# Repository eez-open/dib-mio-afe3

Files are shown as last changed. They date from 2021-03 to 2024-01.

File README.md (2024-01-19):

### Ownership and License
The contributors are listed in CONTRIB.TXT.

Licenses | OSHWA UID
--|--
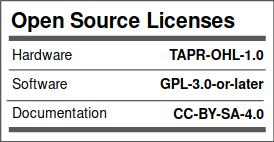
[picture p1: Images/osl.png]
osl
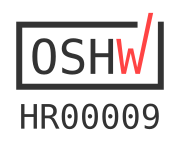
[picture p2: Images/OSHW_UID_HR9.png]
OSHW-HR000009 (https://certification.oshwa.org/hr000009.html)
 | 

### Overview

The [EEZ DIB](https://github.com/eez-open/modular-psu) 4-channel Hi-voltage/Hi-current AFE for [MIO168](https://github.com/eez-open/dib-mio168) module with two isolated inputs for voltage and current measurements.

### Feature list
* [ADS131E04](https://www.ti.com/product/ADS131E04) 24-bit 4-channel simultaneous sampling ADC with SPI
* AIN#1: Hi-voltage isolated (floated) input featuring 2 measurement ranges (±50 V, ±450 V)
* AIN#2: Hi-current isolated (floated) input featuring 2 measurement ranges (±1 A, ±10 A)
* AIN#3: Hi-voltage input featuring 3 measurement ranges (±2.4 V, ±48 V, ±240 V)
* AIN#4: Hi-current input featuring 3 measurement ranges (±24 mA, ±1.2 A, ±10 A), share common GND with AIN#3
* Latching relays for lower continuous power consumption
* Fused current inputs
* On-board ±2.5 V low noise LDOs
* Optional external voltage reference
* Dimensions: 132 x 68.5 mm, 4-layer PCB

### r1B4 prototype 3D model

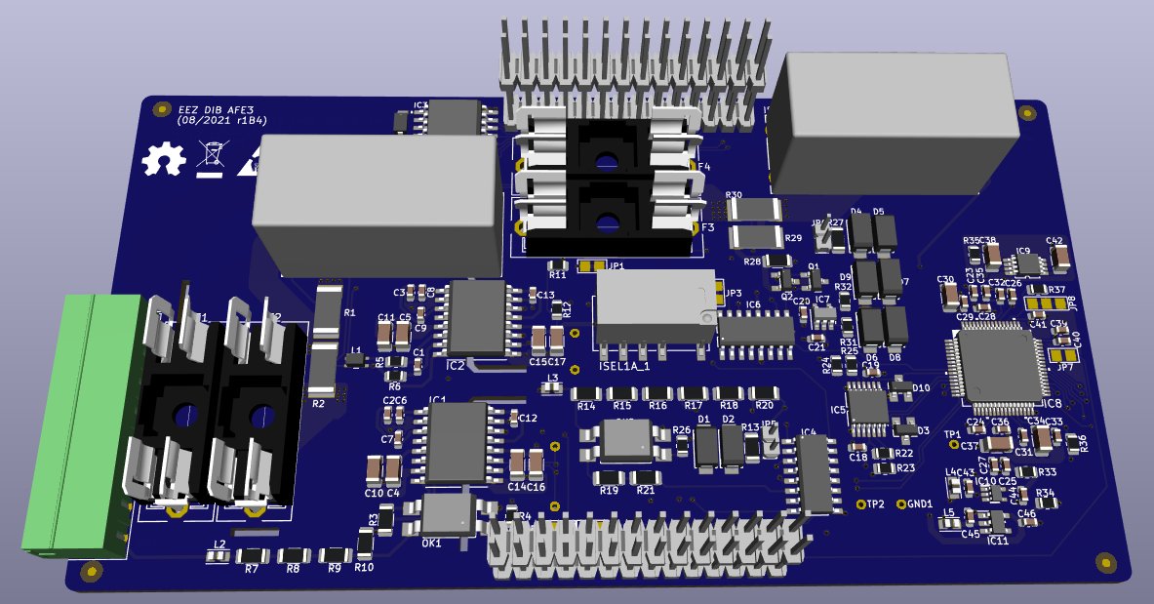
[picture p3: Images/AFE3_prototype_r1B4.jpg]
prototype


### KiCad project (v7 or newer)

* [AFE3 r1B4](https://github.com/eez-open/dib-mio-afe3/tree/master/EDA%20files/KiCad)

All symbols, footprints and 3D models used in the project can be found in the [EEZ-DIB Library](https://github.com/eez-open/eez-kicad-libraries) plugin for KiCad.

### Bill of materials

* [Download](https://github.com/eez-open/dib-mio-afe3/tree/master/EDA%20files/KiCad/bom/ibom.html) as raw file _Interactive BOM_ (ibom.html) and open it locally in your browser.

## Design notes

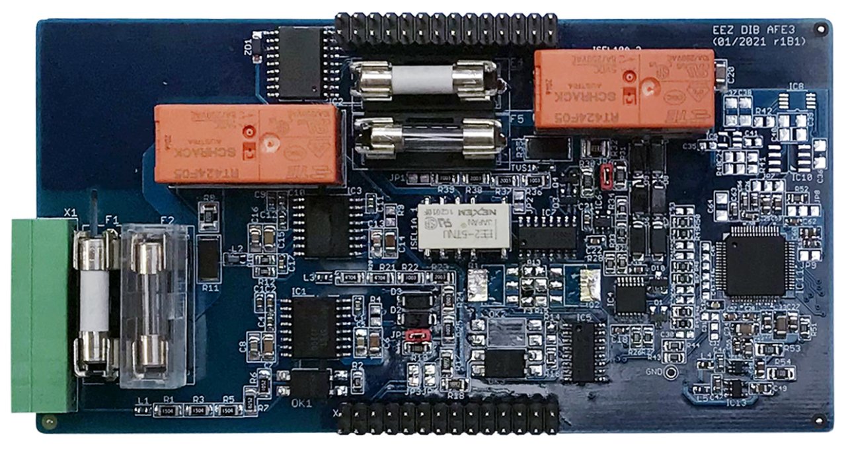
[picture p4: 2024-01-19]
Images/AFE3_prototype_r1B1.jpg

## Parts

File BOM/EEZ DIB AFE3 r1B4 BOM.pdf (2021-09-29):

EEZ DIB AFE3 BOM (r1B4, 2021-05-17)
Project source code at https://github.com/eez-open/modular-psu
Farnell / Element14 # Unit price Qty Part name Package Reference designator Code Part Number MOQ € | Digi-Key Unit price Part Number MOQ € | Mouser Unit price Part Number MOQ €
| | 80-C0603C105K4R
MC0603B822K500 CT | | 603-CC603KRX7R9B B822
| | 80-C0603C102J5RA C
CL21B106KOQNN NE | | 810-CGA4J1X7S1C1 06KA
| | 963-TMK212B7105K G-T
C3, C4, C11, C12, C18, C19, C0603C104K4RAC C21, C22, C26, C28, C46, 7081 C47, C55, C56, C57, C58, C61, C62, C63 | | 80-C0603C104M4R
| | 603-CC121KKX7R8B B226
C1206C102M5RA CTU | | 710-885012208075
| | CL31B105KBHN FNE
C1206C104K5RAC TU | 399-C1206C104K5R AC7800CT-ND | 80-C1206C104K5R ACLR
1 | 2 1u | 0603, 16V | C1, C9 | 3013421 | 0,026 10 | 1276-1019-1-ND | 0,039 | 10 | 0,036 10
2 | 1 8n2 | 0603 | C17 | 1759101 | 0,038 10 | 311-1811-1-ND | 0,060 | 10 | 0,032 10
3 | 2 1n | 0603 | C2, C10 | 2627426 | 0,009 10 | 1276-1018-1-ND | 0,026 | 10 | 0,021 10
4 | 3 10u | 1206 | C20, C34, C64 | 3013485 | 0,262 10 | 1276-2872-1-ND | 0,207 | 10 | 0,144 | 1
5 | 8 1u | 0805 | 2495193 | 885012207078 | 0,139 | 5 | 1276-1066-1-ND | 0,070 | 10 | 0,050 10
6 | 19 100n | 0603 | 2522597 | 0,073 10 | 490-4774-1-ND | 0,090 100 | 0,085 100
7 | 1 22u | 1206 | C33 | 2320935 | 1,490 | 1 | 1276-3373-1-ND | 0,369 | 10 | 0,777 10
8 | 4 1n | 1206, 50V | C5, C8, C13, C16 | 2773295 | 0,059 10 | 732-8115-1-ND | 0,071 | 10 | 0,073 10
9 | 2 1u | 1206, 50V | C6, C14 | 3013524 | 0,144 | 5 | 1276-3091-1-ND | 0,092 | 10 | 0,051 10
10 | 2 100n | 1206, 50V | C7, C15 | 1414715 | 0,053 10 | 0,066 | 10 | 0,045 10
11 | 2 BAV199,235 | D1, D10 | 2319137 | BAV199,215 | 0,185 | 5 | 1727-6382-1-ND | 0,145 | 10 | 771-BAV199235 | 0,146 10
12 | 8 SA2M-E3/61T | SMA | 2335163 | SA2M-E3/61T | 0,261 10 | 0,223 | 10 | 78-CSA2M-E3/H | 0,202 10
13 | 4 ZH32 | F1, F2, F4, F5 | - | - | -
14 | 1 SN005-60 | 1206 | F3 | 3103210 | 1206L005/60WR | 0,771 | 1 | F8129CT-ND | 0,460 | 1 | 0,440 | 1
15 | 1 AMC3330QDWERQ1 | | IC1 | - | | | | | 8,980 | 1 | 9,750 | 1
16 | 1 ADS131E04IPAGR | TQFP-64 | IC11 | 3123346 | ADS131E04IPAG | 13,450 | 1 | 296-34885-1-ND | 7,560 | 1 | 8,430 | 1
17 | 1 TPS71725DCKR | SC70-5 | IC12 | 2348004 | TPS71725DCKR . | 0,982 | 1 | 296-21525-1-ND | 0,890 | 1 | 0,889 | 1
18 | 1 TPS72325DBVR | SOT-23-5 | IC13 | 3007843 | TPS72325DBVR | 2,690 | 1 | 296-39479-1-ND | 2,300 | 1 | 2,310 | 1
19 | 1 ULN2803ADWR | SOIC-18 | IC2 | 3125103 | ULN2803ADWR | 1,120 | 5 | 296-15777-1-ND | 1,090 | 1 | 1,090 | 1
20 | 1 AMC3301DWER | SOIC-16 Wide | IC3 | - | | | | | 9,340 | 1 | 9,220 | 1

CL10B105MO8NN
WC

MC0603B102K250
CT

C23, C25, C27, C48, C49,
C54, C59, C60

MC1210X226K250
CT

CL31B105KBHNN
NE

D2, D3, D4, D5, D6, D7, D8, D9

CSA2M-E3/IGICT-ND
THT; 20x5mm fuse holder
| 576-1206L005/60WR
AMC3330DWER CT-ND | 595-AMC3330DWE
| 595-ADS131E04IPA GR
| 595-TPS71725DCKR
| 595-TPS72325DBVR
| 595-ULN2803ADWR
296-AMC3301QDWE RQ1CT-ND | 595-AMC3301DWER
SOIC-16 Wide | 296-

# Qty Part name | RS Components | TME | Price calculation for 1 set

Unit price Code Part Number MOQ € | Unit price Code / Part Number MOQ € | THT SMD | | Line Cost €

1 2 1u

2 1 8n2

3 2 1n

4 3 10u

5 8 1u

6 19 100n

7 1 22u

8 4 1n

9 2 1u

10 2 100n

11 2 BAV199,235
12 8 SA2M-E3/61T

13 4 ZH32
14 1 SN005-60

15 1 AMC3330QDWERQ1

16 1 ADS131E04IPAGR

17 1 TPS71725DCKR

18 1 TPS72325DBVR

19 1 ULN2803ADWR

20 1 AMC3301DWER

144-7375 | 0,029 100 | CL10B105KO8NNNC | 0,014 100 | 2 | TME | 0,014 € | 2 | 0,027
- | | C0603C822K5RACTU | 0,026 100 | 1 | TME | 0,026 € | 1 | 0,026
135-6565 | 0,014 100 | | 0,010 100 | 2 | Farnell | 0,009 € | 2 | 0,018
184-3969 | 0,233 50 | CL21A106KOQNNNG | 0,034 100 | 3 | TME | 0,034 € | 3 | 0,103
378-665 | 0,038 25 | | 0,014 100 | 8 | TME | 0,014 € | 8 | 0,116
264-4630 | 0,035 25 | CL10B104KA8NNNC | 0,098 100 | 19 | RS | 0,035 € 19 | 0,665
766-1182 | 0,343 10 | CL32A226KAJNNNE | 0,158 10 | 1 | TME | 0,158 € | 1 | 0,158
669-8420 | 0,102 25 | 0,027 100 | 4 | TME | 0,027 € | 4 | 0,110
766-1141 | 0,052 100 | CC1206KKX7R9105 | 0,047 100 | 2 | TME | 0,047 € | 2 | 0,095
391-214 | 0,082 50 | 1206B104K500CT | 0,019 100 | 2 | TME | 0,019 € | 2 | 0,038
751-3437 BAV199DW-7-F | 0,232 25 | BAV199.215 | 0,035 20 | 2 | TME | 0,035 € | 2 | 0,070
812-9275 SA2M-E3/5AT | 0,116 100 | SA2M-E3/61T | 0,050 50 | 8 | TME | 0,050 € | 8 | 0,397
- | ZH32 | 0,228 | 5 | 4 | TME | 0,228 € | 4 | 0,912
- | SN005-60 | 0,075 10 | 1 | TME | 0,075 € | 1 | 0,075
- | | | - | | | 1 | Digikey | 8,980 € | 1 | 8,980
817-5705 | 6,050 | 1 | - | | | 1 | RS | 6,050 € | 1 | 6,050
- | | | - | | | 1 | Mouser | 0,889 € | 1 | 0,889
- | | | - | | | 1 | Digikey | 2,300 € | 1 | 2,300
646-6311 ULN2803ADW | 1,336 | 1 | ULN2803ADWR | 0,866 | 1 | 1 | TME | 0,866 € | 1 | 0,866
- | | | - | | | 1 | Mouser | 9,220 € | 1 | 9,220

Best
Supplier

Lowest
unit price
€

Order
Qty

CGA3E1X7R1C
105M080AC

06031C102KAZ
2A

VJ0603Y102KXACW1 BC

| EMK212BB7106 MG-T
| | VJ0805Y105KXXTW1 BC
| C0603C104K4R ACTU

08052R104K8B
B

CL32A226KAJN
NNE

CC1206KRX7R9
BB102

CL31B102KBCNNNC

CL31B105KBHN
NNF
12065C104KAT
2A

ADS131E04IPA
G

# Qty Part name Package Reference designator Code Part Number MOQ € | Part Number Unit price MOQ € | Part Number Unit price MOQ Unit price €

| | 579-MCP6004T-I/ST
| DG212BDY-T1-E3CT-ND | 781-DG212BDY-T1-E3
| MCP6001RT-I/OTCT-ND | 579-MCP6001RT-I/OT

THT; DPDT Latching relay

21 | 1 MCP6004T-I/ST | TSSOP-14 | IC4 | - | | | | - | | | | 0,373 | 1
22 | 2 DG212BDY-T1-E3 | SOIC-16 | IC5, IC7 | 1469429 | DG212BDY-T1-E3 | 1,820 | 1 | | 1,550 | 1 | | 1,470 | 1
23 | 1 MCP6001RT-I/OT | SOT-23-5 | IC6 | 8540829 | MCP6001RT-I/OT | 0,219 | 1 | | 0,200 | 1 | | 0,203 | 1
24 | 2 RT424F05 | | ISEL10A_1, ISEL10A_2 | 3406968 | RT424F05 | 6,450 | 1 | PB2024-ND | 6,370 | 1 | 655-5-1393243-2 | 6,380 | 1
25 | 1 EE2-5TNU-L | | ISEL1A_1 | 2360813 | EE2-5TNU-L | 1,900 | 1 | 399-11021-1-ND | 2,110 | 1 | 80-EE2-5TNU-L | 2,120 | 1
26 | 2 MLZ1608N100LT000 | 0603 | L1, L3 | 2564062 | 0,167 10 | 445-6755-1-ND | 0,111 | 10 | 0,086 10
27 | 1 DLW21SN371SQ2L | 0805 | L2 | - | 490-5141-1-ND | 0,410 | 10 | 0,484 10
28 | 2 BLM18AG102SH1D | 0603 | L1, L2 | 3471092 | 0,032 10 | 490-7809-1-ND | 0,070 | 10 | 0,051 10
29 | 3 VOR1142B4 | SMD DIP-4 | OK1, OK2, OK3 | 2889672 | VOR1142B4 | 1,660 | 1 | VOR1142B4-ND | 1,420 | 1 | 78-VOR1142B4 | 1,420 | 1
30 | 2 CPC3902ZTR | SOT-223 | Q1, Q2 | - | | | | CLA4156-1-ND | 0,570 | 1 | | 0,576 | 1
31 | 2 BSS214NH6327XTSA1 SOT-23 | Q3, Q4 | 2480650 | 0,408 | 5 | 0,255 | 10 | 0,224 10
32 | 3 1M5 0.1% | 1206 R1, R3, R5 | - | 0,351 | 10 | 0,263 10
33 | 5 10R | 0805 | R10, R12, R13, R53, R54 | 2447556 | 0,009 10 | 0,029 | 10 | 0,012 10
34 | 2 GMR100HTBFA10L0 | | R11, R35 | 2808330 | | 1,130 | 5 | 511-1686-1-ND | 1,350 | 1 | | 1,080 | 1
35 | 1 20R | R15 | - | 311-2930-1-ND | 0,202 | 10 | 0,257 10
36 | 2 49K9 | 1206 | R17, R18 | 2908458 | 0,040 10 | 0,068 | 10 | 0,013 10
37 | 3 100K | 1206 | R19, R31, R36 | 2447551 | 0,010 10 | 0,024 | 10 | 0,040 10
38 | 3 470R | 0805 | R2, R14, R16 | 1099798 | WCR0805-470RFI | 0,019 10 | 0,039 | 10 | 0,041 10
39 | 2 4M7 0.1% | 1206 | R20, R21 | - | 408-2037-1-ND | 0,413 | 10 | 0,356 10
40 | 3 100K 0.1% | 1206 | R22, R25, R39 | 1717738 | ERA8AEB101V | 0,482 10 | 0,346 | 10 | 0,226 10
41 | 4 200K 0.1% | 1206 | R23, R24, R37, R38 | 1841801 | ERA8AEB204V | 0,468 10 | 0,355 | 10 | 0,226 10

DPDT Latching relay, Gull
Wing Lead
MLZ1608N100LT0 00 | 810-MLZ1608N100LT 000
| 81-DLW21SN371SQ 2L
BLM18AG102SH1 D | 81-BLM18AG102SH 1D
| | 849-CPC3902ZTR
| BSS214NH6327 XTSA1CT-ND | 726-BSS214NH6327
| RG3216P-1504-B-T1 | 754-RG3216P-1504B-T1
| 2019-RK73H2ATTD10 R0FCT-ND | 652-CR0805FX-10R0ELF
2512, low TCR (max. GMR100HTBFA10 ±25ppm/°C) L0 | | 755-GMR100HTBFA1 0L0
| | 652-CRT1206BY20R 0ELF
CR1206-FX-4992ELF | RNCP1206FTD4 9K9CT-ND | 791-MR12X4992FTL
| RMCF0805FT10 0KCT-ND | 71-CRCW0805100K FKEAC
| 311-470CRCT-ND | 71-CRCW0805470R FKEB
| | 754-RG3216P-4704B-T1
| RG32P100KBCT -ND | 754-RG3216P-1003-BT5

BSS214NH6327XT
SA1

MCWR08X10R0FT
L

1206, low TCR (max.
±25ppm/°C)

MCWR08X1003FT
L

RG32P200KBCT
-ND

754-RG3216P-2003-BT5

# Qty Part name

21 1 MCP6004T-I/ST

22 2 DG212BDY-T1-E3

23 1 MCP6001RT-I/OT

24 2 RT424F05
25 1 EE2-5TNU-L

26 2 MLZ1608N100LT000

27 1 DLW21SN371SQ2L

28 2 BLM18AG102SH1D

29 3 VOR1142B4
30 2 CPC3902ZTR

31 2 BSS214NH6327XTSA1

32 3 1M5 0.1%

33 5 10R

34 2 GMR100HTBFA10L0

35 1 20R

36 2 49K9

37 3 100K

38 3 470R

39 2 4M7 0.1%

40 3 100K 0.1%

41 4 200K 0.1%

Code Part Number MOQ € | Code / Part Number Unit price MOQ € | THT SMD | Line Cost € Unit price

Best
Supplier

Lowest
unit price
€

Order
Qty
- | - | 1 | Mouser | 0,373 € | 1 | 0,373
710-4780 | 1,630 | 5 | - | 2 | Mouser | 1,470 € | 2 | 2,940
667-4335 | 0,203 20 | MCP6001RT-I/OT | 0,172 10 | 1 | TME | 0,172 € | 1 | 0,172
164-7553 RT424F05 | 6,485 | 1 | 5-1393243-2 | 2,500 | 2 | 2 | TME | 2,500 € | 2 | 5,000
870-5517 EE2-5TNU-L | 1,987 | 1 | - | 1 | Farnell | 1,900 € | 1 | 1,900
- | - | 2 | Mouser | 0,086 € | 2 | 0,172
724-1674 | 0,490 10 | DLW21SN371SQ2L | 0,234 10 | 1 | TME | 0,234 € | 1 | 0,234
839-0803 | 0,025 100 | BLM18AG102SH1D | 0,016 50 | 2 | TME | 0,016 € | 2 | 0,031
180-7266 VOR1142B4 | 1,416 | 5 | - | 3 | RS | 1,416 € | 3 | 4,248
- | CPC3902ZTR | 0,310 | 5 | 2 | TME | 0,310 € | 2 | 0,620
827-0058 | 0,107 100 | 0,070 10 | 2 | TME | 0,070 € | 2 | 0,140
- | - | 3 | Mouser | 0,263 € | 3 | 0,789
740-8987 | 0,065 50 | 0805S8J0111T5E | 0,013 100 | 5 | Farnell | 0,009 € | 5 | 0,043
- | - | 2 | Mouser | 1,080 € | 2 | 2,160
- | - | 1 | Digikey | 0,202 € | 1 | 0,202
679-2174 | 0,039 50 | RC1206FR-0749K9 | 0,029 100 | 2 | Mouser | 0,013 € | 2 | 0,026
223-0691 CRG0805F100K | 0,028 50 | 0805S8F1003T5E | 0,015 100 | 3 | Farnell | 0,010 € | 3 | 0,029
223-0376 CRG0805F470R | 0,021 50 | RC0805FR-07470R | 0,022 100 | 3 | Farnell | 0,019 € | 3 | 0,057
- | - | 2 | Mouser | 0,356 € | 2 | 0,712
669-6626 ERA8AEB104V | 0,608 | 5 | AR06BTCV1003 | 0,127 10 | 3 | TME | 0,127 € | 3 | 0,380
828-0715 ERA8AEB204V | 0,608 | 5 | AR06BTCV2003 | 0,127 10 | 4 | TME | 0,127 € | 4 | 0,506

DG212BDY-T1-
E3
MCP6001RT-I/OT

DLW21SN371S
Q2L

BLM18AG102S
H1D

BSS214NH6327
XTSA1

BSS214NH6327XTSA
1

CR0805-FX-10R0ELF

CRCW120649K
9FKEA

# Qty Part name Package Reference designator Code Part Number MOQ € | Part Number Unit price MOQ € | Part Number Unit price MOQ Unit price €

MCWR08X3300FT L | | 279-CRGCQ0805F33 0R
| 311-10.0KCRCT-ND | 603-RC0805FR-0710KL
1206, low TCR (max. ±25ppm/°C) | 13-RT1206BRD073 3RLCT-ND | 603-RT1206BRD073 3RL
| RC0805FR-071KL | 603-RC0805FR-071KL
MCWF12R1052BT L | | 754-RG3216P-1052-BT5
| RQ73C2B82K5B TD | 754-RG3216P-8252-BT5
2512, low TCR (max. ±25ppm/°C) | | 755-GMR100HTBFIR 022
| | 771-PESD12VL1BA-T/R
THT, 8-pin 3.81mm terminal block header, male pins | | 710-691322310008
42 | 2 330R | 0805 | R26, R29 | 2447638 | 0,007 10 | A106061CT-ND | 0,038 | 10 | 0,036 10
43 | 5 10K | 0805 | R27, R28, R33, R51, R52 | 9237755 | 0,022 10 | 0,039 | 10 | 0,014 10
44 | 1 33R | | R30 | - | | | | 0,393 | 10 | 0,266 10
45 | 1 1K | R34 | 1099800 | WCR0805-1K0FI | 0,019 10 | 0,039 | 10 | 0,015 10
46 | 1 10K5 0.1% | 1206 | R6 | 2338266 | 0,249 10 | A140954CT-ND | 0,621 | 10 | 0,226 10
47 | 1 82K5 0.1% | 1206 | R7 | 2338651 | 0,249 10 | 0,621 | 10 | 0,226 10
48 | 2 GMR100HTBFIR022 | R8, R32 | - | 511-1688-1-ND | 1,090 | 10 | 1,250 | 1
49 | 1 PESD12VL1BA,115 | SOD-323 | TVS1 | 8737363 | 0,365 | 5 | 1727-3808-1-ND | 0,320 | 10 | 0,296 10
50 | 1 691322310008 | X1 | - | 732-2093-ND | 1,390 | 1 | 1,400 | 1
51 | 2 P125-2214A0BS230A1 | X2, X3 | - | - | -
52 | 1 MMSZ5230BT1G | SOD-123 | ZD1 | 1431272 | MMSZ5230BT1G | 0,177 10 | 0,148 | 10 | 0,170 10

Not installed
2 N.C. | 1206 | C24, C35
1 N.C. | IC8
1 N.C. | SOT-23-5 | IC9
5 N.C. | R-EU_R0805 | R4, R9, R40, R41, R42

Related parts and accessories
2 ZKSS-10A
2 ZKSS-1.25A
2 DS1025-01-1*2P8BV1-B THT; | JP5, JP6 | - | - | -
2 JUMPER-2.0/R | JP5, JP6 | - | - | -
1 691304100008 | - | 277-12329-ND | 7,410 | 1 | 651-1748037 | 7,440 | 1

Custom made components
1 | JLCPCB.com | -

RC0805FR-0710KL

MCWF12R8252BT
L

PESD12VL1BA,11
5

THT; 28-pin 0.1” board-toboard (Producer: DONG
GUAN YLIES PRECISE
CONNECTOR CO.,LTD)
MMSZ5230BT1G
OSCT-ND

863-
MMSZ5230BT1G

8-pin 3.81mm push-in
connector

PCB 4-layer 141.5 x 68.5
mm

# Qty Part name

42 2 330R

43 5 10K

44 1 33R

45 1 1K

46 1 10K5 0.1%

47 1 82K5 0.1%

48 2 GMR100HTBFIR022

49 1 PESD12VL1BA,115

50 1 691322310008

51 2 P125-2214A0BS230A1

52 1 MMSZ5230BT1G

Not installed
2 N.C.
1 N.C.
1 N.C.
5 N.C.

Related parts and accessories 2 ZKSS-10A
2 ZKSS-1.25A
2 DS1025-01-1*2P8BV1-B
2 JUMPER-2.0/R
1 691304100008

Custom made components
1 PCB 4-layer 141.5 x 68.5 mm
Code Part Number MOQ € | Code / Part Number Unit price MOQ € | THT SMD | Line Cost € Unit price

Best
Supplier

Lowest
unit price
€

Order
Qty
223-0354 CRG0805F330R | 0,040 50 | 0805S8F3300T5E | 0,014 100 | 2 | Farnell | 0,007 € | 2 | 0,014
125-1189 CRG0805F10K | 0,002 100 | RC0805FR-0710K | 0,022 100 | 5 | RS | 0,002 € | 5 | 0,010
- | AR06BTCV0330 | 0,132 10 | 1 | TME | 0,132 € | 1 | 0,132
223-0427 CRG0805F1K0 | 0,017 50 | RC0805FR-071K | 0,022 100 | 1 | Mouser | 0,015 € | 1 | 0,015
- | - | 1 | Mouser | 0,226 € | 1 | 0,226
- | - | 1 | Mouser | 0,226 € | 1 | 0,226
- | - | 2 | Digikey | 1,090 € | 2 | 2,180
508-024 | 0,294 20 | PESD12VL1BA.115 | 0,126 | 5 | 1 | TME | 0,126 € | 1 | 0,126
824-6661 691322310008 | 1,470 | 1 | 15EDGRC3.81-08P | 0,662 | 1 | 1 | TME | 0,662 € | 1 | 0,662
- | - | 2 | -
545-3033 | 0,173 20 | MMSZ5230BT1G | 0,033 25 | 1 | TME | 0,033 € | 1 | 0,033
9 | 77 | 55,47 €
| ZKSS-10A | 0,459 10 | | TME | 0,459 € | 2 | 0,918
| ZKSS-1.25A | 0,312 10 | | TME | 0,312 € | 2 | 0,624
- | ZL303-02P | 0,013 50 | 2 | TME | 0,013 € | 2 | 0,025
- | JUMPER-2.0/R | 0,044 20 | | TME | 0,044 € | 2 | 0,087
185-4361 691304100008 | 8,900 | 1 | Digikey | 7,410 € | 1 | 7,410
| | | | | | | 9,06 €
JLCPCB | 8,796 € | 1 | 8,796
| | | 8,80 €

PESD12VL1BA,
115

MMSZ5230BT1
G

Qty | Part name | Package | Reference designator | Code | Part Number | MOQ | Part Number | MOQ | Part Number | MOQ Unit price
€

Unit price
€

Unit price
€

All prices are net prices (without VAT)

All resistors are 1% 0805 and all capacitors are X7R 0805 if not otherwise specified.
For small quantities, consider ordering specialized chips at store.ti.com for better prices and availability.

Please note that BOM does not contain ordering number for parts on reels or that which includes re-reeling fee. Take also into account that total cost is higher because min. quantity (MOQ) for many parts is larger then what is needed for single unit.

# Qty Part name

Code Part Number MOQ € | Code / Part Number Unit price MOQ € | THT SMD | Line Cost € Unit price

Best
Supplier

Lowest
unit price
€

Order
Qty

Total 73,33 €

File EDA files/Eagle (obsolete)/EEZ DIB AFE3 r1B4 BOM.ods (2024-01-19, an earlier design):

 |  |  |  |  | Farnell / Element14 |  |  |  | Digi-Key |  |  | Mouser |  |  | RS Components |  |  |  | TME |  |  |  |  | Price calculation for 1 set
# | Qty | Part name | Package | Reference designator | Code | Part Number | Unit price € | MOQ | Part Number | Unit price € | MOQ | Part Number | Unit price € | MOQ | Code | Part Number | Unit price € | MOQ | Code / Part Number | Unit price € | MOQ | THT | SMD | Best Supplier | Lowest unit price € | Order Qty | Line Cost €
1 | 2 | 1u | 0603, 16V | C1, C9 | 3013421 | CL10B105MO8NNWC | 0,026 | 10 | 1276-1019-1-ND | 0,039 | 10 | 80-C0603C105K4R | 0,036 | 10 | 144-7375 | CGA3E1X7R1C105M080AC | 0,029 | 100 | CL10B105KO8NNNC | 0,014 | 100 |  | 2 | TME | 0,014 € | 2 | 0,027
2 | 1 | 8n2 | 0603 | C17 | 1759101 | MC0603B822K500CT | 0,038 | 10 | 311-1811-1-ND | 0,060 | 10 | 603-CC603KRX7R9BB822 | 0,032 | 10 | - |  |  |  | C0603C822K5RACTU | 0,026 | 100 |  | 1 | TME | 0,026 € | 1 | 0,026
3 | 2 | 1n | 0603 | C2, C10 | 2627426 | MC0603B102K250CT | 0,009 | 10 | 1276-1018-1-ND | 0,026 | 10 | 80-C0603C102J5RAC | 0,021 | 10 | 135-6565 | 06031C102KAZ2A | 0,014 | 100 | VJ0603Y102KXACW1BC | 0,010 | 100 |  | 2 | Farnell | 0,009 € | 2 | 0,018
4 | 3 | 10u | 1206 | C20, C34, C64 | 3013485 | CL21B106KOQNNNE | 0,262 | 10 | 1276-2872-1-ND | 0,207 | 10 | 810-CGA4J1X7S1C106KA | 0,144 | 1 | 184-3969 | EMK212BB7106MG-T | 0,233 | 50 | CL21A106KOQNNNG | 0,034 | 100 |  | 3 | TME | 0,034 € | 3 | 0,103
5 | 8 | 1u | 0805 | C23, C25, C27, C48, C49, C54, C59, C60 | 2495193 | 885012207078 | 0,139 | 5 | 1276-1066-1-ND | 0,070 | 10 | 963-TMK212B7105KG-T | 0,050 | 10 | 378-665 | 08052R104K8BB | 0,038 | 25 | VJ0805Y105KXXTW1BC | 0,014 | 100 |  | 8 | TME | 0,014 € | 8 | 0,116
6 | 19 | 100n | 0603 | C3, C4, C11, C12, C18, C19, C21, C22, C26, C28, C46, C47, C55, C56, C57, C58, C61, C62, C63 | 2522597 | C0603C104K4RAC7081 | 0,073 | 10 | 490-4774-1-ND | 0,090 | 100 | 80-C0603C104M4R | 0,085 | 100 | 264-4630 | C0603C104K4RACTU | 0,035 | 25 | CL10B104KA8NNNC | 0,098 | 100 |  | 19 | RS | 0,035 € | 19 | 0,665
7 | 1 | 22u | 1206 | C33 | 2320935 | MC1210X226K250CT | 1,490 | 1 | 1276-3373-1-ND | 0,369 | 10 | 603-CC121KKX7R8BB226 | 0,777 | 10 | 766-1182 | CL32A226KAJNNNE | 0,343 | 10 | CL32A226KAJNNNE | 0,158 | 10 |  | 1 | TME | 0,158 € | 1 | 0,158
8 | 4 | 1n | 1206, 50V | C5, C8, C13, C16 | 2773295 | C1206C102M5RACTU | 0,059 | 10 | 732-8115-1-ND | 0,071 | 10 | 710-885012208075 | 0,073 | 10 | 669-8420 | CC1206KRX7R9BB102 | 0,102 | 25 | CL31B102KBCNNNC | 0,027 | 100 |  | 4 | TME | 0,027 € | 4 | 0,110
9 | 2 | 1u | 1206, 50V | C6, C14 | 3013524 | CL31B105KBHNNNE | 0,144 | 5 | 1276-3091-1-ND | 0,092 | 10 | CL31B105KBHNFNE | 0,051 | 10 | 766-1141 | CL31B105KBHNNNF | 0,052 | 100 | CC1206KKX7R9105 | 0,047 | 100 |  | 2 | TME | 0,047 € | 2 | 0,095
10 | 2 | 100n | 1206, 50V | C7, C15 | 1414715 | C1206C104K5RACTU | 0,053 | 10 | 399-C1206C104K5RAC7800CT-ND | 0,066 | 10 | 80-C1206C104K5RACLR | 0,045 | 10 | 391-214 | 12065C104KAT2A | 0,082 | 50 | 1206B104K500CT | 0,019 | 100 |  | 2 | TME | 0,019 € | 2 | 0,038
11 | 2 | BAV199,235 |  | D1, D10 | 2319137 | BAV199,215 | 0,185 | 5 | 1727-6382-1-ND | 0,145 | 10 | 771-BAV199235 | 0,146 | 10 | 751-3437 | BAV199DW-7-F | 0,232 | 25 | BAV199.215 | 0,035 | 20 |  | 2 | TME | 0,035 € | 2 | 0,070
12 | 8 | SA2M-E3/61T | SMA | D2, D3, D4, D5, D6, D7, D8, D9 | 2335163 | SA2M-E3/61T | 0,261 | 10 | CSA2M-E3/IGICT-ND | 0,223 | 10 | 78-CSA2M-E3/H | 0,202 | 10 | 812-9275 | SA2M-E3/5AT | 0,116 | 100 | SA2M-E3/61T | 0,050 | 50 |  | 8 | TME | 0,050 € | 8 | 0,397
13 | 4 | ZH32 | THT; 20x5mm fuse holder | F1, F2, F4, F5 | - |  |  |  | - |  |  | - |  |  | - |  |  |  | ZH32 | 0,228 | 5 | 4 |  | TME | 0,228 € | 4 | 0,912
14 | 1 | SN005-60 | 1206 | F3 | 3103210 | 1206L005/60WR | 0,771 | 1 | F8129CT-ND | 0,460 | 1 | 576-1206L005/60WR | 0,440 | 1 | - |  |  |  | SN005-60 | 0,075 | 10 |  | 1 | TME | 0,075 € | 1 | 0,075
15 | 1 | AMC3330QDWERQ1 | SOIC-16 Wide | IC1 | - |  |  |  | 296-AMC3330DWERCT-ND | 8,980 | 1 | 595-AMC3330DWE | 9,750 | 1 | - |  |  |  | - |  |  |  | 1 | Digikey | 8,980 € | 1 | 8,980
16 | 1 | ADS131E04IPAGR | TQFP-64 | IC11 | 3123346 | ADS131E04IPAG | 13,450 | 1 | 296-34885-1-ND | 7,560 | 1 | 595-ADS131E04IPAGR | 8,430 | 1 | 817-5705 | ADS131E04IPAG | 6,050 | 1 | - |  |  |  | 1 | RS | 6,050 € | 1 | 6,050
17 | 1 | TPS71725DCKR | SC70-5 | IC12 | 2348004 | TPS71725DCKR . | 0,982 | 1 | 296-21525-1-ND | 0,890 | 1 | 595-TPS71725DCKR | 0,889 | 1 | - |  |  |  | - |  |  |  | 1 | Mouser | 0,889 € | 1 | 0,889
18 | 1 | TPS72325DBVR | SOT-23-5 | IC13 | 3007843 | TPS72325DBVR | 2,690 | 1 | 296-39479-1-ND | 2,300 | 1 | 595-TPS72325DBVR | 2,310 | 1 | - |  |  |  | - |  |  |  | 1 | Digikey | 2,300 € | 1 | 2,300
19 | 1 | ULN2803ADWR | SOIC-18 | IC2 | 3125103 | ULN2803ADWR | 1,120 | 5 | 296-15777-1-ND | 1,090 | 1 | 595-ULN2803ADWR | 1,090 | 1 | 646-6311 | ULN2803ADW | 1,336 | 1 | ULN2803ADWR | 0,866 | 1 |  | 1 | TME | 0,866 € | 1 | 0,866
20 | 1 | AMC3301DWER | SOIC-16 Wide | IC3 | - |  |  |  | 296-AMC3301QDWERQ1CT-ND | 9,340 | 1 | 595-AMC3301DWER | 9,220 | 1 | - |  |  |  | - |  |  |  | 1 | Mouser | 9,220 € | 1 | 9,220
21 | 1 | MCP6004T-I/ST | TSSOP-14 | IC4 | - |  |  |  | MCP6004T-I/STTR-ND |  |  | 579-MCP6004T-I/ST | 0,373 | 1 | - |  |  |  | MCP6004-I/ST |  |  |  | 1 | Mouser | 0,373 € | 1 | 0,373
22 | 2 | DG212BDY-T1-E3 | SOIC-16 | IC5, IC7 | 1469429 | DG212BDY-T1-E3 | 1,820 | 1 | DG212BDY-T1-E3CT-ND | 1,550 | 1 | 781-DG212BDY-T1-E3 | 1,470 | 1 | 710-4780 | DG212BDY-T1-E3 | 1,630 | 5 | - |  |  |  | 2 | Mouser | 1,470 € | 2 | 2,940
23 | 1 | MCP6001RT-I/OT | SOT-23-5 | IC6 | 8540829 | MCP6001RT-I/OT | 0,219 | 1 | MCP6001RT-I/OTCT-ND | 0,200 | 1 | 579-MCP6001RT-I/OT | 0,203 | 1 | 667-4335 | MCP6001RT-I/OT | 0,203 | 20 | MCP6001RT-I/OT | 0,172 | 10 |  | 1 | TME | 0,172 € | 1 | 0,172
24 | 2 | RT424F05 | THT; DPDT Latching relay | ISEL10A_1, ISEL10A_2 | 3406968 | RT424F05 | 6,450 | 1 | PB2024-ND | 6,370 | 1 | 655-5-1393243-2 | 6,380 | 1 | 164-7553 | RT424F05 | 6,485 | 1 | 5-1393243-2 | 2,500 | 2 | 2 |  | TME | 2,500 € | 2 | 5,000
25 | 1 | EE2-5TNU-L | DPDT Latching relay, Gull Wing Lead | ISEL1A_1 | 2360813 | EE2-5TNU-L | 1,900 | 1 | 399-11021-1-ND | 2,110 | 1 | 80-EE2-5TNU-L | 2,120 | 1 | 870-5517 | EE2-5TNU-L | 1,987 | 1 | - |  |  |  | 1 | Farnell | 1,900 € | 1 | 1,900
26 | 2 | MLZ1608N100LT000 | 0603 | L1, L3 | 2564062 | MLZ1608N100LT000 | 0,167 | 10 | 445-6755-1-ND | 0,111 | 10 | 810-MLZ1608N100LT000 | 0,086 | 10 | - |  |  |  | - |  |  |  | 2 | Mouser | 0,086 € | 2 | 0,172
27 | 1 | DLW21SN371SQ2L | 0805 | L2 | - |  |  |  | 490-5141-1-ND | 0,410 | 10 | 81-DLW21SN371SQ2L | 0,484 | 10 | 724-1674 | DLW21SN371SQ2L | 0,490 | 10 | DLW21SN371SQ2L | 0,234 | 10 |  | 1 | TME | 0,234 € | 1 | 0,234
28 | 2 | BLM18AG102SH1D | 0603 | L1, L2 | 3471092 | BLM18AG102SH1D | 0,032 | 10 | 490-7809-1-ND | 0,070 | 10 | 81-BLM18AG102SH1D | 0,051 | 10 | 839-0803 | BLM18AG102SH1D | 0,025 | 100 | BLM18AG102SH1D | 0,016 | 50 |  | 2 | TME | 0,016 € | 2 | 0,031
29 | 3 | VOR1142B4 | SMD DIP-4 | OK1, OK2, OK3 | 2889672 | VOR1142B4 | 1,660 | 1 | VOR1142B4-ND | 1,420 | 1 | 78-VOR1142B4 | 1,420 | 1 | 180-7266 | VOR1142B4 | 1,416 | 5 | - |  |  |  | 3 | RS | 1,416 € | 3 | 4,248
30 | 2 | CPC3902ZTR | SOT-223 | Q1, Q2 | - |  |  |  | CLA4156-1-ND | 0,570 | 1 | 849-CPC3902ZTR | 0,576 | 1 | - |  |  |  | CPC3902ZTR | 0,310 | 5 |  | 2 | TME | 0,310 € | 2 | 0,620
31 | 2 | BSS214NH6327XTSA1 | SOT-23 | Q3, Q4 | 2480650 | BSS214NH6327XTSA1 | 0,408 | 5 | BSS214NH6327XTSA1CT-ND | 0,255 | 10 | 726-BSS214NH6327 | 0,224 | 10 | 827-0058 | BSS214NH6327XTSA1 | 0,107 | 100 | BSS214NH6327XTSA1 | 0,070 | 10 |  | 2 | TME | 0,070 € | 2 | 0,140
32 | 3 | 1M5 0.1% | 1206 | R1, R3, R5 | - |  |  |  | RG3216P-1504-B-T1 | 0,351 | 10 | 754-RG3216P-1504B-T1 | 0,263 | 10 | - |  |  |  | - |  |  |  | 3 | Mouser | 0,263 € | 3 | 0,789
33 | 5 | 10R | 0805 | R10, R12, R13, R53, R54 | 2447556 | MCWR08X10R0FTL | 0,009 | 10 | 2019-RK73H2ATTD10R0FCT-ND | 0,029 | 10 | 652-CR0805FX-10R0ELF | 0,012 | 10 | 740-8987 | CR0805-FX-10R0ELF | 0,065 | 50 | 0805S8J0111T5E | 0,013 | 100 |  | 5 | Farnell | 0,009 € | 5 | 0,043
34 | 2 | GMR100HTBFA10L0 | 2512, low TCR (max. ±25ppm/°C) | R11, R35 | 2808330 | GMR100HTBFA10L0 | 1,130 | 5 | 511-1686-1-ND | 1,350 | 1 | 755-GMR100HTBFA10L0 | 1,080 | 1 | - |  |  |  | - |  |  |  | 2 | Mouser | 1,080 € | 2 | 2,160
35 | 1 | 20R | 1206, low TCR (max. ±25ppm/°C) | R15 | - |  |  |  | 311-2930-1-ND | 0,202 | 10 | 652-CRT1206BY20R0ELF | 0,257 | 10 | - |  |  |  | - |  |  |  | 1 | Digikey | 0,202 € | 1 | 0,202
36 | 2 | 49K9 | 1206 | R17, R18 | 2908458 | CR1206-FX-4992ELF | 0,040 | 10 | RNCP1206FTD49K9CT-ND | 0,068 | 10 | 791-MR12X4992FTL | 0,013 | 10 | 679-2174 | CRCW120649K9FKEA | 0,039 | 50 | RC1206FR-0749K9 | 0,029 | 100 |  | 2 | Mouser | 0,013 € | 2 | 0,026
37 | 3 | 100K | 1206 | R19, R31, R36 | 2447551 | MCWR08X1003FTL | 0,010 | 10 | RMCF0805FT100KCT-ND | 0,024 | 10 | 71-CRCW0805100KFKEAC | 0,040 | 10 | 223-0691 | CRG0805F100K | 0,028 | 50 | 0805S8F1003T5E | 0,015 | 100 |  | 3 | Farnell | 0,010 € | 3 | 0,029
38 | 3 | 470R | 0805 | R2, R14, R16 | 1099798 | WCR0805-470RFI | 0,019 | 10 | 311-470CRCT-ND | 0,039 | 10 | 71-CRCW0805470RFKEB | 0,041 | 10 | 223-0376 | CRG0805F470R | 0,021 | 50 | RC0805FR-07470R | 0,022 | 100 |  | 3 | Farnell | 0,019 € | 3 | 0,057
39 | 2 | 4M7 0.1% | 1206 | R20, R21 | - |  |  |  | 408-2037-1-ND | 0,413 | 10 | 754-RG3216P-4704B-T1 | 0,356 | 10 | - |  |  |  | - |  |  |  | 2 | Mouser | 0,356 € | 2 | 0,712
40 | 3 | 100K 0.1% | 1206 | R22, R25, R39 | 1717738 | ERA8AEB101V | 0,482 | 10 | RG32P100KBCT-ND | 0,346 | 10 | 754-RG3216P-1003-BT5 | 0,226 | 10 | 669-6626 | ERA8AEB104V | 0,608 | 5 | AR06BTCV1003 | 0,127 | 10 |  | 3 | TME | 0,127 € | 3 | 0,380
41 | 4 | 200K 0.1% | 1206 | R23, R24, R37, R38 | 1841801 | ERA8AEB204V | 0,468 | 10 | RG32P200KBCT-ND | 0,355 | 10 | 754-RG3216P-2003-BT5 | 0,226 | 10 | 828-0715 | ERA8AEB204V | 0,608 | 5 | AR06BTCV2003 | 0,127 | 10 |  | 4 | TME | 0,127 € | 4 | 0,506
42 | 2 | 330R | 0805 | R26, R29 | 2447638 | MCWR08X3300FTL | 0,007 | 10 | A106061CT-ND | 0,038 | 10 | 279-CRGCQ0805F330R | 0,036 | 10 | 223-0354 | CRG0805F330R | 0,040 | 50 | 0805S8F3300T5E | 0,014 | 100 |  | 2 | Farnell | 0,007 € | 2 | 0,014
43 | 5 | 10K | 0805 | R27, R28, R33, R51, R52 | 9237755 | RC0805FR-0710KL | 0,022 | 10 | 311-10.0KCRCT-ND | 0,039 | 10 | 603-RC0805FR-0710KL | 0,014 | 10 | 125-1189 | CRG0805F10K | 0,002 | 100 | RC0805FR-0710K | 0,022 | 100 |  | 5 | RS | 0,002 € | 5 | 0,010
44 | 1 | 33R | 1206, low TCR (max. ±25ppm/°C) | R30 | - |  |  |  | 13-RT1206BRD0733RLCT-ND | 0,393 | 10 | 603-RT1206BRD0733RL | 0,266 | 10 | - |  |  |  | AR06BTCV0330 | 0,132 | 10 |  | 1 | TME | 0,132 € | 1 | 0,132
45 | 1 | 1K |  | R34 | 1099800 | WCR0805-1K0FI | 0,019 | 10 | RC0805FR-071KL | 0,039 | 10 | 603-RC0805FR-071KL | 0,015 | 10 | 223-0427 | CRG0805F1K0 | 0,017 | 50 | RC0805FR-071K | 0,022 | 100 |  | 1 | Mouser | 0,015 € | 1 | 0,015
46 | 1 | 10K5 0.1% | 1206 | R6 | 2338266 | MCWF12R1052BTL | 0,249 | 10 | A140954CT-ND | 0,621 | 10 | 754-RG3216P-1052-BT5 | 0,226 | 10 | - |  |  |  | - |  |  |  | 1 | Mouser | 0,226 € | 1 | 0,226
47 | 1 | 82K5 0.1% | 1206 | R7 | 2338651 | MCWF12R8252BTL | 0,249 | 10 | RQ73C2B82K5BTD | 0,621 | 10 | 754-RG3216P-8252-BT5 | 0,226 | 10 | - |  |  |  | - |  |  |  | 1 | Mouser | 0,226 € | 1 | 0,226
48 | 2 | GMR100HTBFIR022 | 2512, low TCR (max. ±25ppm/°C) | R8, R32 | - |  |  |  | 511-1688-1-ND | 1,090 | 10 | 755-GMR100HTBFIR022 | 1,250 | 1 | - |  |  |  | - |  |  |  | 2 | Digikey | 1,090 € | 2 | 2,180
49 | 1 | PESD12VL1BA,115 | SOD-323 | TVS1 | 8737363 | PESD12VL1BA,115 | 0,365 | 5 | 1727-3808-1-ND | 0,320 | 10 | 771-PESD12VL1BA-T/R | 0,296 | 10 | 508-024 | PESD12VL1BA,115 | 0,294 | 20 | PESD12VL1BA.115 | 0,126 | 5 |  | 1 | TME | 0,126 € | 1 | 0,126
50 | 1 | 691322310008 | THT, 8-pin 3.81mm terminal block header, male pins | X1 | - |  |  |  | 732-2093-ND | 1,390 | 1 | 710-691322310008 | 1,400 | 1 | 824-6661 | 691322310008 | 1,470 | 1 | 15EDGRC3.81-08P | 0,662 | 1 | 1 |  | TME | 0,662 € | 1 | 0,662
51 | 2 | P125-2214A0BS230A1 | THT; 28-pin 0.1” board-to-board (Producer: DONG GUAN YLIES PRECISE CONNECTOR CO.,LTD) | X2, X3 | - |  |  |  | - |  |  | - |  |  | - |  |  |  | - |  |  | 2 |  |  |  |  | -
52 | 1 | MMSZ5230BT1G | SOD-123 | ZD1 | 1431272 | MMSZ5230BT1G | 0,177 | 10 | MMSZ5230BT1GOSCT-ND | 0,148 | 10 | 863-MMSZ5230BT1G | 0,170 | 10 | 545-3033 | MMSZ5230BT1G | 0,173 | 20 | MMSZ5230BT1G | 0,033 | 25 |  | 1 | TME | 0,033 € | 1 | 0,033
 |  |  |  |  |  |  |  |  |  |  |  |  |  |  |  |  |  |  |  |  |  | 9 | 77 |  |  |  | 55,47 €
 |  | Not installed
 | 2 | N.C. | 1206 | C24, C35
 | 1 | N.C. |  | IC8
 | 1 | N.C. | SOT-23-5 | IC9
 | 5 | N.C. | R-EU_R0805 | R4, R9, R40, R41, R42
 |  | Related parts and accessories
 | 2 | ZKSS-10A |  |  |  |  |  |  |  |  |  |  |  |  |  |  |  |  | ZKSS-10A | 0,459 | 10 |  |  | TME | 0,459 € | 2 | 0,918
 | 2 | ZKSS-1.25A |  |  |  |  |  |  |  |  |  |  |  |  |  |  |  |  | ZKSS-1.25A | 0,312 | 10 |  |  | TME | 0,312 € | 2 | 0,624
 | 2 | DS1025-01-1*2P8BV1-B | THT; | JP5, JP6 | - |  |  |  | - |  |  | - |  |  | - |  |  |  | ZL303-02P | 0,013 | 50 | 2 |  | TME | 0,013 € | 2 | 0,025
 | 2 | JUMPER-2.0/R |  | JP5, JP6 | - |  |  |  | - |  |  | - |  |  | - |  |  |  | JUMPER-2.0/R | 0,044 | 20 |  |  | TME | 0,044 € | 2 | 0,087
 | 1 | 691304100008 | 8-pin 3.81mm push-in connector |  | - |  |  |  | 277-12329-ND | 7,410 | 1 | 651-1748037 | 7,440 | 1 | 185-4361 | 691304100008 | 8,900 | 1 |  |  |  |  |  | Digikey | 7,410 € | 1 | 7,410
 |  |  |  |  |  |  |  |  |  |  |  |  |  |  |  |  |  |  |  |  |  |  |  |  |  |  | 9,06 €
 |  | Custom made components
 | 1 | PCB 4-layer 141.5 x 68.5 mm | JLCPCB.com | - |  |  |  |  |  |  |  |  |  |  |  |  |  |  |  |  |  |  |  | JLCPCB | 8,796 € | 1 | 8,796
 |  |  |  |  |  |  |  |  |  |  |  |  |  |  |  |  |  |  |  |  |  |  |  |  |  |  | 8,80 €
 |  |  | All prices are net prices (without VAT)
 |  |  |  |  |  |  |  |  |  |  |  |  |  |  |  |  |  |  |  |  |  |  |  |  |  | Total | 73,33 €
 |  |  | Please note that BOM does not contain ordering number for parts on reels or that which includes re-reeling fee. Take also into account that total cost is higher because min. quantity (MOQ) for many parts is larger then what is needed for single unit.
 |  |  | All resistors are 1% 0805 and all capacitors are X7R 0805 if not otherwise specified.
 |  |  | For small quantities, consider ordering specialized chips at store.ti.com for better prices and availability.

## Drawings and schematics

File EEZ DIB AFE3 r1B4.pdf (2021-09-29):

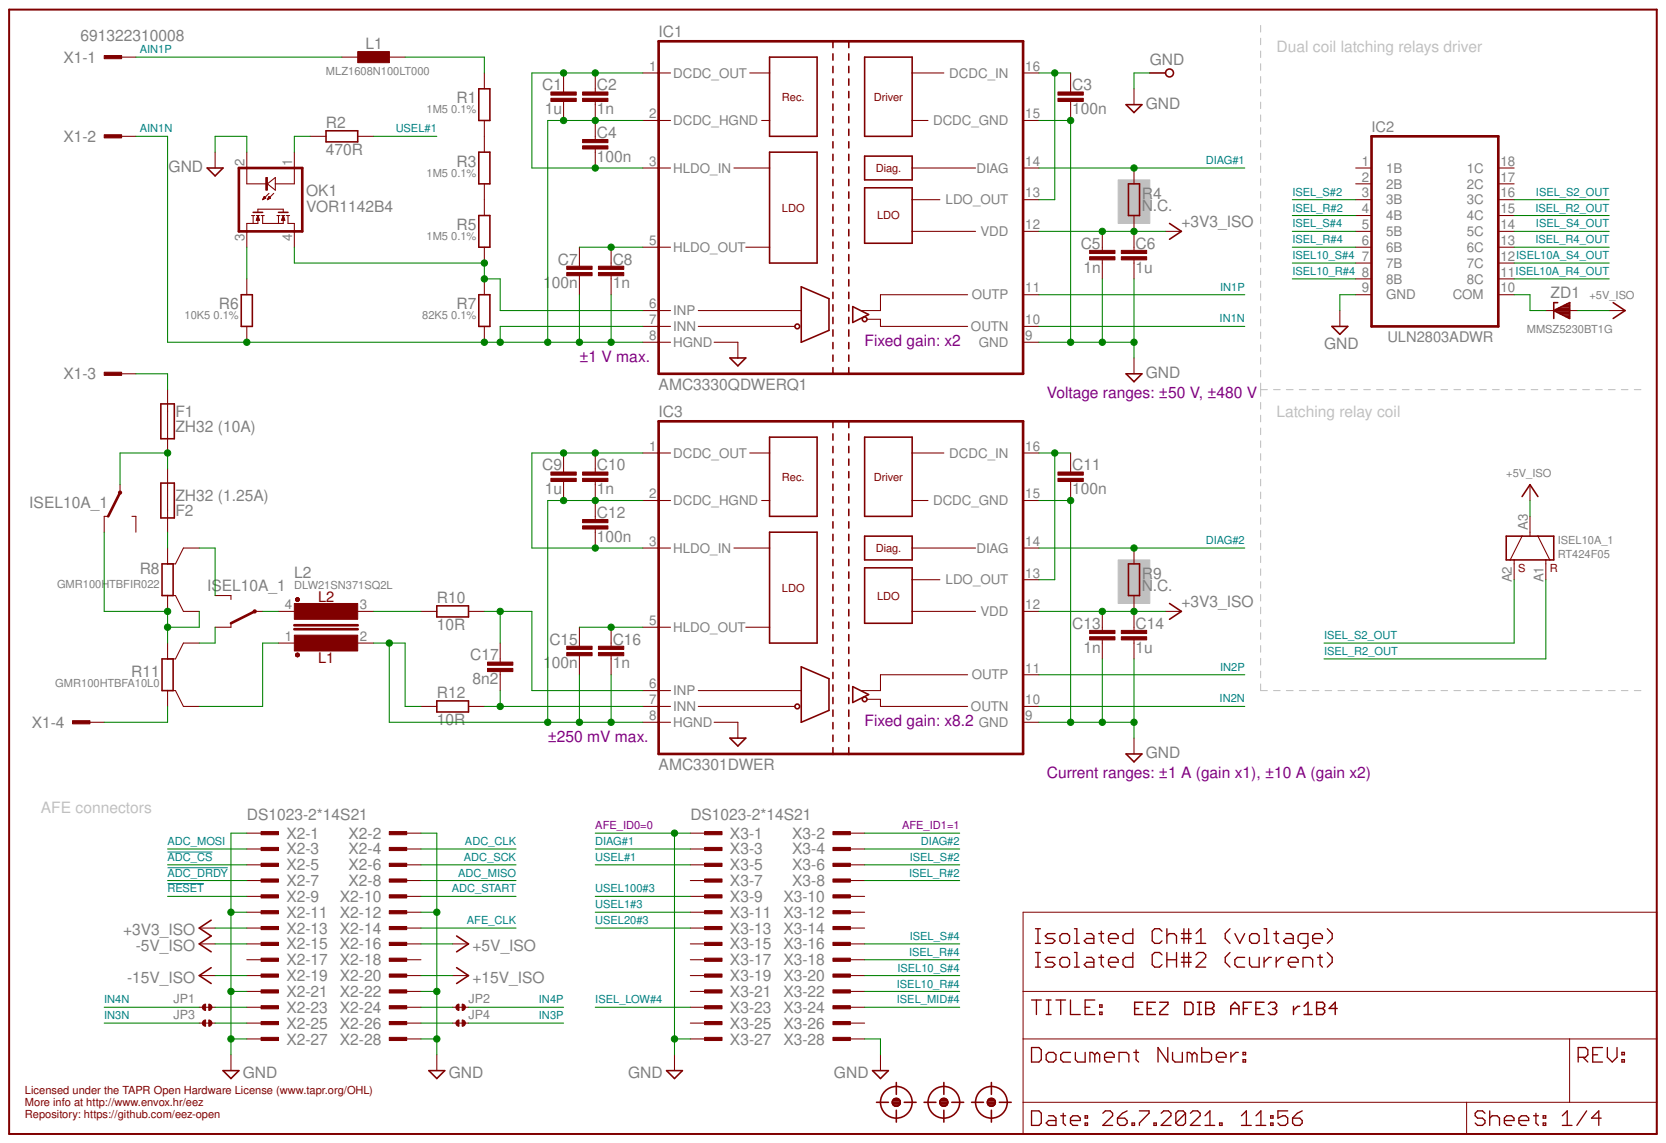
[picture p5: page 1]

Dual coil latching relays driver

10 | IN1N

10 | IN2N
9 Current ranges: ±1 A (gain x1), ±10 A (gain x2)

Licensed under the TAPR Open Hardware License (www.tapr.org/OHL) Repository: https://github.com/eez-open More info at http://www.envox.hr/eez

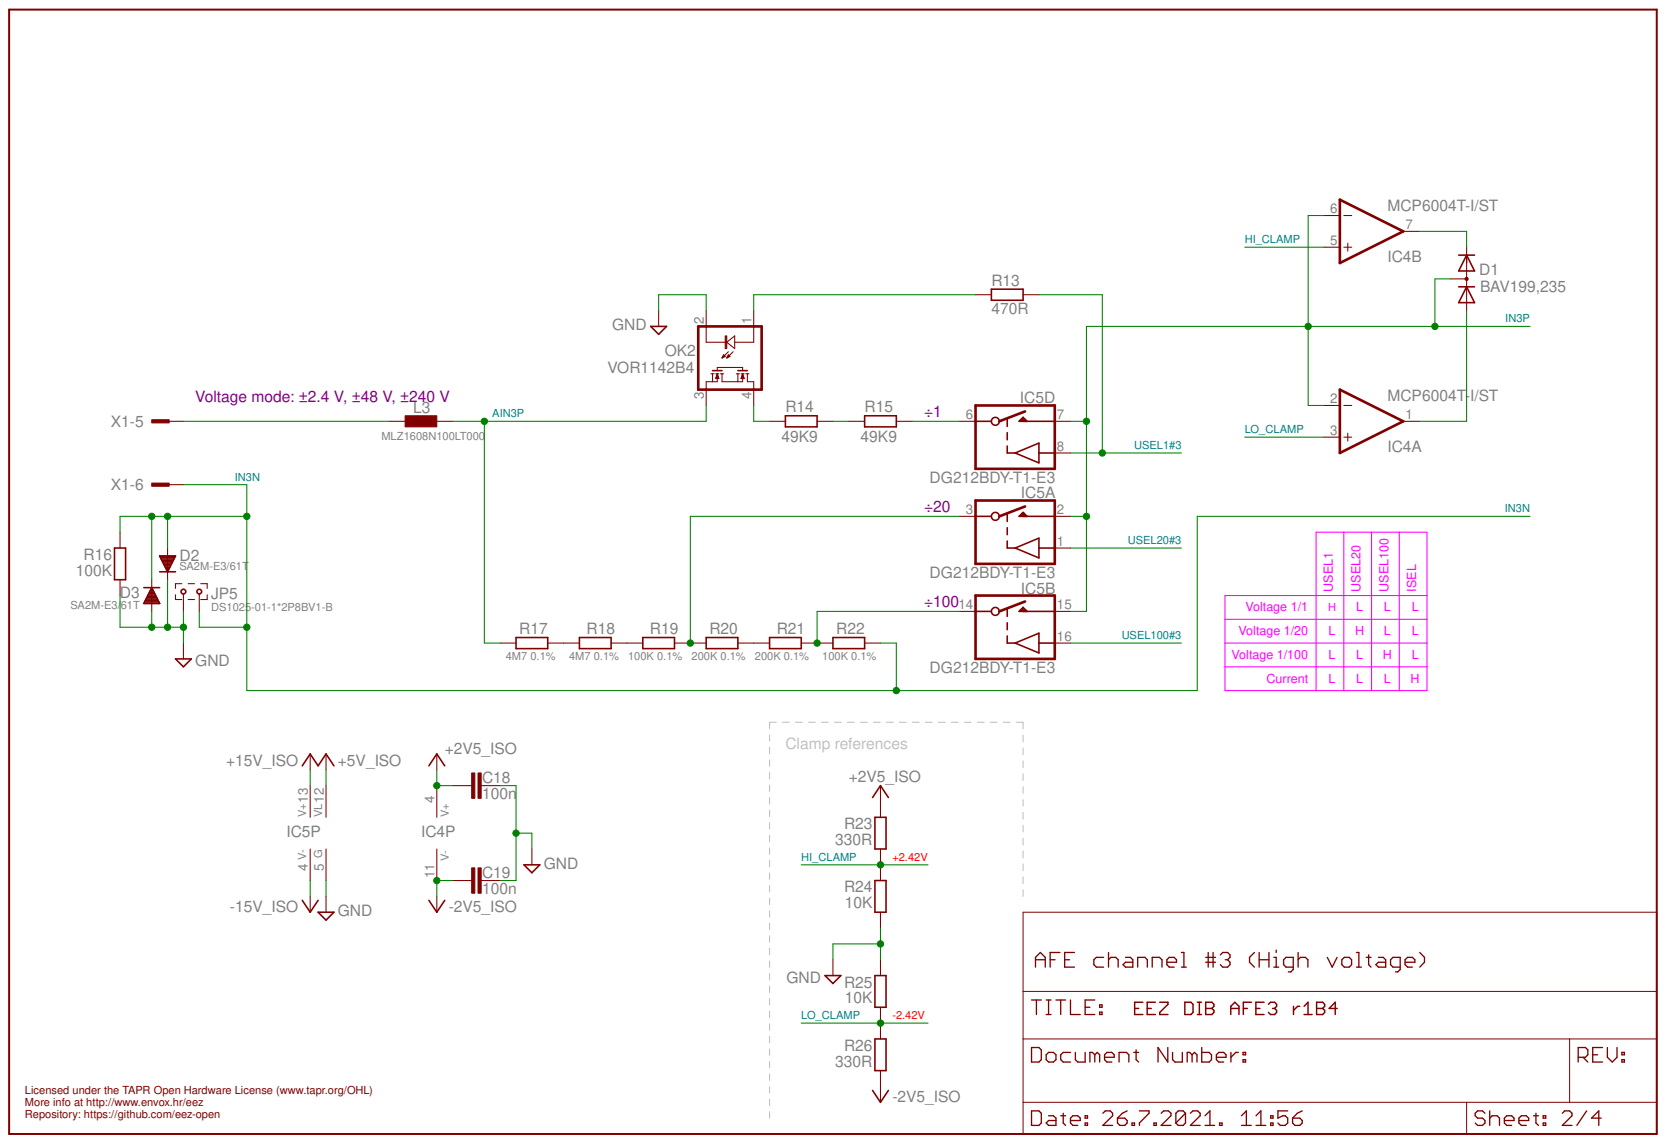
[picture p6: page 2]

L | L | L L H

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

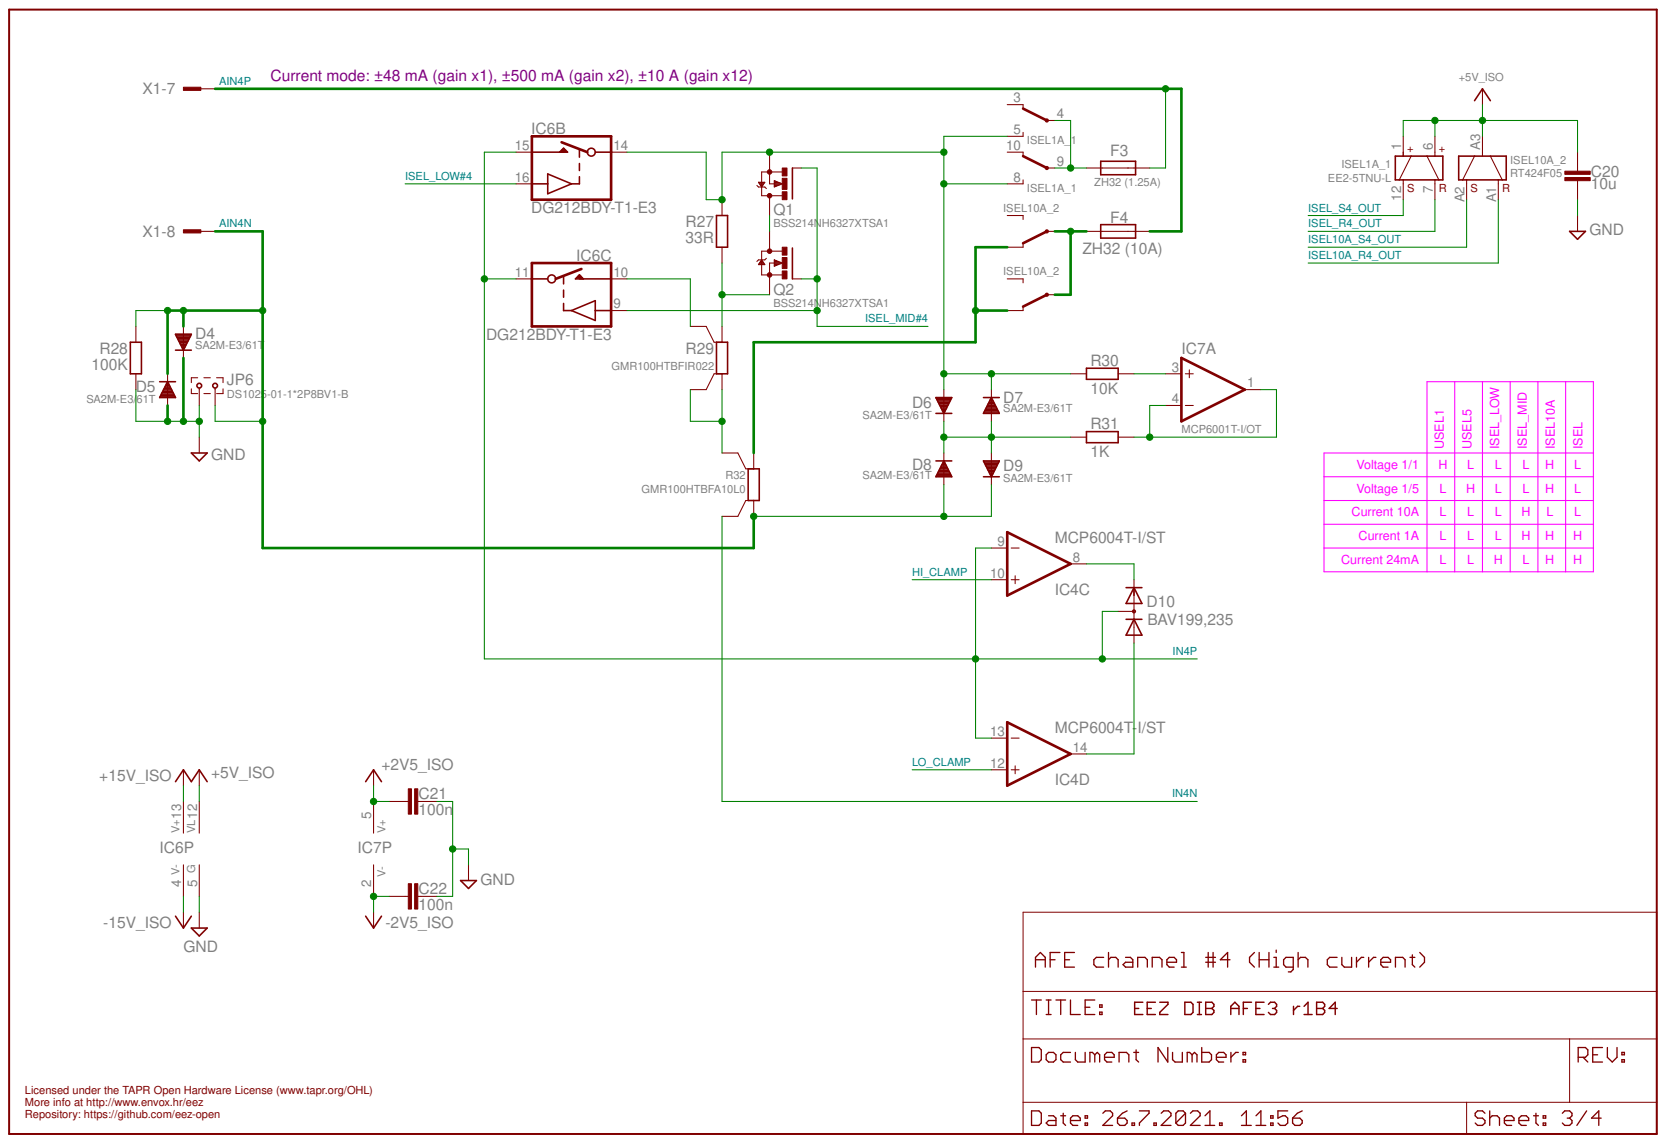
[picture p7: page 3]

Current mode: ±48 mA (gain x1), ±500 mA (gain x2), ±10 A (gain x12)

Voltage 1/5 Voltage 1/1 Current 10A Current 24mA Current 1A | L | H | L | | LH | L

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

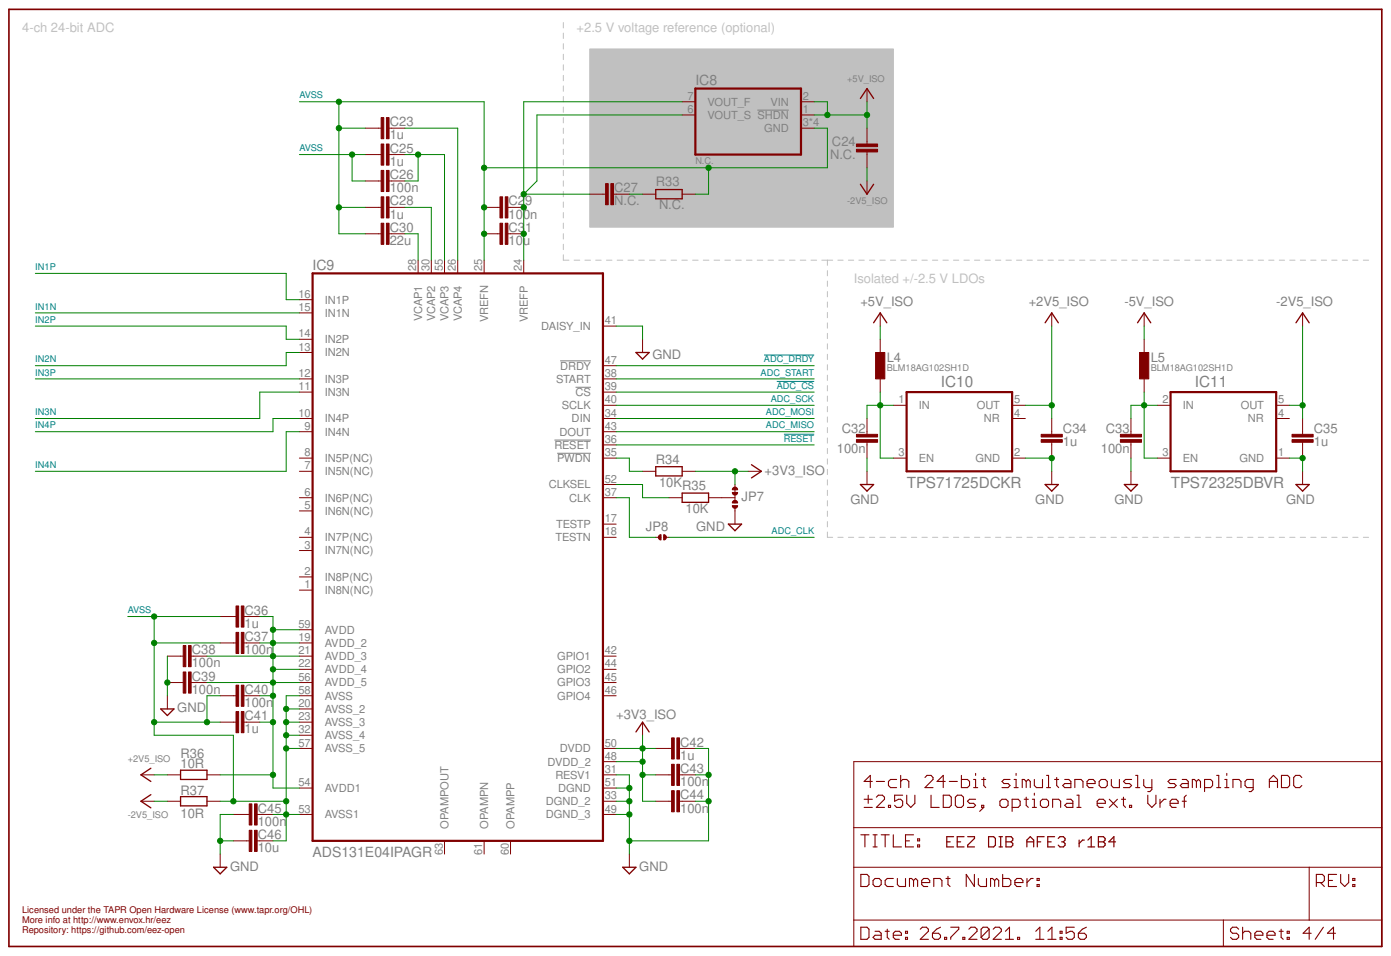
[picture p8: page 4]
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

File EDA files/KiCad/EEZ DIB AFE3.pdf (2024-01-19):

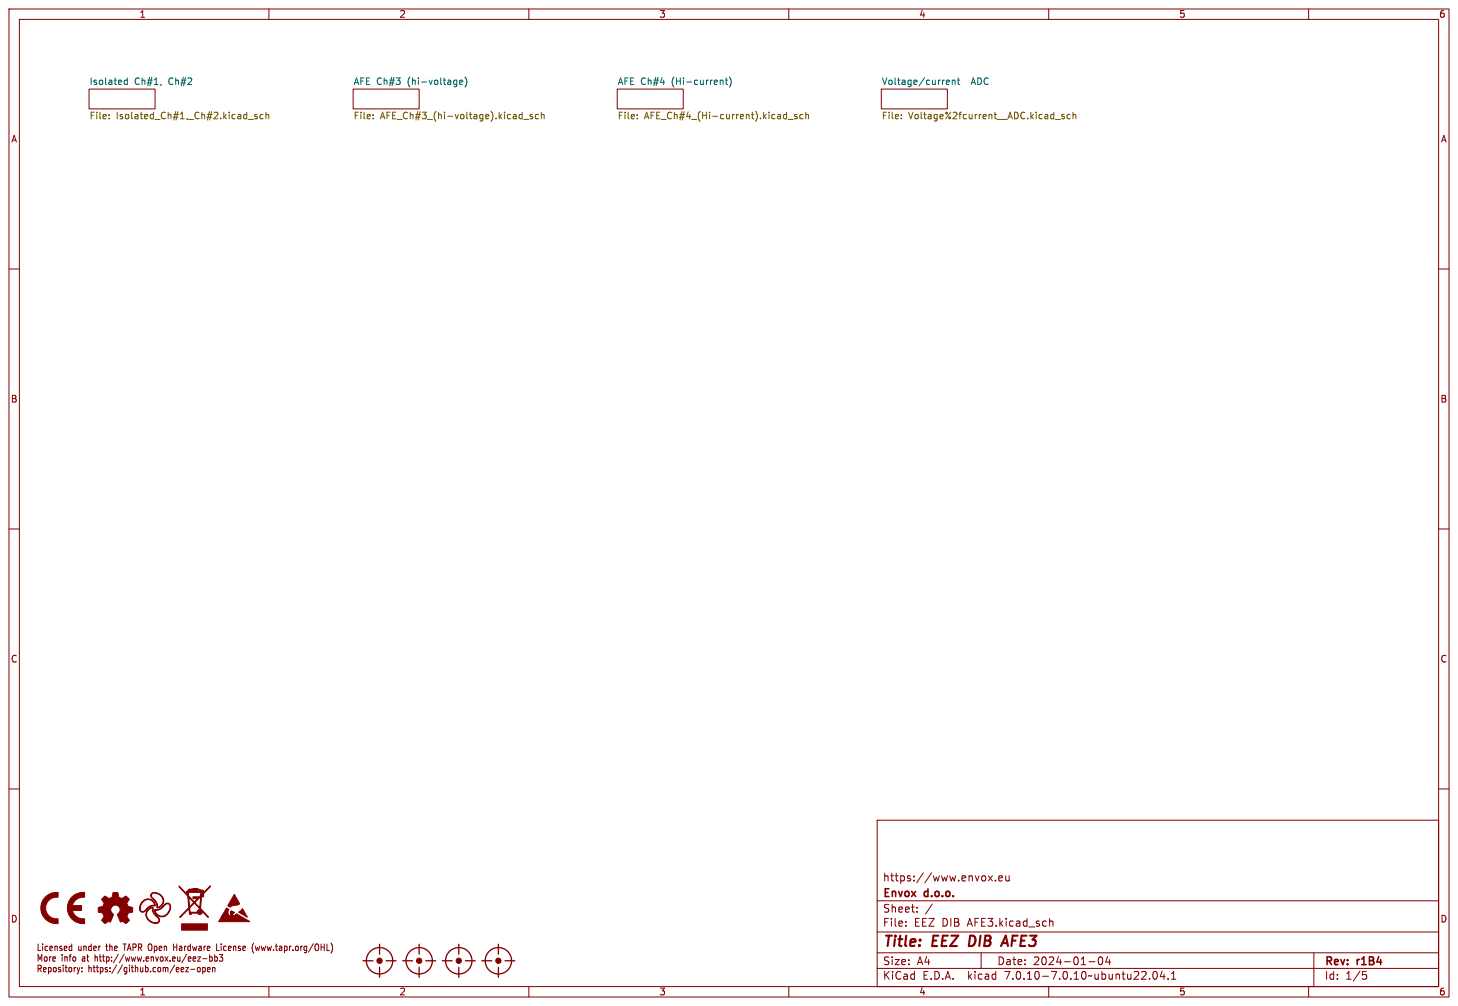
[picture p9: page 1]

File: Voltage%2fcurrent__ADC.kicad_sch AFE Ch#4 (Hi-current) File: AFE_Ch#4_(Hi-current).kicad_sch AFE Ch#3 (hi-voltage) File: AFE_Ch#3_(hi-voltage).kicad_sch

Id: 1/5 Title: EEZ DIB AFE3

Licensed under the TAPR Open Hardware License (www.tapr.org/OHL) More info at http://www.envox.eu/eez-bb3

Repository: https://github.com/eez-open

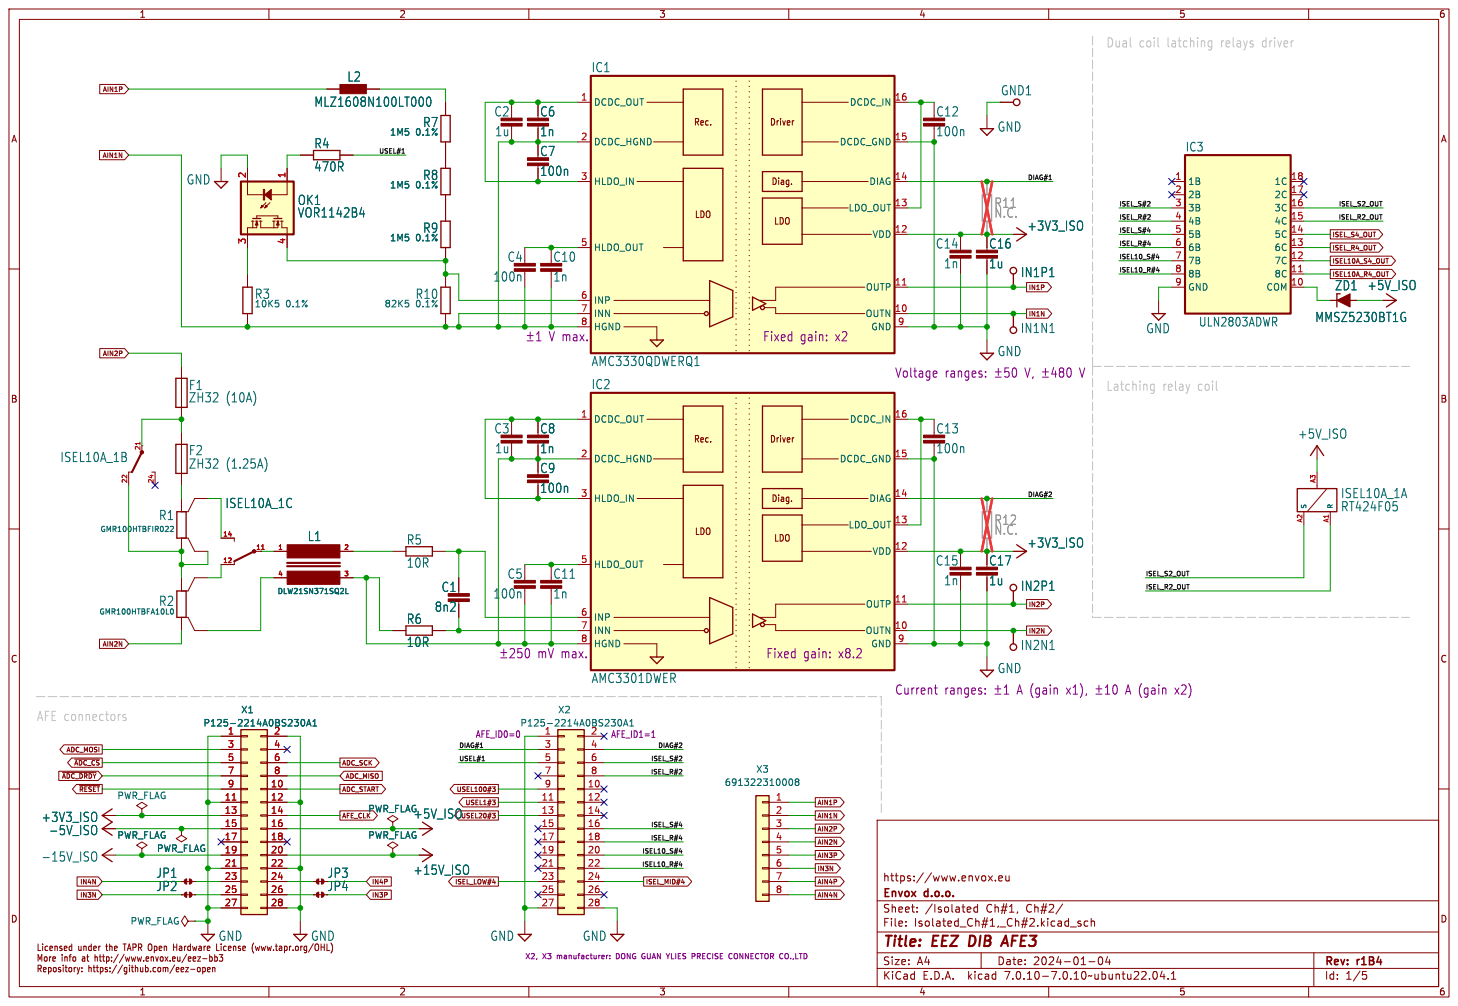
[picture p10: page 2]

Dual coil latching relays driver

DIAG#1 DIAG#2 Voltage ranges: þÿ±50V, þÿ±480V

Id: 1/5 Title: EEZ DIB AFE3

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

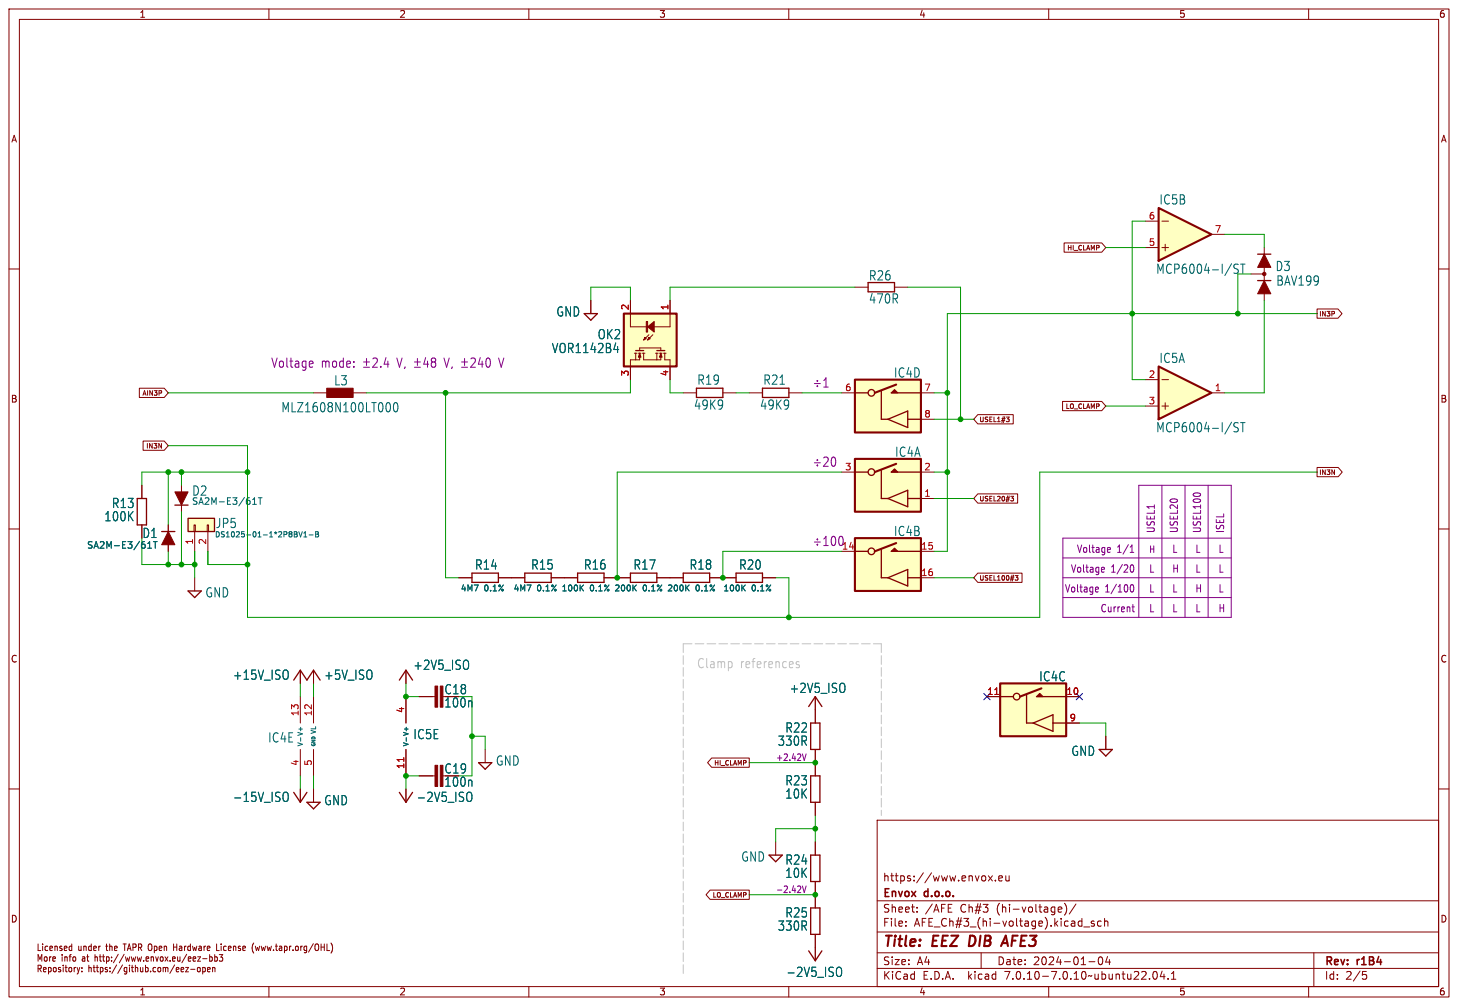
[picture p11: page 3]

Voltage mode: þÿ±2.4V, þÿ±48V, þÿ±240V

File: AFE_Ch#3_(hi-voltage).kicad_sch Sheet: /AFE Ch#3 (hi-voltage)/ Envox d.o.o. https://www.envox.eu

Id: 2/5 Title: EEZ DIB AFE3

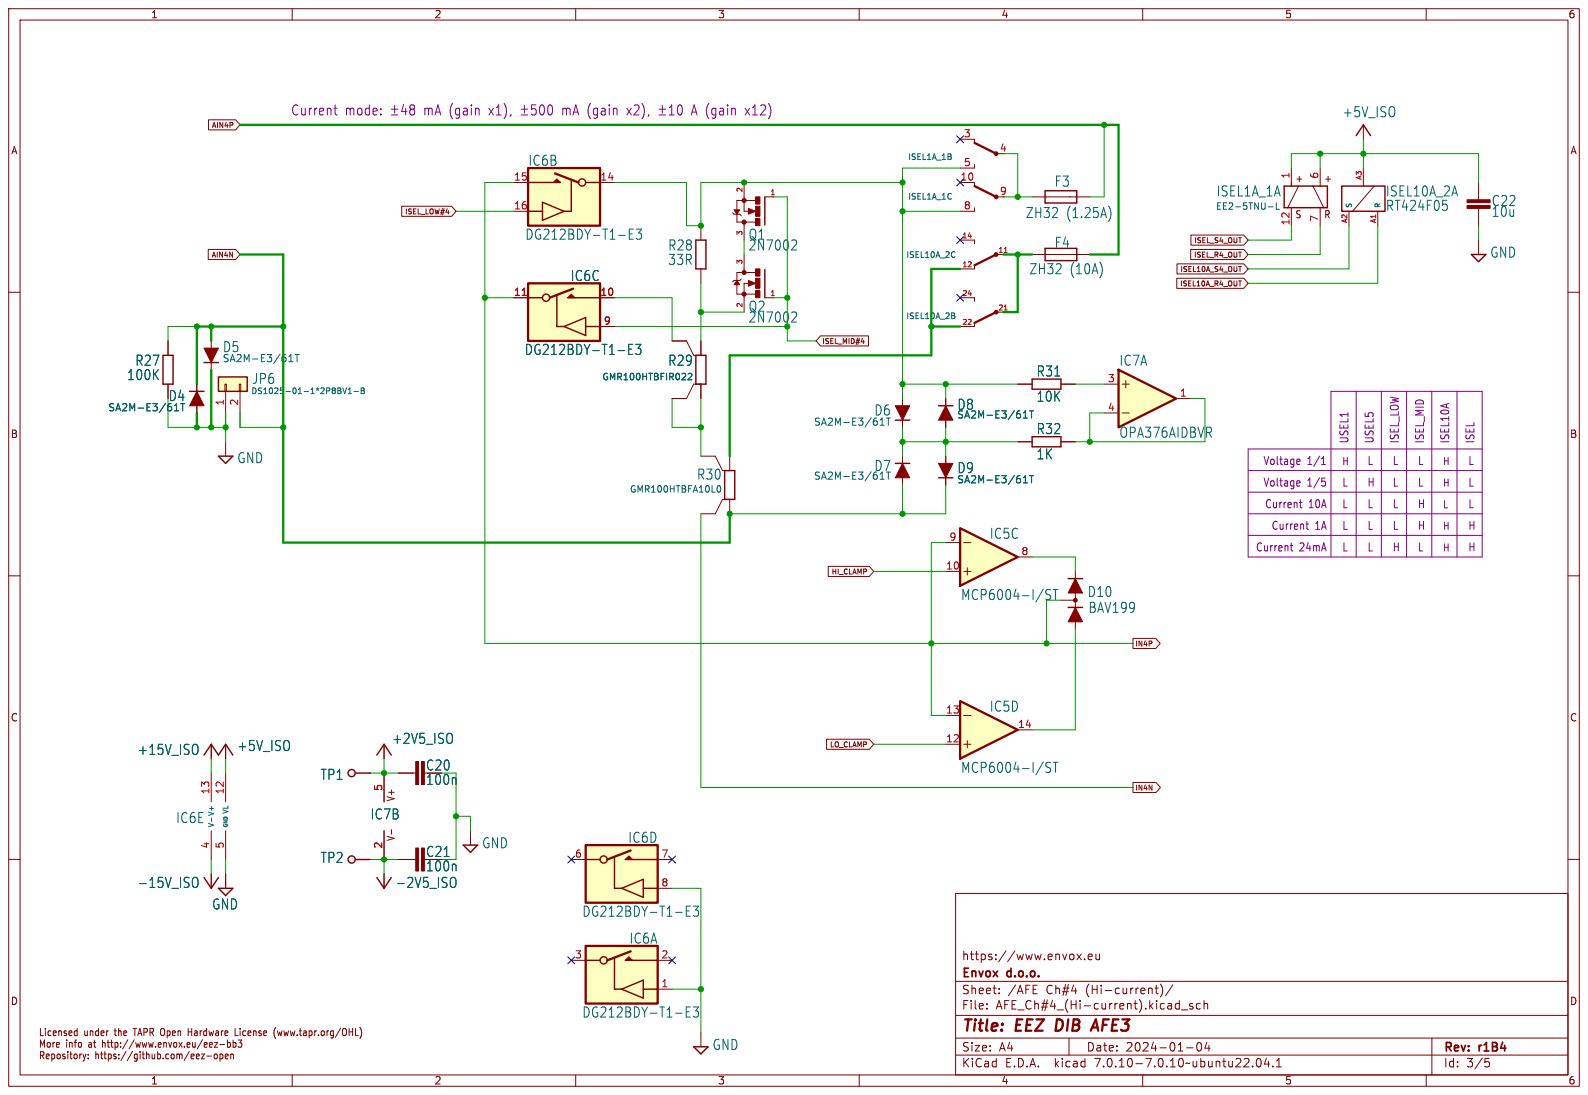
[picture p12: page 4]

Current mode: þÿ±48mA (gain x1), þÿ±500mA (gain x2), þÿ±10A (gain x12)

File: AFE_Ch#4_(Hi-current).kicad_sch Sheet: /AFE Ch#4 (Hi-current)/ Envox d.o.o. https://www.envox.eu

Id: 3/5 Title: EEZ DIB AFE3

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

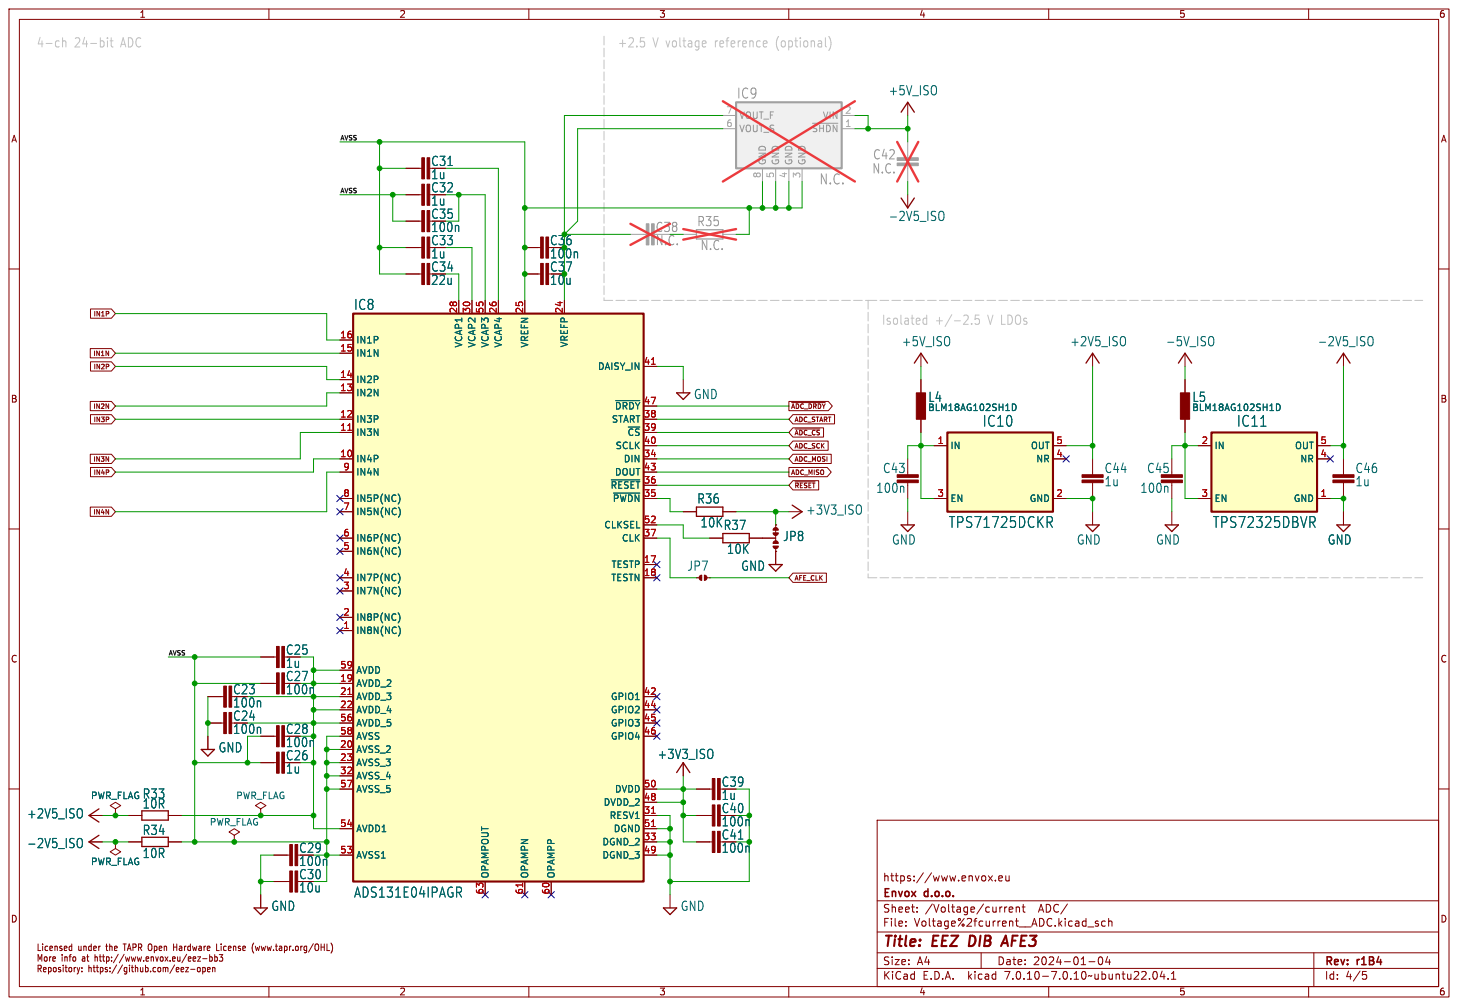
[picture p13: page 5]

Id: 4/5 Title: EEZ DIB AFE3

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

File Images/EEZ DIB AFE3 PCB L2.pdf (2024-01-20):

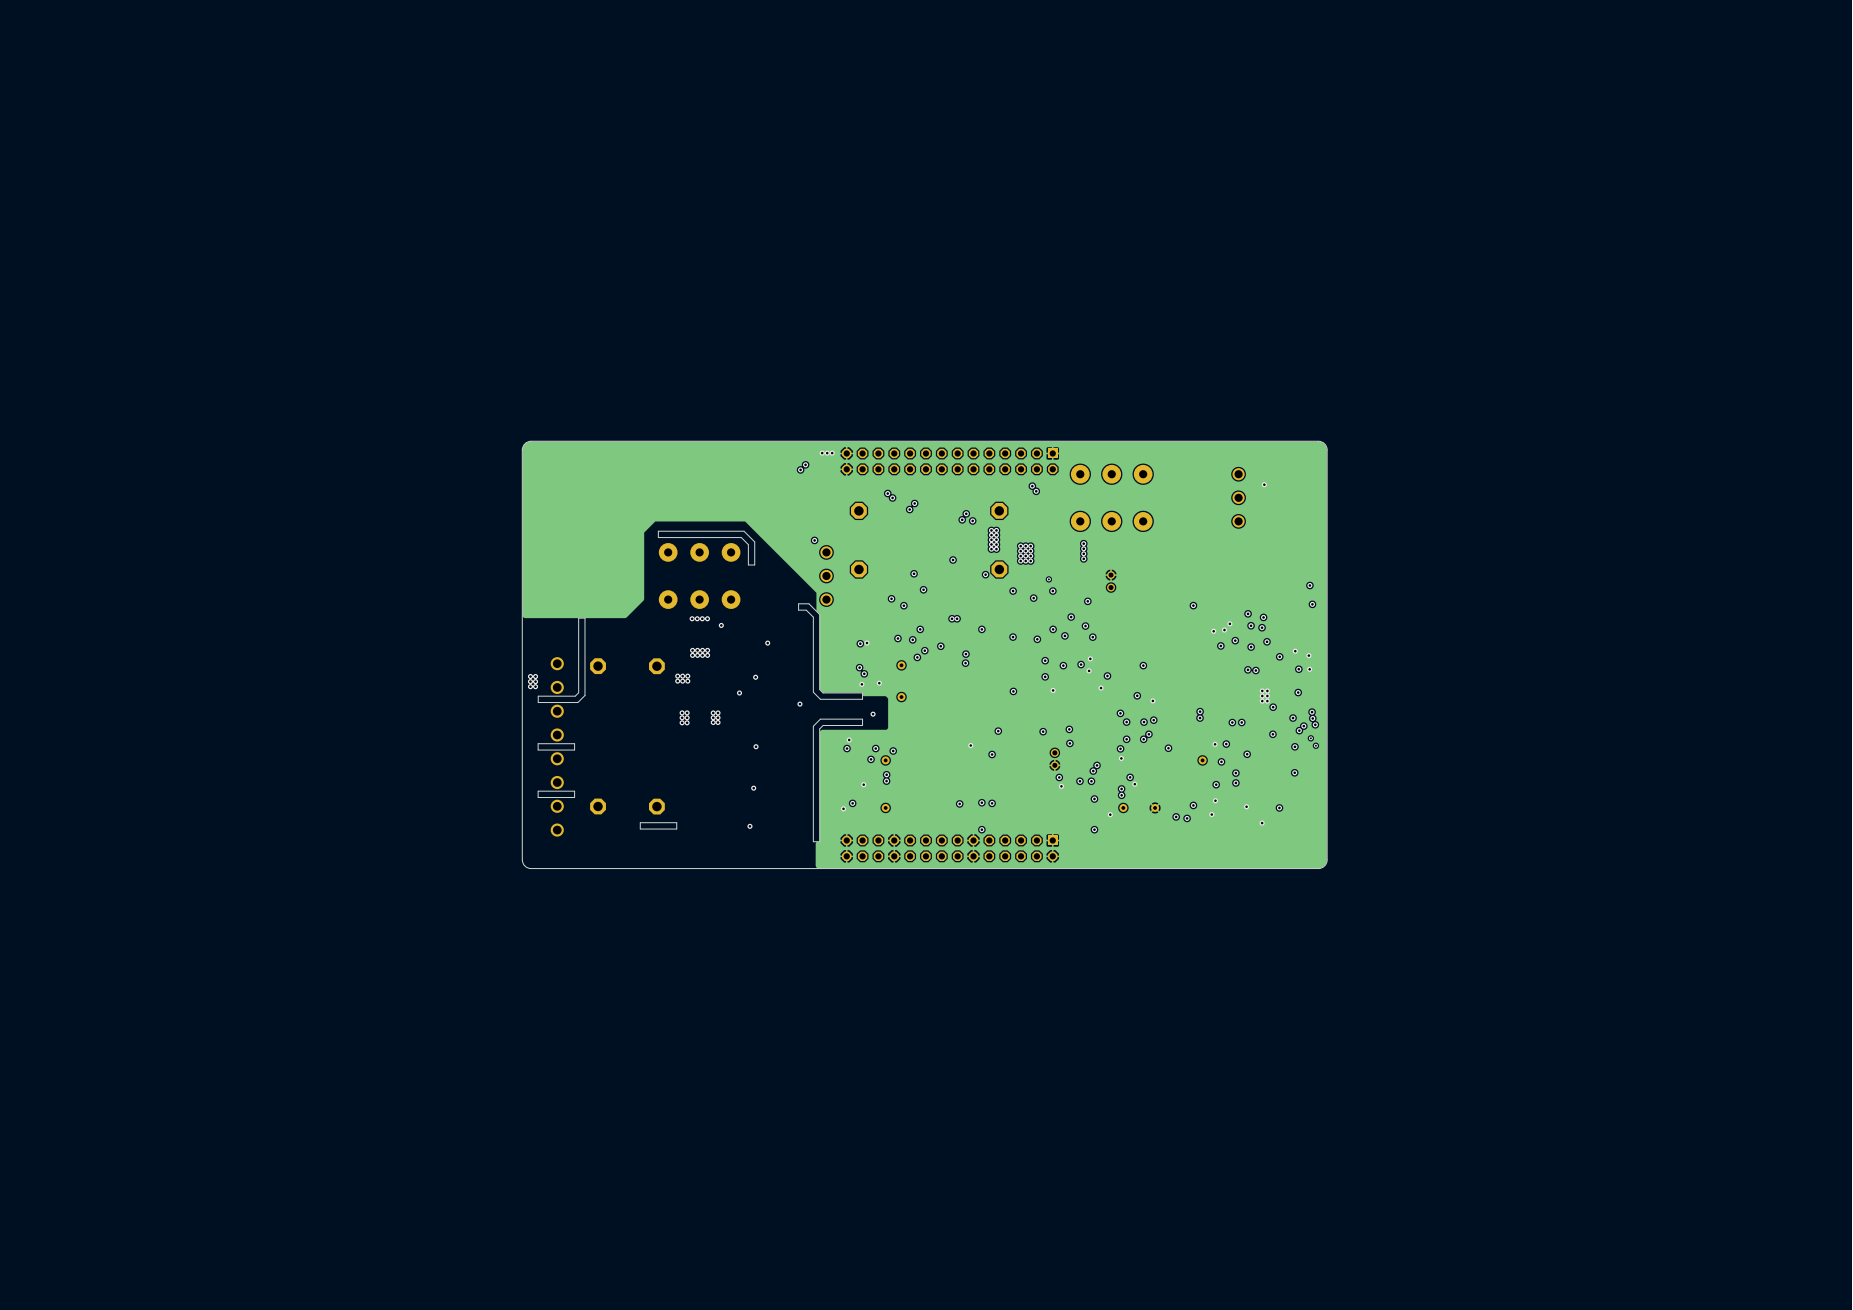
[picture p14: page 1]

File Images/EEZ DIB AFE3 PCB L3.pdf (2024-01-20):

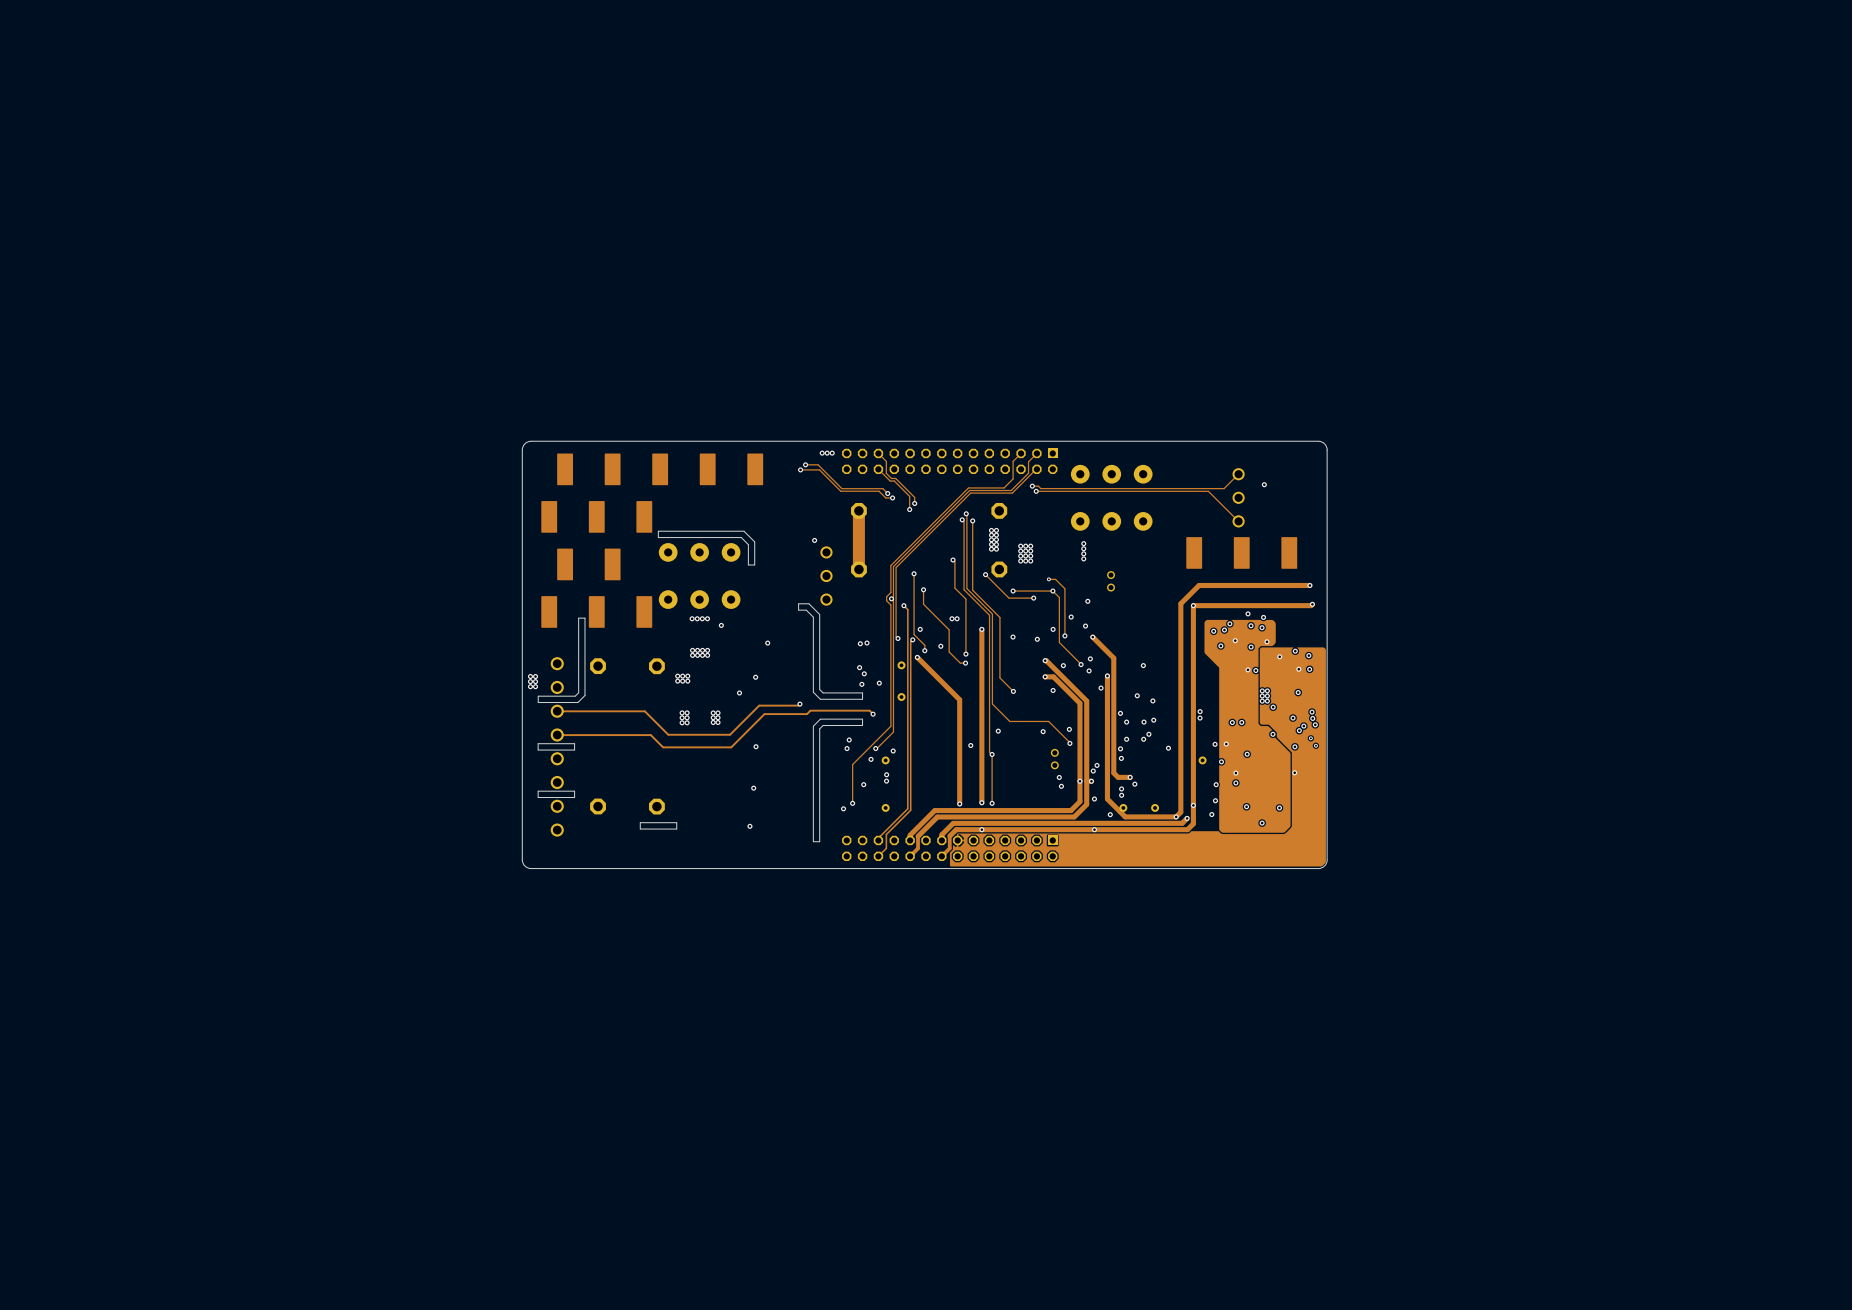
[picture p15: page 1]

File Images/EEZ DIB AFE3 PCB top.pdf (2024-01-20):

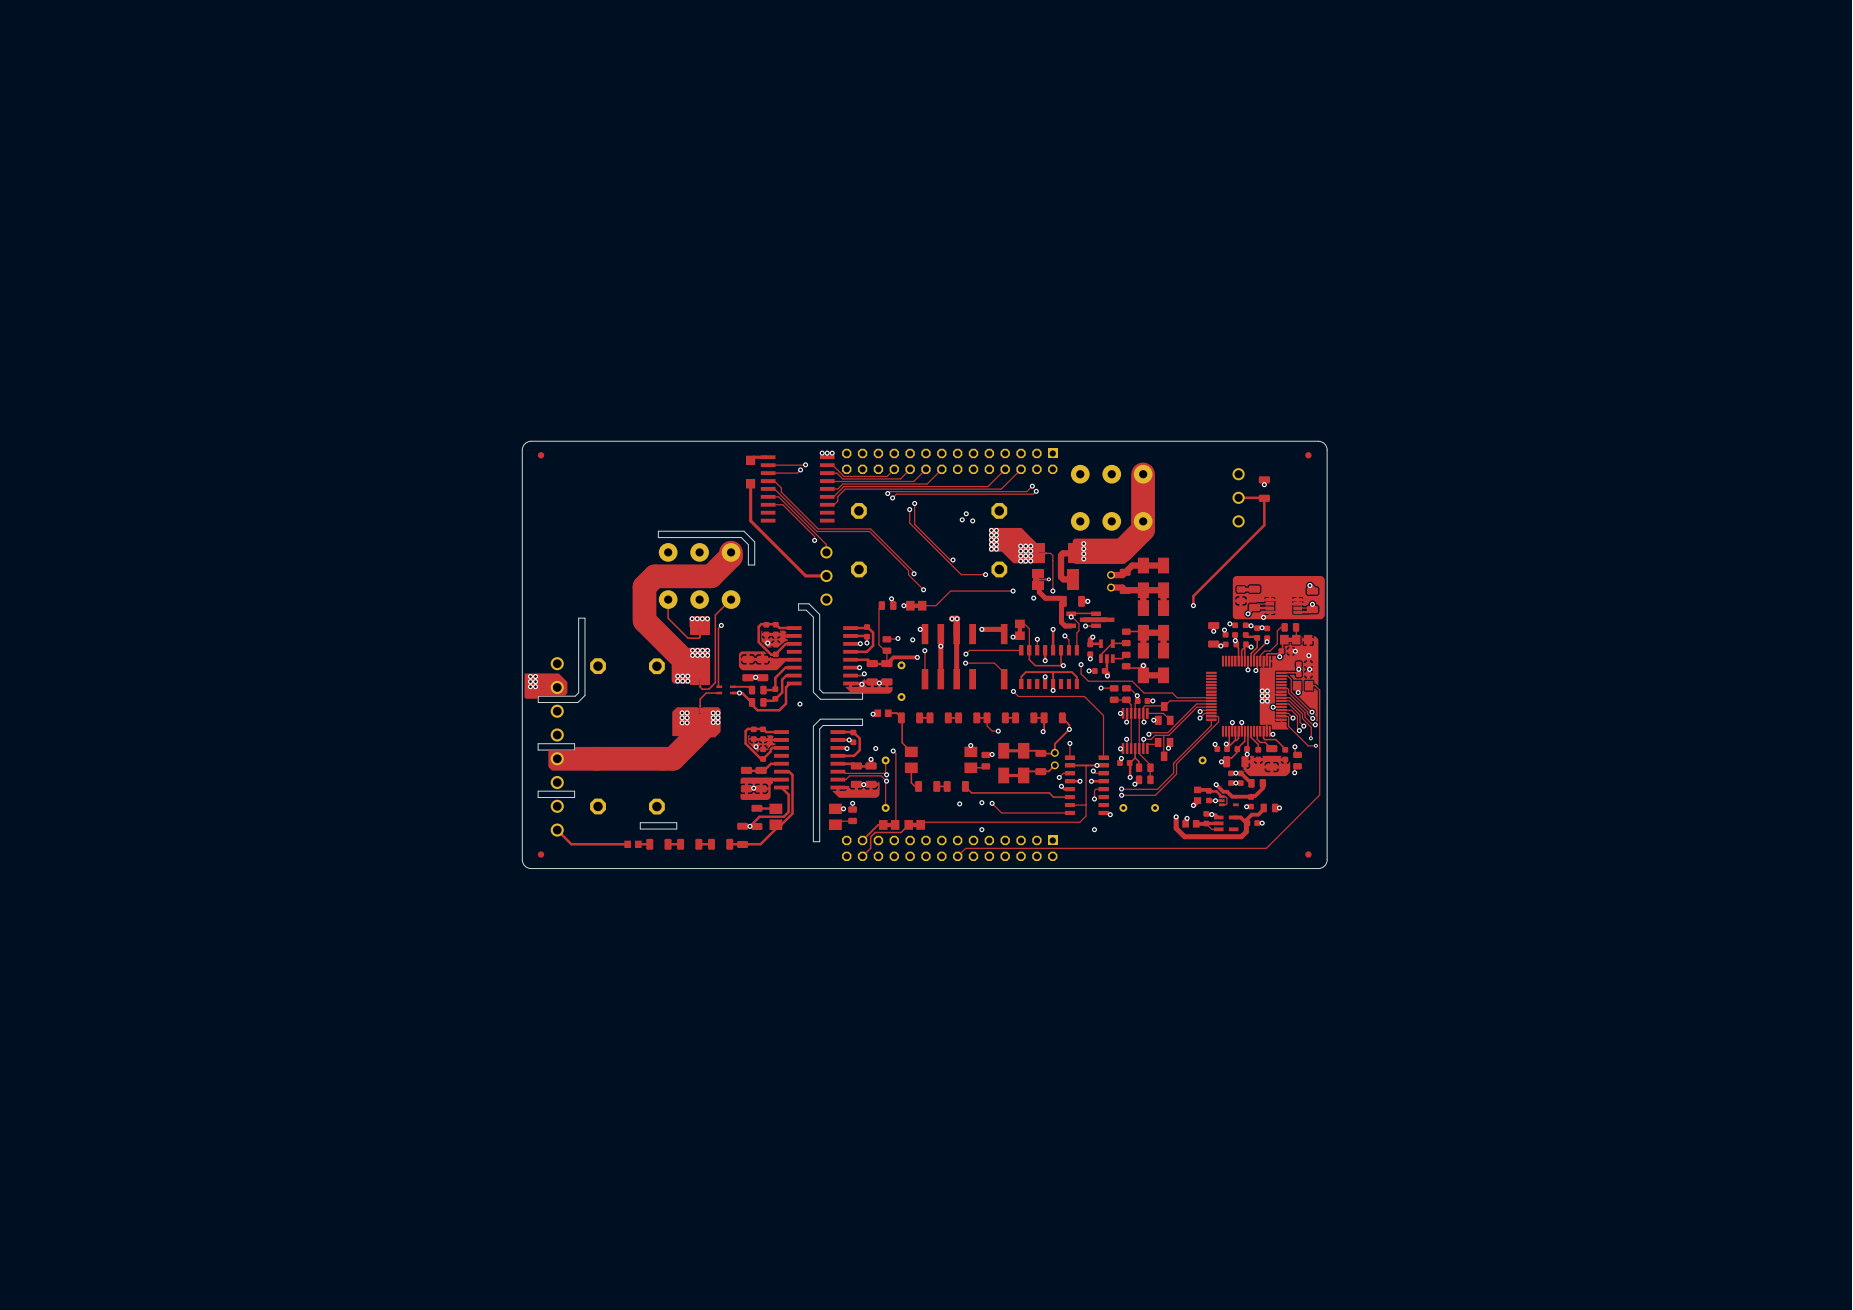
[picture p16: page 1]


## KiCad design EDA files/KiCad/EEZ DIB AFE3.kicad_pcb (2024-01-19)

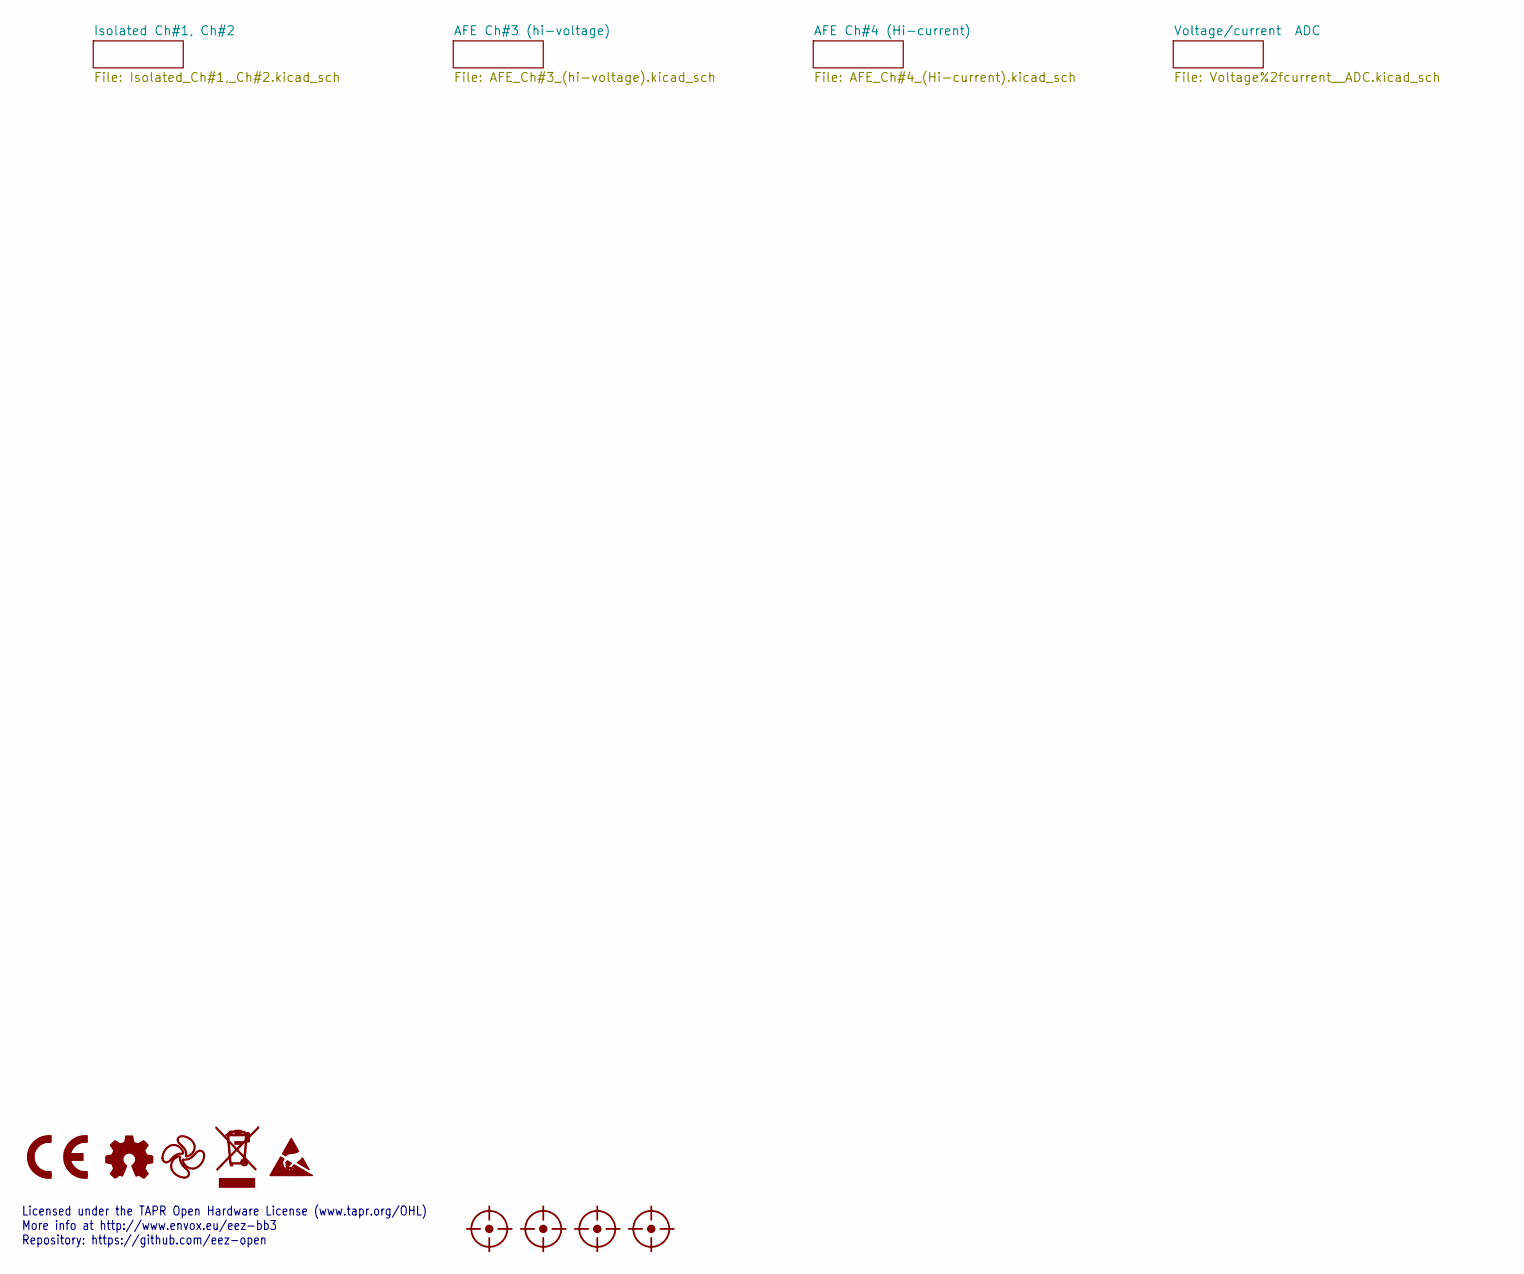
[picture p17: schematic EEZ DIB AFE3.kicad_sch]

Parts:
FM1, FM2, FM3, FM4: FIDUCIAL_2; Fiducial
LOGO1: CR logo; CE logo
LOGO2: Open HW logo
LOGO3: EEZ logo; EEZ logo (outline 6mm)
LOGO4: WEEE logo
LOGO5: ESD logo

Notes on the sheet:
Licensed under the TAPR Open Hardware License (www.tapr.org/OHL) More info at http://www.envox.eu/eez-bb3 Repository: https://github.com/eez-open

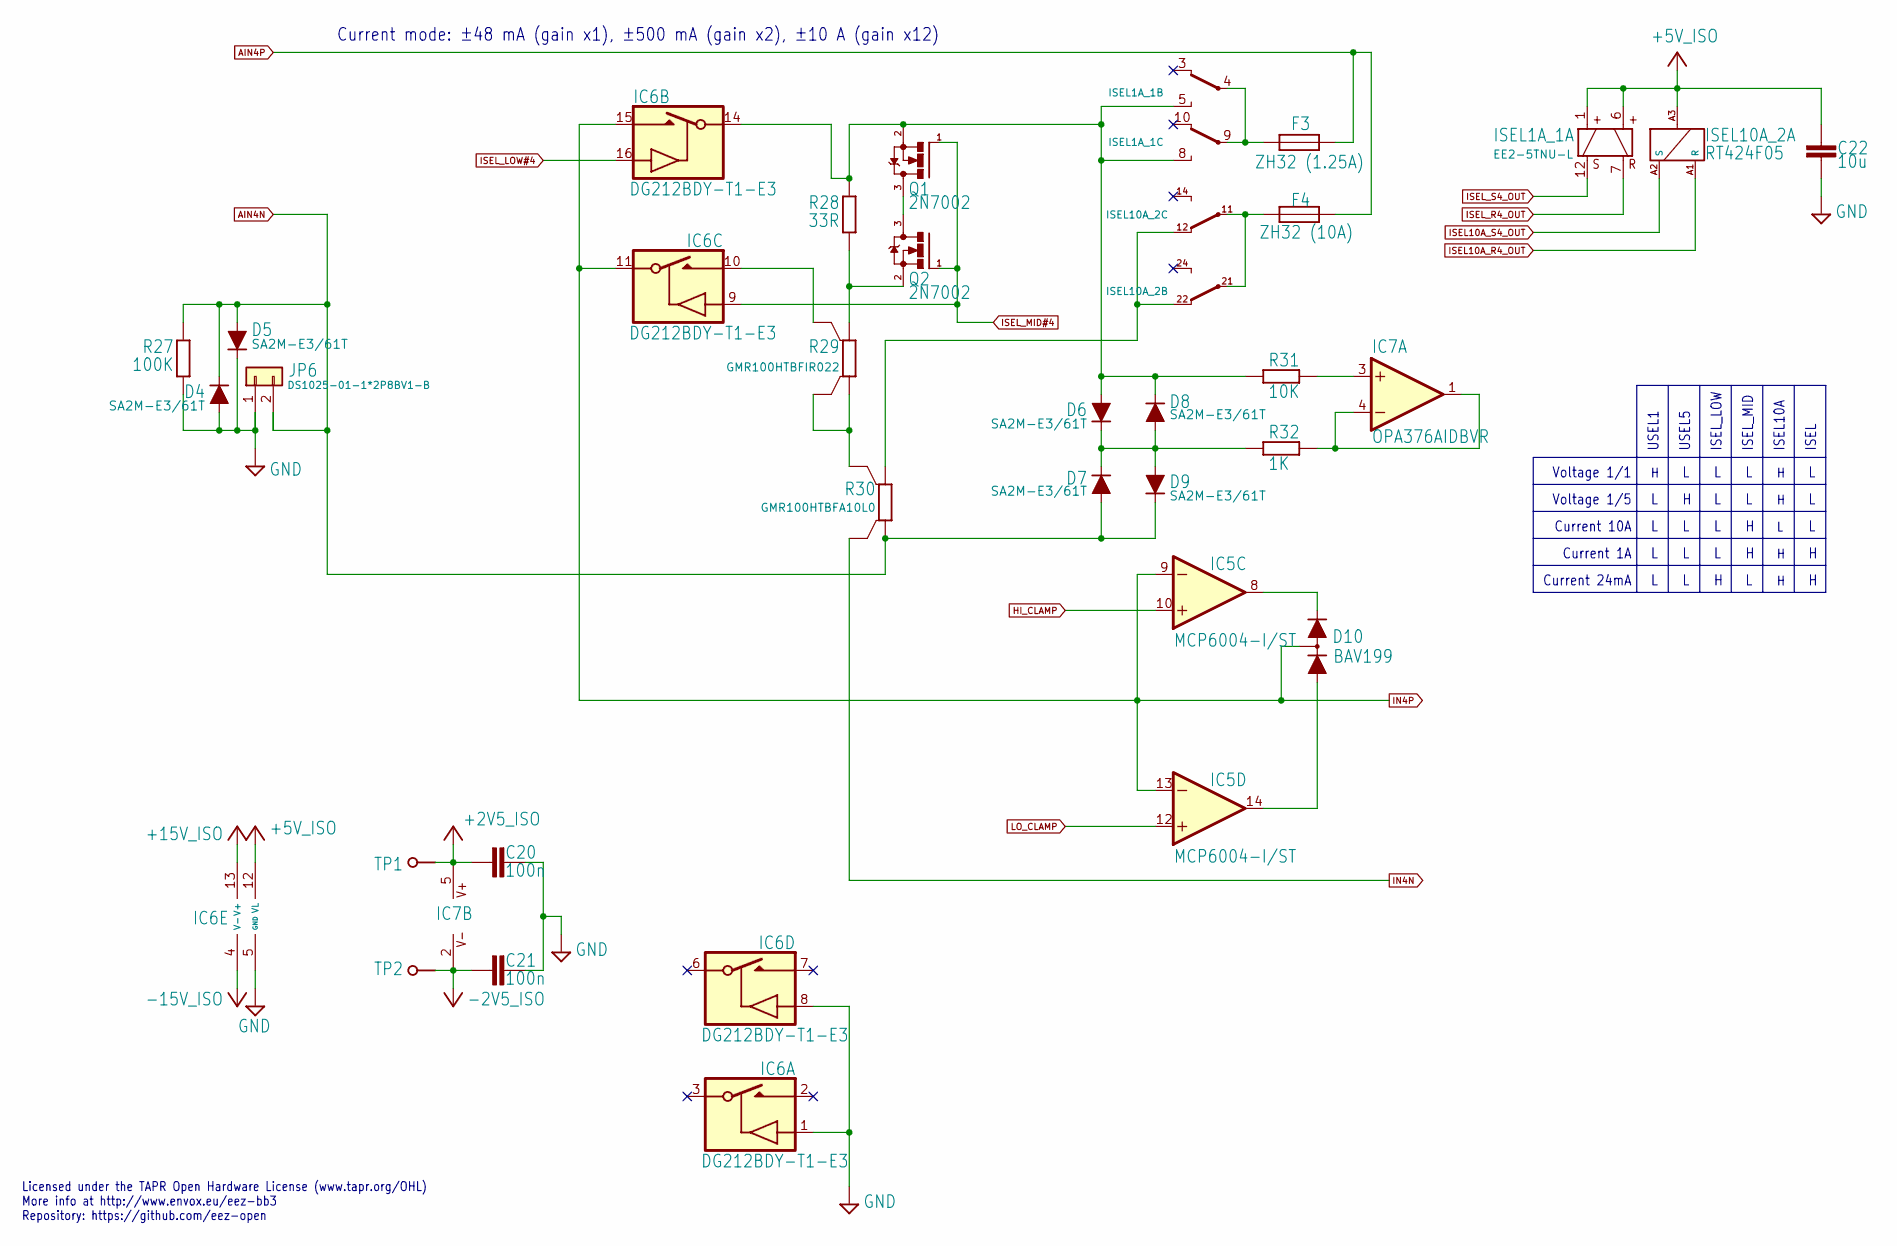
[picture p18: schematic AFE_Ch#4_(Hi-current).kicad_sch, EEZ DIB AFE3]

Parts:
C20, C21: 100n; C_0603_1608Metric; DigiKey 490-4774-1-ND
C22: 10u; C_1206_3216Metric; DigiKey 1276-2872-1-ND
D4, D5, D6, D7, D8, D9: SA2M-E3/61T; DO214AC-2; DigiKey CSA2M-E3/IGICT-ND
D10: BAV199; SOT23-3; DigiKey 1727-6382-1-ND
F3: ZH32 (1.25A); ZH32; DigiKey 732-11370-ND
F4: ZH32 (10A); ZH32; DigiKey 732-11370-ND
IC5: MCP6004-I/ST; PW(R-PDSO-G14); DigiKey MCP6004T-I/STTR-ND
IC6: DG212BDY-T1-E3; SO16; DigiKey DG212BDY-T1-E3CT-ND
IC7: OPA376AIDBVR; SOT23-5L_STM; DigiKey 296-39130-2-ND
ISEL1A_1: EE2-5TNU-L; DigiKey 399-11021-1-ND
ISEL10A_2: RT424F05; DigiKey PB2024-ND
JP6: DS1025-01-1*2P8BV1-B; 2MM-2; DigiKey 2057-2PH1-02-UA-ND
Q1, Q2: 2N7002; SOT103P240X110-3N; DigiKey 2N7002LT1GOSCT-ND
R27: 100K; R_1206_3216Metric; DigiKey RMCF0805FT100KCT-ND
R28: 33R; R_1206_3216Metric; DigiKey 13-RT1206BRD0733RLCT-ND
R29: GMR100HTBFIR022; R_2512-4WIRE; DigiKey 511-1688-1-ND
R30: GMR100HTBFA10L0; R_2512-4WIRE; DigiKey 511-1686-1-ND
R31: 10K; R_0805_2012Metric; DigiKey 311-10.0KCRCT-ND
R32: 1K; R_0805_2012Metric; DigiKey RC0805FR-071KL
TP1, TP2: PCB_TEST_TABSHIELD; Testhole 24_50mils

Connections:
+2V5_ISO: C20.2, IC7.5 (V+), TP1.1; also elsewhere on the board
+5V_ISO: C22.1, IC6.12 (VL), ISEL1A_1.1 (S+), ISEL1A_1.6 (R+), ISEL10A_2.A3; also elsewhere on the board
+15V_ISO: IC6.13 (V+); also elsewhere on the board
-2V5_ISO: C21.2, IC7.2 (V-), TP2.1; also elsewhere on the board
-15V_ISO: IC6.4 (V-); also elsewhere on the board
AIN4N: D4.C, D5.A, D7.A, D9.C, JP6.2, R27.2, R30.1; also elsewhere on the board
AIN4P: F3.2, F4.2; also elsewhere on the board
GND: C20.1, C21.1, C22.2, D4.A, D5.C, IC6.1 (IN), IC6.5 (GND), IC6.8 (IN), JP6.1, R27.1; also elsewhere on the board
HI_CLAMP: IC5.10 (+IN); also elsewhere on the board
IN4N: R30.1S; also elsewhere on the board
IN4P: D10.3 (AC), IC5.9 (-IN), IC5.13 (-IN), IC6.11 (S), IC6.15 (D); also elsewhere on the board
ISEL10A_R4_OUT: ISEL10A_2.A1 (R); also elsewhere on the board
ISEL10A_S4_OUT: ISEL10A_2.A2 (S); also elsewhere on the board
ISEL_LOW#4: IC6.16 (IN); also elsewhere on the board
ISEL_MID#4: IC6.9 (IN), Q1.1 (G), Q2.1 (G); also elsewhere on the board
ISEL_R4_OUT: ISEL1A_1.7 (R-); also elsewhere on the board
ISEL_S4_OUT: ISEL1A_1.12 (S-); also elsewhere on the board
LO_CLAMP: IC5.12 (+IN); also elsewhere on the board
unnamed: D6.C, D7.C, D8.A, D9.A, R32.2
unnamed: D10.1 (A), IC5.14 (OUT)
unnamed: D10.2 (C), IC5.8 (OUT)
unnamed: F4.1, ISEL10A_2.11, ISEL10A_2.21
unnamed: D6.A, D8.C, IC6.14 (S), ISEL1A_1.5 (NO), ISEL1A_1.8 (NO), Q1.2 (S), R28.2, R31.2
unnamed: IC6.10 (D), R29.2S
unnamed: IC7.3 (+IN), R31.1
unnamed: IC7.1 (OUT), IC7.4 (-IN), R32.1
unnamed: F3.1, ISEL1A_1.4 (COM), ISEL1A_1.9 (COM)
unnamed: ISEL10A_2.12, ISEL10A_2.22, R30.2
unnamed: Q1.3 (D), Q2.3 (D)
unnamed: Q2.2 (S), R28.1, R29.2
unnamed: R29.1, R29.1S, R30.2S

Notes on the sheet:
Current 24mA
Voltage 1/1
USEL5
Current 10A
Current mode: ±48 mA (gain x1), ±500 mA (gain x2), ±10 A (gain x12)
ISEL_LOW
ISEL
USEL1
ISEL_MID
Current 1A
Voltage 1/5
Licensed under the TAPR Open Hardware License (www.tapr.org/OHL) More info at http://www.envox.eu/eez-bb3 Repository: https://github.com/eez-open
ISEL10A

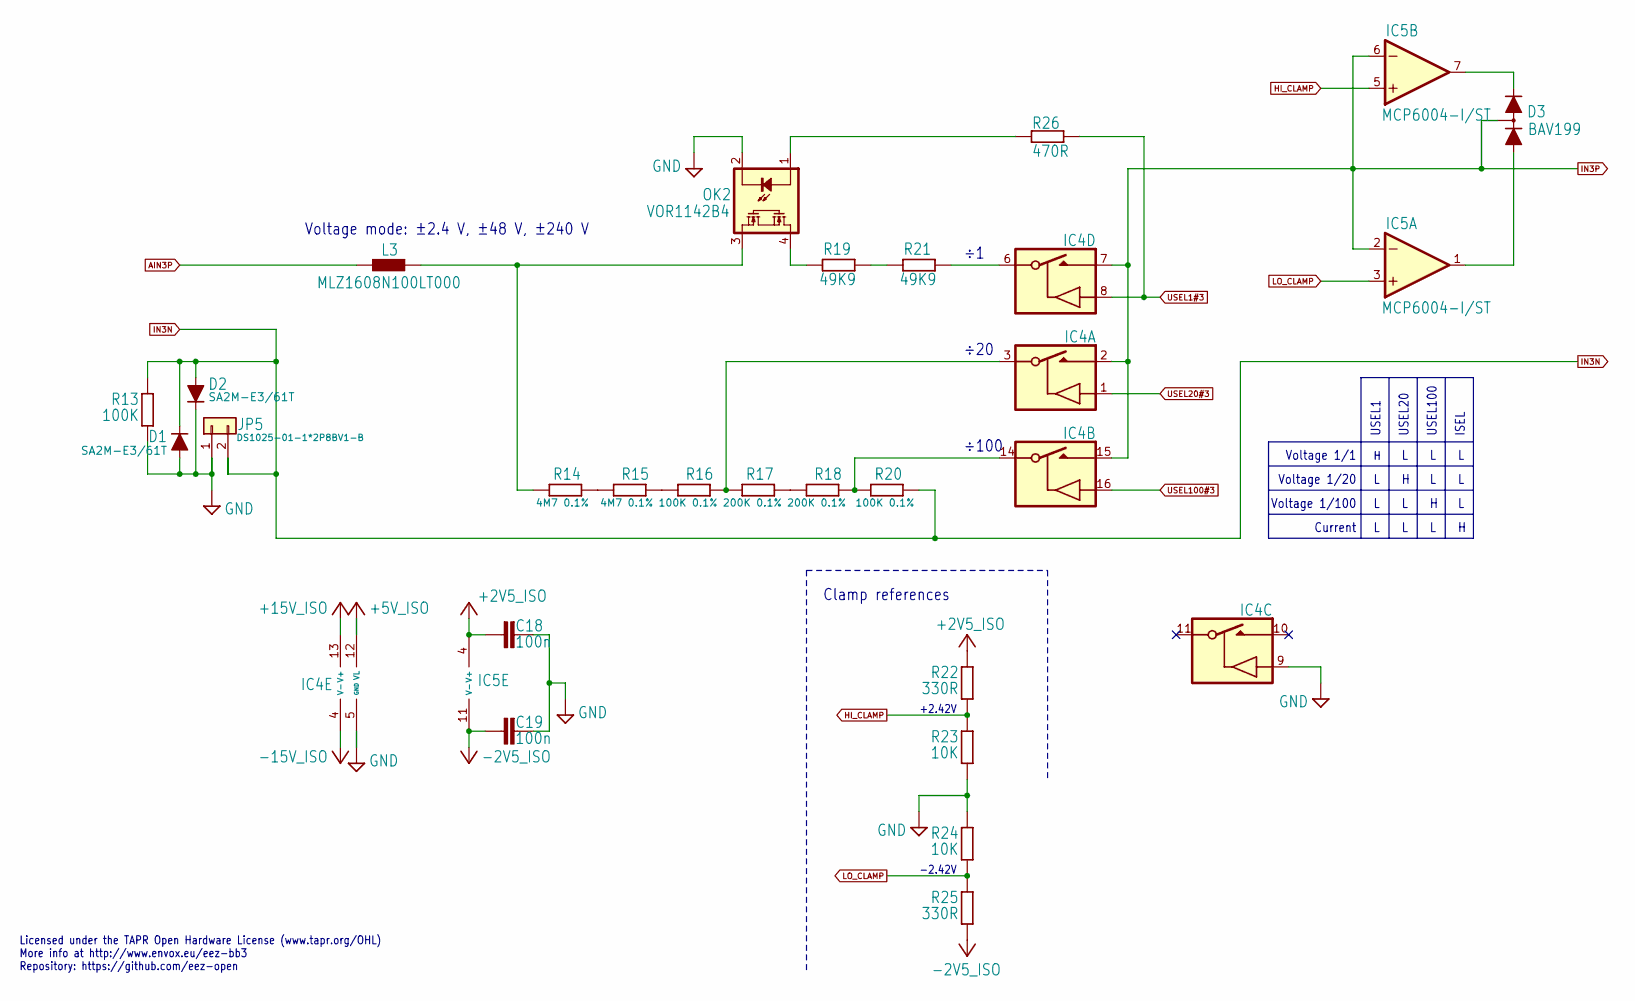
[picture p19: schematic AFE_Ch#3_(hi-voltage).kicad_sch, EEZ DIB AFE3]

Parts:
C18, C19: 100n; C_0603_1608Metric; DigiKey 490-4774-1-ND
D1, D2: SA2M-E3/61T; DO214AC-2; DigiKey CSA2M-E3/IGICT-ND
D3: BAV199; SOT23-3; DigiKey 1727-6382-1-ND
IC4: DG212BDY-T1-E3; SO16; DigiKey DG212BDY-T1-E3CT-ND
IC5: MCP6004-I/ST; PW(R-PDSO-G14); DigiKey MCP6004T-I/STTR-ND
JP5: DS1025-01-1*2P8BV1-B; 2MM-2; DigiKey 2057-2PH1-02-UA-ND
L3: MLZ1608N100LT000; BEAD0603; DigiKey 445-6755-1-ND
OK2: VOR1142B4; DIL4-SMD; DigiKey VOR1142B4-ND
R13: 100K; R_1206_3216Metric; DigiKey RMCF0805FT100KCT-ND
R14, R15: 4M7 0.1%; R_1206_3216Metric; DigiKey 408-2037-1-ND
R16, R20: 100K 0.1%; R_1206_3216Metric; DigiKey RG32P100KBCT-ND
R17, R18: 200K 0.1%; R_1206_3216Metric; DigiKey RG32P200KBCT-ND
R19, R21: 49K9; R_1206_3216Metric; DigiKey RNCP1206FTD49K9CT-ND
R22, R25: 330R; R_0805_2012Metric; DigiKey A106061CT-ND
R23, R24: 10K; R_0805_2012Metric; DigiKey 311-10.0KCRCT-ND
R26: 470R; R_0805_2012Metric; DigiKey 311-470CRCT-ND

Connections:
+2V5_ISO: C18.2, IC5.4 (V+), R22.1; also elsewhere on the board
+5V_ISO: IC4.12 (VL); also elsewhere on the board
+15V_ISO: IC4.13 (V+); also elsewhere on the board
-2V5_ISO: C19.2, IC5.11 (V-), R25.2; also elsewhere on the board
-15V_ISO: IC4.4 (V-); also elsewhere on the board
AIN3P: L3.2; also elsewhere on the board
GND: C18.1, C19.1, D1.A, D2.C, IC4.5 (GND), IC4.9 (IN), JP5.1, OK2.2 (C), R13.1, R23.2, R24.1; also elsewhere on the board
HI_CLAMP: IC5.5 (+IN), R22.2, R23.1; also elsewhere on the board
IN3N: D1.C, D2.A, JP5.2, R13.2, R20.1; also elsewhere on the board
IN3P: D3.3 (AC), IC4.2 (D), IC4.7 (D), IC4.15 (D), IC5.2 (-IN), IC5.6 (-IN); also elsewhere on the board
LO_CLAMP: IC5.3 (+IN), R24.2, R25.1; also elsewhere on the board
unnamed: D3.1 (A), IC5.1 (OUT)
unnamed: D3.2 (C), IC5.7 (OUT)
unnamed: IC4.3 (S), R16.1, R17.2
unnamed: IC4.14 (S), R18.1, R20.2
unnamed: IC4.6 (S), R21.1
unnamed: OK2.1 (A), R26.2
unnamed: OK2.4 (S1), R19.2
unnamed: L3.1, OK2.3 (S2), R14.2
unnamed: R14.1, R15.2
unnamed: R15.1, R16.2
unnamed: R17.1, R18.2
unnamed: R19.1, R21.2
USEL1#3: IC4.8 (IN), R26.1; also elsewhere on the board
USEL20#3: IC4.1 (IN); also elsewhere on the board
USEL100#3: IC4.16 (IN); also elsewhere on the board

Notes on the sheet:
-2.42V
Current
USEL100
ISEL
Licensed under the TAPR Open Hardware License (www.tapr.org/OHL) More info at http://www.envox.eu/eez-bb3 Repository: https://github.com/eez-open
÷100
USEL20
+2.42V
Voltage 1/1
Voltage mode: ±2.4 V, ±48 V, ±240 V
Voltage 1/100
Clamp references
Voltage 1/20
USEL1
÷20

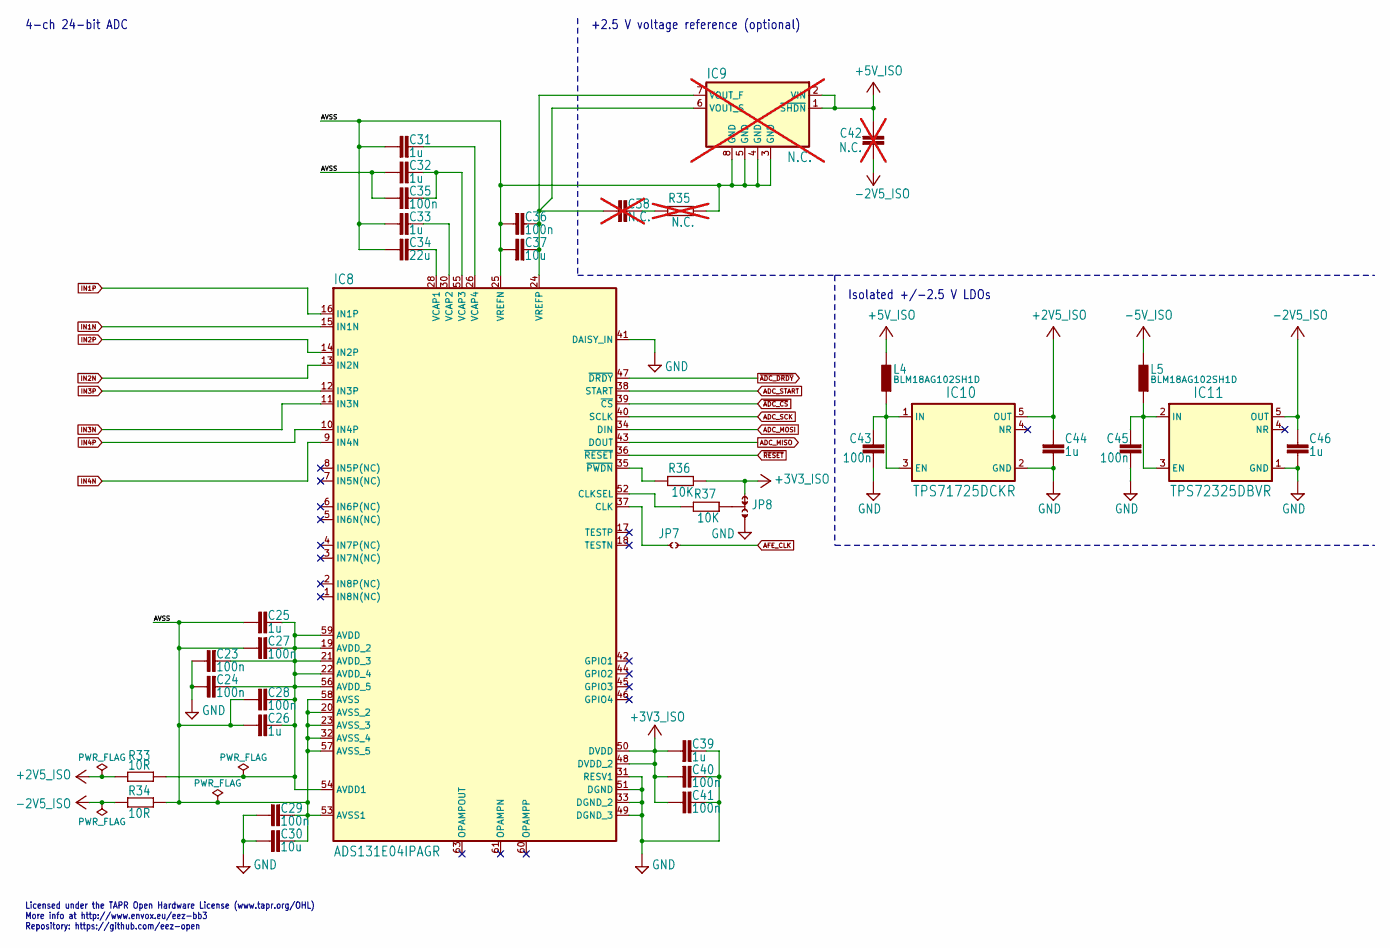
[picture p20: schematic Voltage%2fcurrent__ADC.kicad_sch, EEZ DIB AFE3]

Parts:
C23, C24, C27, C28, C29, C35, C36, C40, C41, C43, C45: 100n; C_0603_1608Metric; DigiKey 490-4774-1-ND
C25, C26, C31, C32, C33, C39, C44, C46: 1u; C_0603_1608Metric; DigiKey 1276-1019-1-ND
C30, C37: 10u; C_1206_3216Metric; DigiKey 1276-2872-1-ND
C34: 22u; C_1206_3216Metric; DigiKey 1276-3373-1-ND
C38, C42: N.C.; C_1206_3216Metric; not fitted
IC8: ADS131E04IPAGR; PAG64; DigiKey 296-34885-1-ND
IC9: N.C.; MSOP-8_MS_LIT; DigiKey 505-LTC6655BHMS8-2.5#TRPBFTR-ND; not fitted
IC10: TPS71725DCKR; DCK5; DigiKey 296-21525-1-ND
IC11: TPS72325DBVR; DBV5; DigiKey 296-39479-1-ND
JP7: JP2-CUT-0805; JP2 open
JP8: JP3-CUT-0805-ROTATED; JP3 shorted
L4, L5: BLM18AG102SH1D; BEAD0603; DigiKey 490-7809-1-ND
R33, R34: 10R; R_0805_2012Metric; DigiKey 2019-RK73H2ATTD10R0FCT-ND
R35: N.C.; R_0805_2012Metric; not fitted
R36, R37: 10K; R_0805_2012Metric; DigiKey 311-10.0KCRCT-ND

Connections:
+2V5_ISO: C44.2, IC10.5 (OUT), R33.1; also elsewhere on the board
+3V3_ISO: C39.1, C40.2, C41.2, IC8.48 (DVDD_2), IC8.50 (DVDD), JP8.NC, R36.2; also elsewhere on the board
+5V_ISO: C42.1, IC9.1 (~SHDN), IC9.2 (VIN), L4.2; also elsewhere on the board
-2V5_ISO: C42.2, C46.2, IC11.5 (OUT), R34.2; also elsewhere on the board
-5V_ISO: L5.2; also elsewhere on the board
/Voltage/current ADC/AVSS: C25.1, C26.1, C27.2, C28.2, C29.1, C30.1, C31.1, C32.1, C33.1, C34.1, C35.2, C36.2, C37.2, IC8.20 (AVSS_2), IC8.23 (AVSS_3), IC8.25 (VREFN), IC8.32 (AVSS_4), IC8.53 (AVSS1), IC8.57 (AVSS_5), IC8.58 (AVSS), IC9.3 (GND), IC9.4 (GND), IC9.5 (GND), IC9.8 (GND), R34.1, R35.2
ADC_MISO: IC8.43 (DOUT); also elsewhere on the board
ADC_MOSI: IC8.34 (DIN); also elsewhere on the board
ADC_SCK: IC8.40 (SCLK); also elsewhere on the board
ADC_START: IC8.38 (START); also elsewhere on the board
AFE_CLK: JP7.1; also elsewhere on the board
GND: C23.2, C24.2, C29.2, C30.2, C39.2, C40.1, C41.1, C43.2, C44.1, C45.2, C46.1, IC8.31 (RESV1), IC8.33 (DGND_2), IC8.41 (DAISY_IN), IC8.49 (DGND_3), IC8.51 (DGND), IC10.2 (GND), IC11.1 (GND), JP8.NO; also elsewhere on the board
IN1N: IC8.15 (IN1N); also elsewhere on the board
IN1P: IC8.16 (IN1P); also elsewhere on the board
IN2N: IC8.13 (IN2N); also elsewhere on the board
IN2P: IC8.14 (IN2P); also elsewhere on the board
IN3N: IC8.11 (IN3N); also elsewhere on the board
IN3P: IC8.12 (IN3P); also elsewhere on the board
IN4N: IC8.9 (IN4N); also elsewhere on the board
IN4P: IC8.10 (IN4P); also elsewhere on the board
unnamed: C38.2, R35.1
unnamed: C23.1, C24.1, C25.2, C26.2, C27.1, C28.1, IC8.19 (AVDD_2), IC8.21 (AVDD_3), IC8.22 (AVDD_4), IC8.54 (AVDD1), IC8.56 (AVDD_5), IC8.59 (AVDD), R33.2
unnamed: IC8.37 (CLK), JP7.2
unnamed: IC8.52 (CLKSEL), R37.1
unnamed: C34.2, IC8.28 (VCAP1)
unnamed: C33.2, IC8.30 (VCAP2)
unnamed: C32.2, C35.1, IC8.55 (VCAP3)
unnamed: C31.2, IC8.26 (VCAP4)
unnamed: C36.1, C37.1, C38.1, IC8.24 (VREFP), IC9.6 (VOUT_S), IC9.7 (VOUT_F)
unnamed: IC8.35 (~PWDN), R36.1
unnamed: C43.1, IC10.1 (IN), IC10.3 (EN), L4.1
unnamed: C45.1, IC11.2 (IN), IC11.3 (EN), L5.1
unnamed: JP8.COM, R37.2
~ADC_CS: IC8.39 (~CS); also elsewhere on the board
~ADC_DRDY: IC8.47 (~DRDY); also elsewhere on the board
~RESET: IC8.36 (~RESET); also elsewhere on the board

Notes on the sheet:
4-ch 24-bit ADC
Isolated +/-2.5 V LDOs
+2.5 V voltage reference (optional)
Licensed under the TAPR Open Hardware License (www.tapr.org/OHL) More info at http://www.envox.eu/eez-bb3 Repository: https://github.com/eez-open

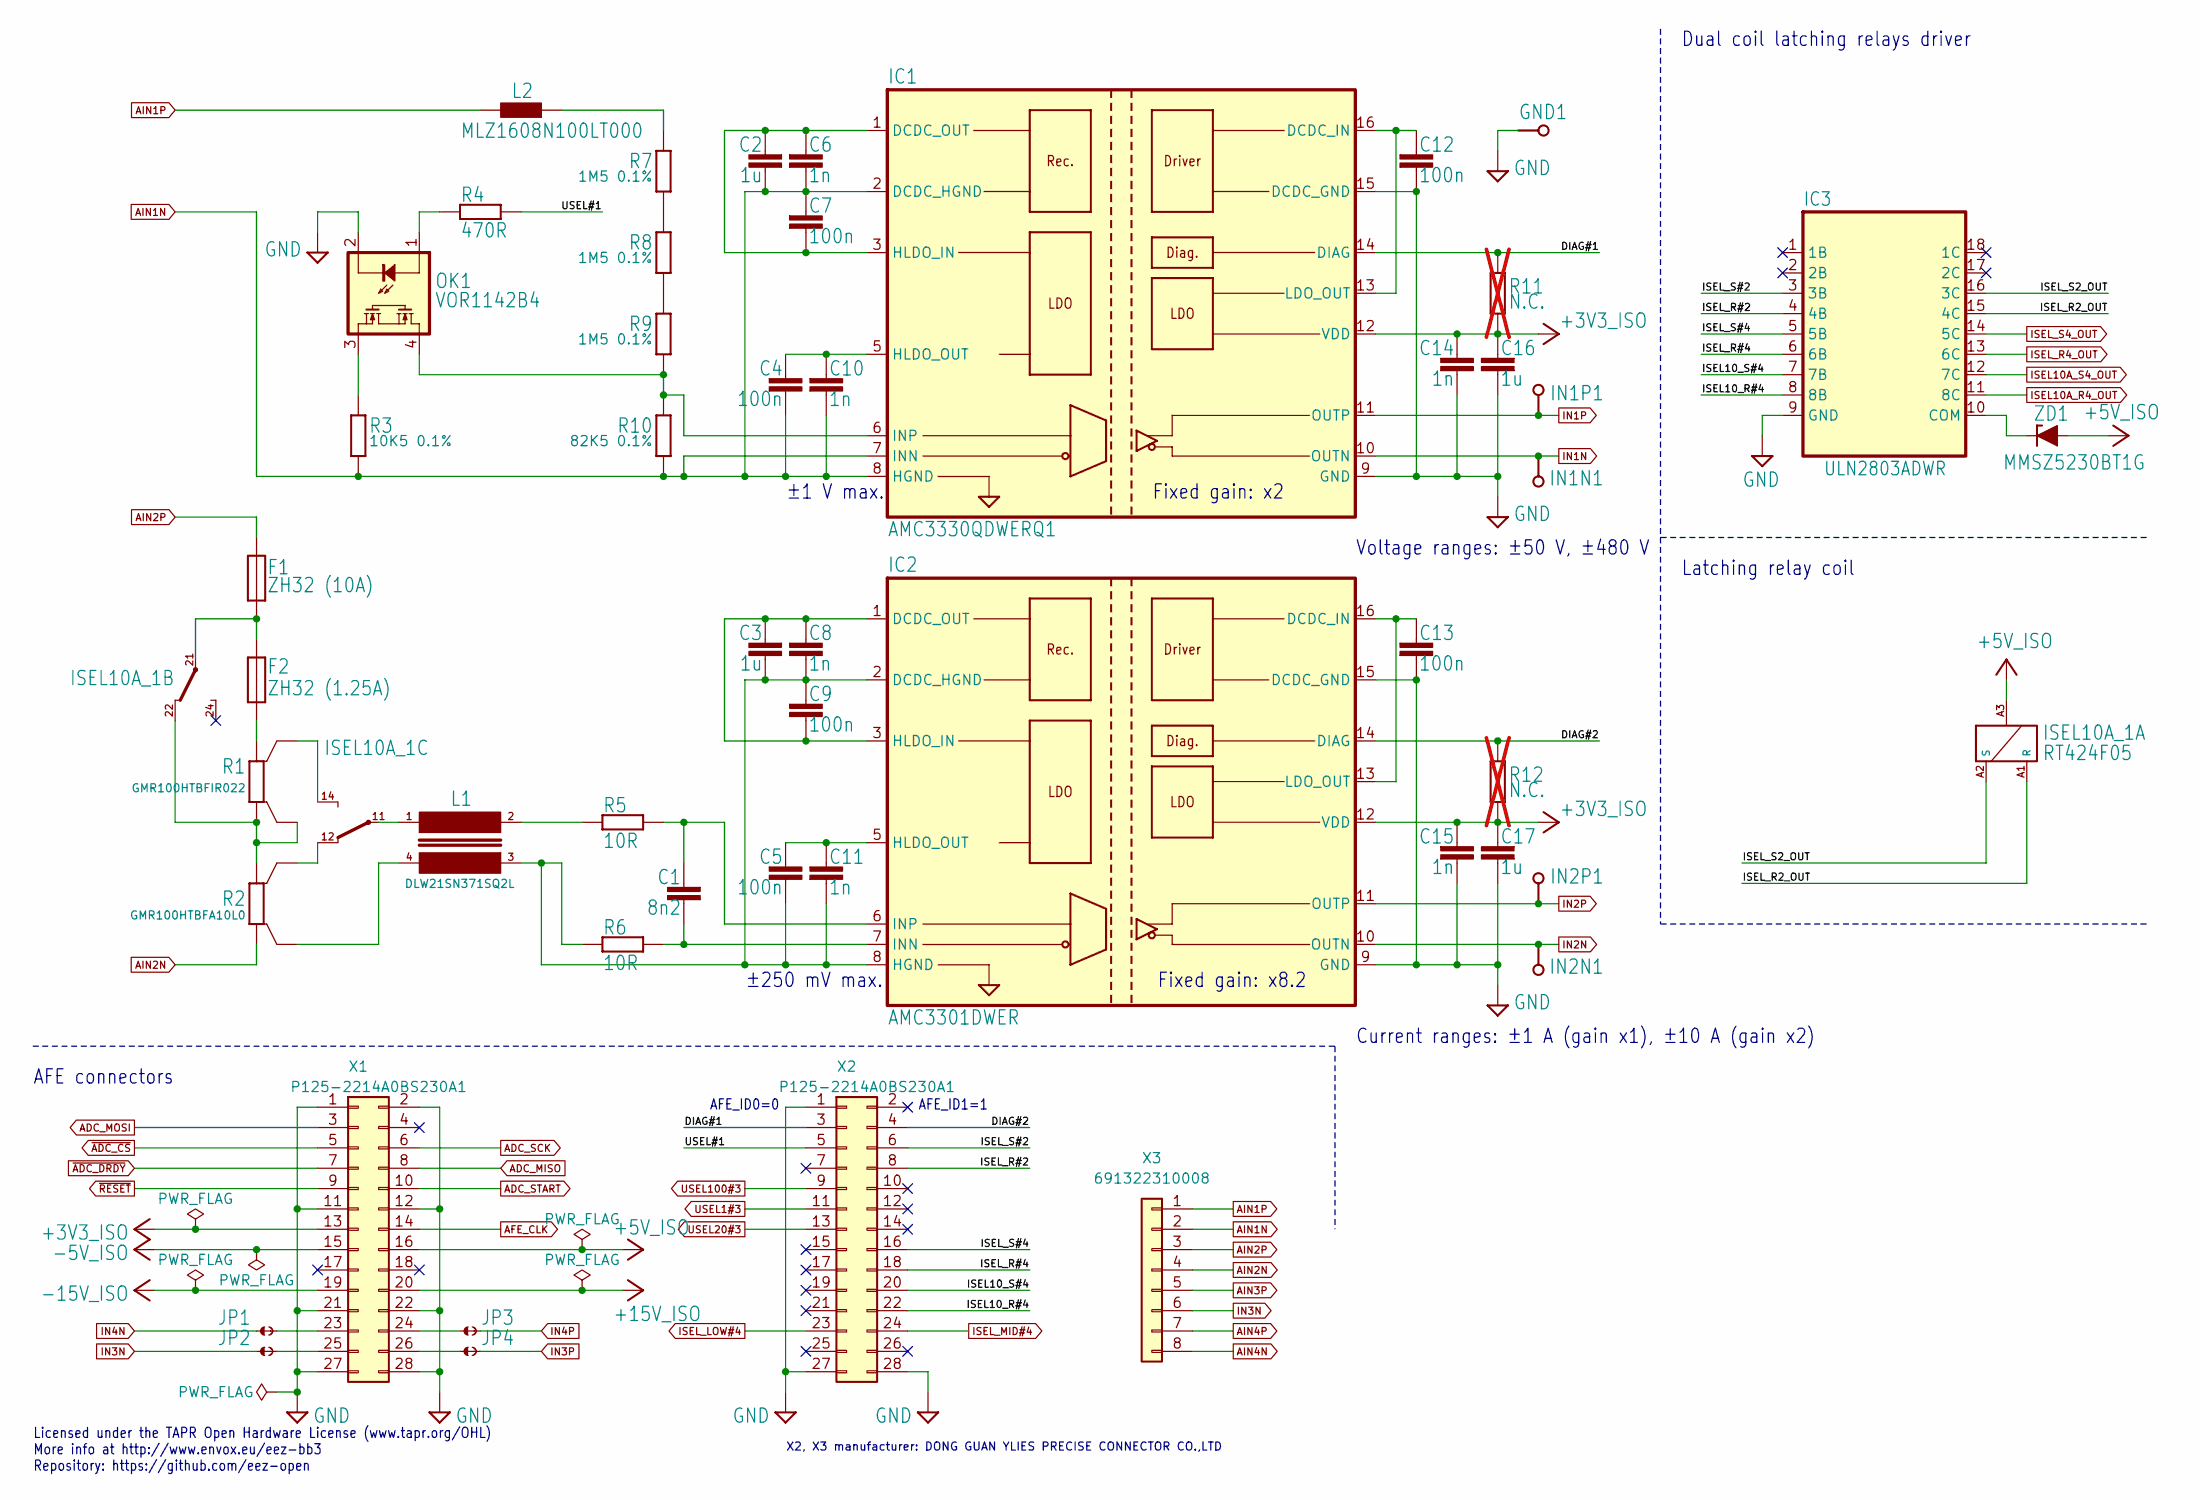
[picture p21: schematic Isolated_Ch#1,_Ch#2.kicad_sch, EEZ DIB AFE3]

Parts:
C1: 8n2; C_0603_1608Metric; DigiKey 311-1811-1-ND
C2, C3: 1u; C_0603_1608Metric; DigiKey 1276-1019-1-ND
C4, C5: 100n; C_1206_3216Metric; DigiKey 399-C1206C104K5RAC7800CT-ND
C6, C8: 1n; C_0603_1608Metric; DigiKey 1276-1018-1-ND
C7, C9, C12, C13: 100n; C_0603_1608Metric; DigiKey 490-4774-1-ND
C10, C11, C14, C15: 1n; C_1206_3216Metric; DigiKey 732-8115-1-ND
C16, C17: 1u; C_1206_3216Metric; DigiKey 1276-3091-1-ND
F1: ZH32 (10A); ZH32; DigiKey 732-11370-ND
F2: ZH32 (1.25A); ZH32; DigiKey 732-11370-ND
GND1: PCB_TEST_TABSHIELD; Testhole 24_50mils
IC1: AMC3330QDWERQ1; DW16; DigiKey 296-AMC3330DWERCT-ND
IC2: AMC3301DWER; DW16; DigiKey 296-AMC3301QDWERQ1CT-ND
IC3: ULN2803ADWR; DW18_TEX-M; DigiKey 296-15777-1-ND
IN1N1, IN1P1, IN2N1, IN2P1: PCB_TEST_TABSHIELD; Testhole 24_50mils
ISEL10A_1: RT424F05; DigiKey PB2024-ND
JP1, JP2, JP3, JP4: JP2-NOCUT-0805; JP2 shorted
L1: DLW21SN371SQ2L; IND_DLW21S_0805_MUR-M; DigiKey 490-5141-1-ND
L2: MLZ1608N100LT000; BEAD0603; DigiKey 445-6755-1-ND
OK1: VOR1142B4; DIL4-SMD; DigiKey VOR1142B4-ND
R1: GMR100HTBFIR022; R_2512-4WIRE; DigiKey 511-1688-1-ND
R2: GMR100HTBFA10L0; R_2512-4WIRE; DigiKey 511-1686-1-ND
R3: 10K5 0.1%; R_1206_3216Metric; DigiKey A140954CT-ND
R4: 470R; R_0805_2012Metric; DigiKey 311-470CRCT-ND
R5, R6: 10R; R_0805_2012Metric; DigiKey 2019-RK73H2ATTD10R0FCT-ND
R7, R8, R9: 1M5 0.1%; R_1206_3216Metric; DigiKey RG3216P-1504-B-T1
R10: 82K5 0.1%; R_1206_3216Metric; DigiKey RQ73C2B82K5BTD
R11, R12: N.C.; R_0805_2012Metric; not fitted
X1, X2: P125-2214A0BS230A1
X3: 691322310008; DigiKey 732-2093-ND
ZD1: MMSZ5230BT1G; SOD123; DigiKey MMSZ5230BT1GOSCT-ND

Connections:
+3V3_ISO: C14.1, C15.1, C16.1, C17.1, IC1.12 (VDD), IC2.12 (VDD), R11.2, R12.2, X1.13; also elsewhere on the board
+5V_ISO: ISEL10A_1.A3, X1.16, ZD1.A; also elsewhere on the board
+15V_ISO: X1.20; also elsewhere on the board
-5V_ISO: X1.15; also elsewhere on the board
-15V_ISO: X1.19; also elsewhere on the board
/Isolated Ch#1, Ch#2/DIAG#1: IC1.14 (DIAG), R11.1, X2.3
/Isolated Ch#1, Ch#2/DIAG#2: IC2.14 (DIAG), R12.1, X2.4
/Isolated Ch#1, Ch#2/ISEL10_R#4: IC3.8 (8B), X2.22
/Isolated Ch#1, Ch#2/ISEL10_S#4: IC3.7 (7B), X2.20
/Isolated Ch#1, Ch#2/ISEL_R2_OUT: IC3.15 (4C), ISEL10A_1.A1 (R)
/Isolated Ch#1, Ch#2/ISEL_R#2: IC3.4 (4B), X2.8
/Isolated Ch#1, Ch#2/ISEL_R#4: IC3.6 (6B), X2.18
/Isolated Ch#1, Ch#2/ISEL_S2_OUT: IC3.16 (3C), ISEL10A_1.A2 (S)
/Isolated Ch#1, Ch#2/ISEL_S#2: IC3.3 (3B), X2.6
/Isolated Ch#1, Ch#2/ISEL_S#4: IC3.5 (5B), X2.16
/Isolated Ch#1, Ch#2/USEL#1: R4.2, X2.5
ADC_MISO: X1.8; also elsewhere on the board
ADC_MOSI: X1.3; also elsewhere on the board
ADC_SCK: X1.6; also elsewhere on the board
ADC_START: X1.10; also elsewhere on the board
AFE_CLK: X1.14; also elsewhere on the board
AIN1N: C2.2, C4.2, C6.2, C7.1, C10.2, IC1.2 (DCDC_HGND), IC1.7 (INN), IC1.8 (HGND), R3.1, R10.1, X3.2; also elsewhere on the board
AIN1P: L2.2, X3.1; also elsewhere on the board
AIN2N: R2.1, X3.4; also elsewhere on the board
AIN2P: F1.2, X3.3; also elsewhere on the board
GND: C12.2, C13.2, C14.2, C15.2, C16.2, C17.2, GND1.1, IC1.9 (GND), IC1.15 (DCDC_GND), IC2.9 (GND), IC2.15 (DCDC_GND), IC3.9 (GND), OK1.2 (C), X1.1, X1.2, X1.11, X1.12, X1.21, X1.22, X1.27, X1.28, X2.1, X2.27, X2.28; also elsewhere on the board
IN1N: IC1.10 (OUTN), IN1N1.1; also elsewhere on the board
IN1P: IC1.11 (OUTP), IN1P1.1; also elsewhere on the board
IN2N: IC2.10 (OUTN), IN2N1.1; also elsewhere on the board
IN2P: IC2.11 (OUTP), IN2P1.1; also elsewhere on the board
IN3N: JP2.1, X3.6; also elsewhere on the board
IN3P: JP4.2; also elsewhere on the board
IN4N: JP1.1; also elsewhere on the board
IN4P: JP3.2; also elsewhere on the board
ISEL10A_R4_OUT: IC3.11 (8C); also elsewhere on the board
ISEL10A_S4_OUT: IC3.12 (7C); also elsewhere on the board
ISEL_LOW#4: X2.23; also elsewhere on the board
ISEL_MID#4: X2.24; also elsewhere on the board
ISEL_R4_OUT: IC3.13 (6C); also elsewhere on the board
ISEL_S4_OUT: IC3.14 (5C); also elsewhere on the board
unnamed: F1.1, F2.1, ISEL10A_1.21
unnamed: F2.2, R1.2
unnamed: C12.1, IC1.13 (LDO_OUT), IC1.16 (DCDC_IN)
unnamed: C2.1, C6.1, C7.2, IC1.1 (DCDC_OUT), IC1.3 (HLDO_IN)
unnamed: C4.1, C10.1, IC1.5 (HLDO_OUT)
unnamed: IC1.6 (INP), OK1.4 (S1), R9.1, R10.2
unnamed: C3.2, C5.2, C8.2, C9.1, C11.2, IC2.2 (DCDC_HGND), IC2.8 (HGND), L1.3, R6.2
unnamed: C13.1, IC2.13 (LDO_OUT), IC2.16 (DCDC_IN)
unnamed: C3.1, C8.1, C9.2, IC2.1 (DCDC_OUT), IC2.3 (HLDO_IN)
unnamed: C5.1, C11.1, IC2.5 (HLDO_OUT)
unnamed: C1.2, IC2.7 (INN), R6.1
unnamed: C1.1, IC2.6 (INP), R5.1
unnamed: IC3.10 (COM), ZD1.C
unnamed: ISEL10A_1.11, L1.1
unnamed: ISEL10A_1.12, R2.2S
unnamed: ISEL10A_1.14, R1.2S
unnamed: ISEL10A_1.22, R1.1, R1.1S, R2.2
unnamed: L1.2, R5.2
unnamed: L1.4, R2.1S
unnamed: L2.1, R7.2
unnamed: OK1.1 (A), R4.1
unnamed: OK1.3 (S2), R3.2
unnamed: R7.1, R8.2
unnamed: R8.1, R9.2
unnamed: JP1.2, X1.23
unnamed: JP3.1, X1.24
unnamed: JP2.2, X1.25
unnamed: JP4.1, X1.26
USEL1#3: X2.11; also elsewhere on the board
USEL20#3: X2.13; also elsewhere on the board
USEL100#3: X2.9; also elsewhere on the board
~ADC_CS: X1.5; also elsewhere on the board
~ADC_DRDY: X1.7; also elsewhere on the board
~RESET: X1.9; also elsewhere on the board

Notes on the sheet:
Current ranges: ±1 A (gain x1), ±10 A (gain x2)
AFE_ID1=1
Licensed under the TAPR Open Hardware License (www.tapr.org/OHL) More info at http://www.envox.eu/eez-bb3 Repository: https://github.com/eez-open
±250 mV max.
Fixed gain: x2
AFE connectors
Voltage ranges: ±50 V, ±480 V
Dual coil latching relays driver
±1 V max.
Latching relay coil
AFE_ID0=0
Fixed gain: x8.2
X2, X3 manufacturer: DONG GUAN YLIES PRECISE CONNECTOR CO.,LTD

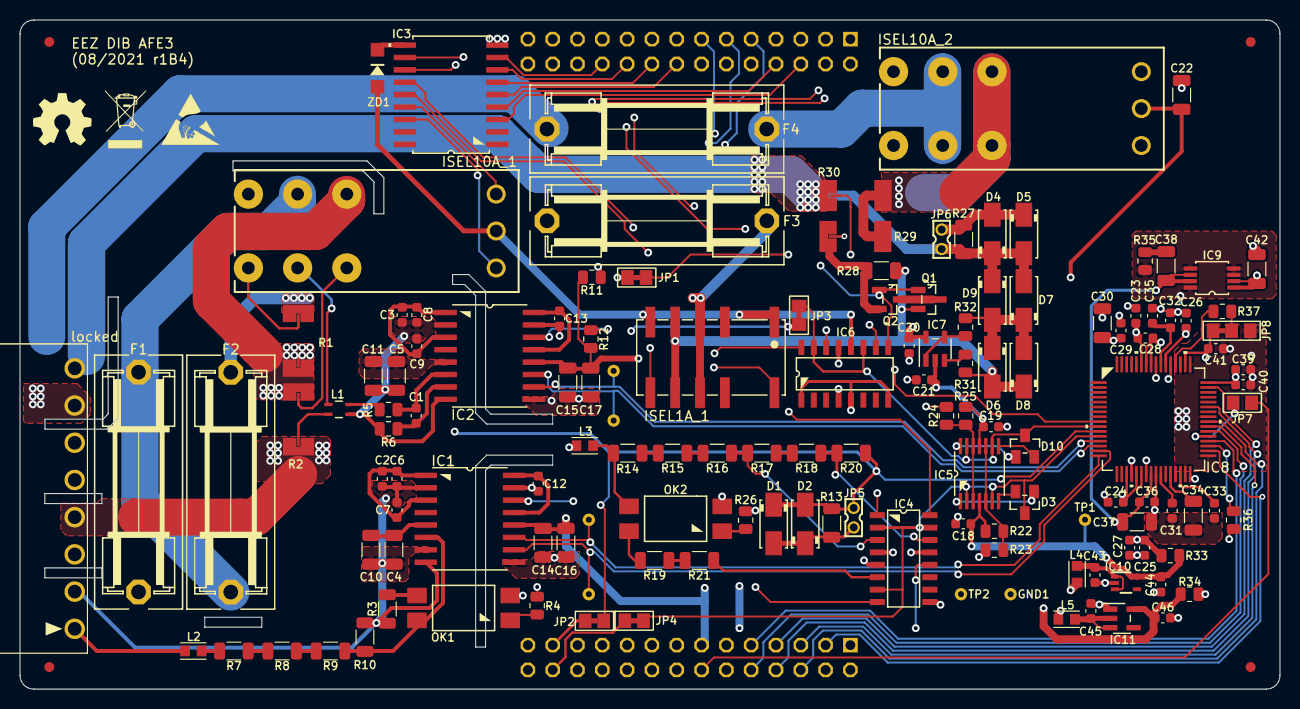
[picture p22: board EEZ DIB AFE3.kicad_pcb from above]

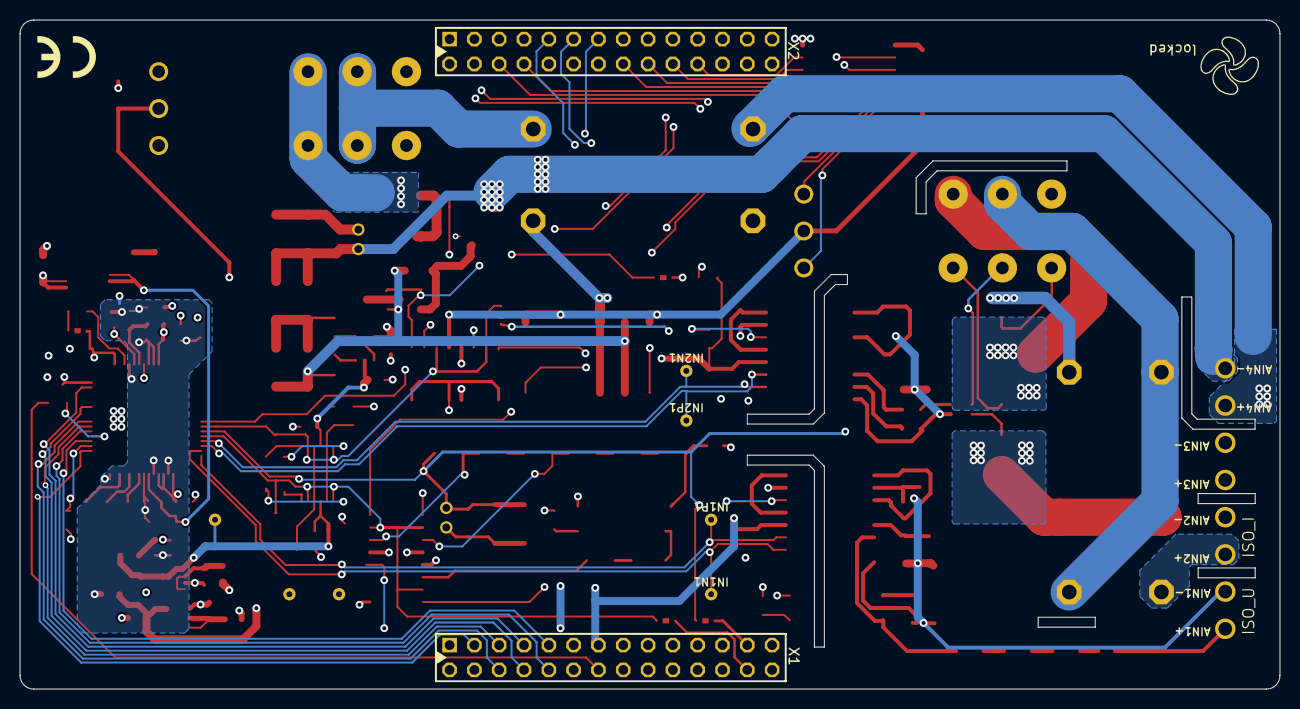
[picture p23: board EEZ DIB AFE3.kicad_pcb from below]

Board: 4 copper layers, 129.0 x 68.5 mm, 148 parts (8 on the bottom side), 120 nets.

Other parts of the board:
locked: 691322310008

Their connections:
AIN1N: locked.2; also elsewhere on the board
AIN1P: locked.1; also elsewhere on the board
AIN2N: locked.4; also elsewhere on the board
AIN2P: locked.3; also elsewhere on the board
AIN3P: locked.5; also elsewhere on the board
AIN4N: locked.8; also elsewhere on the board
AIN4P: locked.7; also elsewhere on the board
IN3N: locked.6; also elsewhere on the board

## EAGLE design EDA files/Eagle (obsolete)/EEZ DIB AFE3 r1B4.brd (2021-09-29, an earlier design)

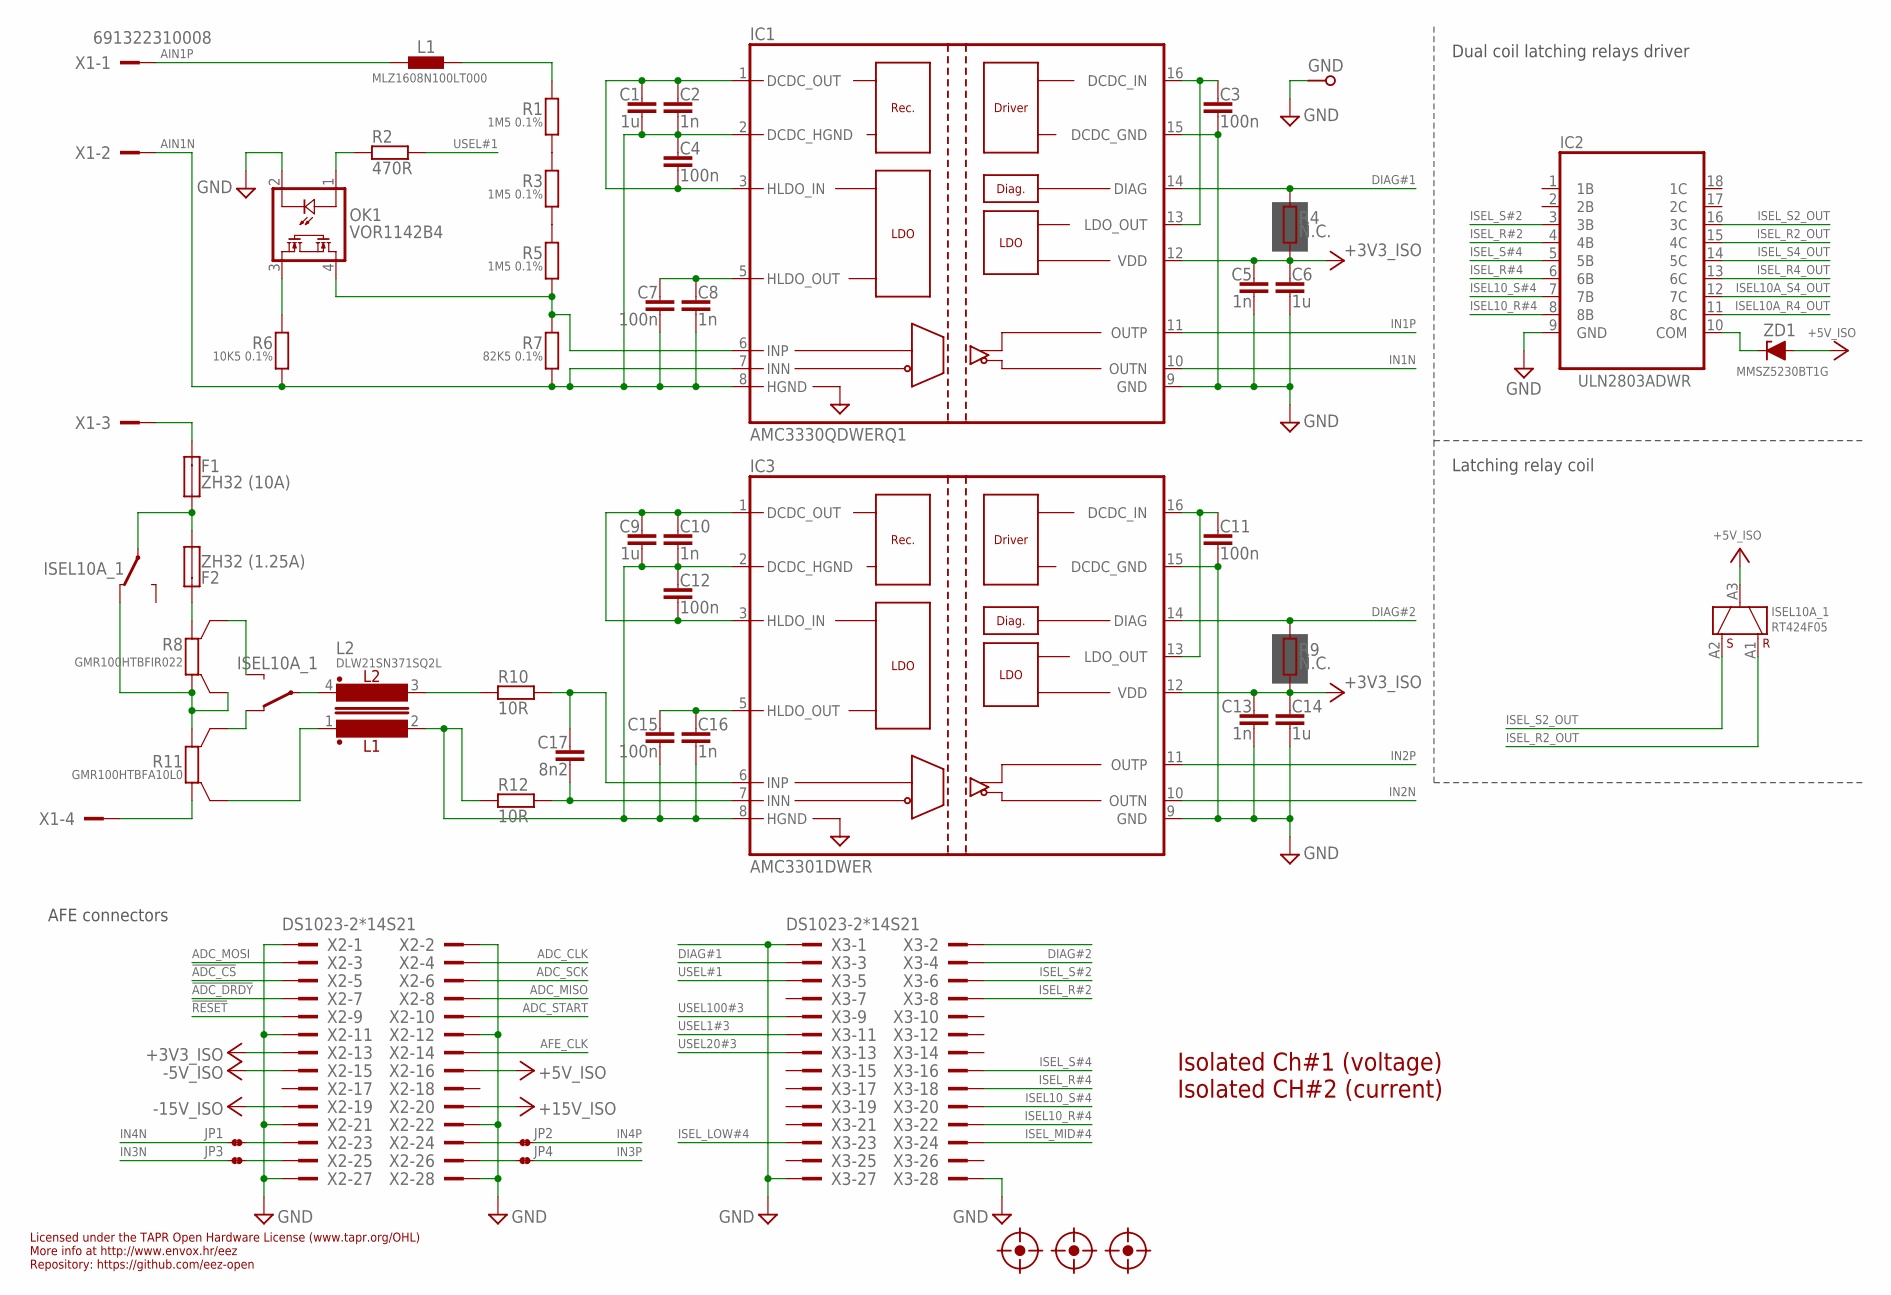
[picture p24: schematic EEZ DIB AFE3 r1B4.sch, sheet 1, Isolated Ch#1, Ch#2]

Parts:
C1, C9: 1u; C0603
C2, C10: 1n; C0603
C3, C4, C11, C12: 100n; C0603
C5, C8, C13, C16: 1n; C1206
C6, C14: 1u; C1206
C7, C15: 100n; C1206
C17: 8n2; C0603
F1: ZH32 (10A); ZH32
F2: ZH32 (1.25A); ZH32
FM1, FM2, FM3: FIDUCIAL_2; FIDUCIAL_DUAL
GND: PCB_TEST_TABSHIELD; PCB_SHIELD_TAB
IC1: AMC3330QDWERQ1; DW16
IC2: ULN2803ADWR; DW18_TEX-M
IC3: AMC3301DWER; DW16
ISEL10A_1: RT424F05; RT424FXX
JP1, JP2, JP3, JP4: JP2-NOCUT-0805; JP2-0805-NOCUT
L1: MLZ1608N100LT000; BEAD0603
L2: DLW21SN371SQ2L; MURATA_DLW21S
OK1: VOR1142B4; DIL4-SMD
R1, R3, R5: 1M5 0.1%; R1206
R2: 470R; R0805
R4, R9: N.C.; R0805
R6: 10K5 0.1%; R1206
R7: 82K5 0.1%; R1206
R8: GMR100HTBFIR022; R_2512-4WIRE
R10, R12: 10R; R0805
R11: GMR100HTBFA10L0; R_2512-4WIRE
X1: 691322310008
X2, X3: DS1023-2*14S21; TSW-114-07-F-D
ZD1: MMSZ5230BT1G; SOD123

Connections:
!ADC_CS: X2.5; also elsewhere on the board
!ADC_DRDY: X2.7; also elsewhere on the board
!RESET: X2.9; also elsewhere on the board
+3V3_ISO: C5.1, C6.1, C13.1, C14.1, IC1.12 (VDD), IC3.12 (VDD), R4.2, R9.2, X2.13; also elsewhere on the board
+5V_ISO: ISEL10A_1.A3 (COM), X2.16, ZD1.A; also elsewhere on the board
+15V_ISO: X2.20; also elsewhere on the board
-5V_ISO: X2.15; also elsewhere on the board
-15V_ISO: X2.19; also elsewhere on the board
ADC_CLK: X2.4; also elsewhere on the board
ADC_MISO: X2.8; also elsewhere on the board
ADC_MOSI: X2.3; also elsewhere on the board
ADC_SCK: X2.6; also elsewhere on the board
ADC_START: X2.10; also elsewhere on the board
AFE_CLK: X2.14
AIN1N: C1.2, C2.2, C4.1, C7.2, C8.2, IC1.2 (DCDC_HGND), IC1.7 (INN), IC1.8 (HGND), R6.1, R7.1, X1.2
AIN1P: L1.P$2 (2), X1.1
AIN2N: R11.1, X1.4
AIN2P: F1.2, X1.3
DIAG#1: IC1.14 (DIAG), R4.1, X3.3
DIAG#2: IC3.14 (DIAG), R9.1, X3.4
GND: C3.2, C5.2, C6.2, C11.2, C13.2, C14.2, GND.1, IC1.9 (GND), IC1.15 (DCDC_GND), IC2.9 (GND), IC3.9 (GND), IC3.15 (DCDC_GND), OK1.2 (C), X2.1, X2.2, X2.11, X2.12, X2.21, X2.22, X2.27, X2.28, X3.1, X3.27, X3.28; also elsewhere on the board
GNDI1: C9.2, C10.2, C12.1, C15.2, C16.2, IC3.2 (DCDC_HGND), IC3.8 (HGND), L2.2, R12.2
HI_FORCE+: ISEL10A_1.12 (NC), R8.1, R8.1S, R11.2
HI_SENSE+: ISEL10A_1.22 (NC), R11.2S
IN1N: IC1.10 (OUTN); also elsewhere on the board
IN1P: IC1.11 (OUTP); also elsewhere on the board
IN2N: IC3.10 (OUTN); also elsewhere on the board
IN2P: IC3.11 (OUTP); also elsewhere on the board
IN3N: JP3.1; also elsewhere on the board
IN3P: JP4.2; also elsewhere on the board
IN4N: JP1.1; also elsewhere on the board
IN4P: JP2.2; also elsewhere on the board
ISEL10A_R4_OUT: IC2.11 (8C); also elsewhere on the board
ISEL10A_S4_OUT: IC2.12 (7C); also elsewhere on the board
ISEL10_R#4: IC2.8 (8B), X3.22
ISEL10_S#4: IC2.7 (7B), X3.20
ISEL_LOW#4: X3.23; also elsewhere on the board
ISEL_MID#4: X3.24; also elsewhere on the board
ISEL_R2_OUT: IC2.15 (4C), ISEL10A_1.A1 (R)
ISEL_R4_OUT: IC2.13 (6C); also elsewhere on the board
ISEL_R#2: IC2.4 (4B), X3.8
ISEL_R#4: IC2.6 (6B), X3.18
ISEL_S2_OUT: IC2.16 (3C), ISEL10A_1.A2 (S)
ISEL_S4_OUT: IC2.14 (5C); also elsewhere on the board
ISEL_S#2: IC2.3 (3B), X3.6
ISEL_S#4: IC2.5 (5B), X3.16
LOW_SENSE+: ISEL10A_1.24 (NO), R8.2S
LO_FORCE-: F2.2, R8.2
unnamed: L1.P$1 (1), R1.2
unnamed: IC1.6 (INP), OK1.4 (S1), R5.1, R7.2
unnamed: R1.1, R3.2
unnamed: R3.1, R5.2
unnamed: OK1.3 (S2), R6.2
unnamed: C1.1, C2.1, C4.2, IC1.1 (DCDC_OUT), IC1.3 (HLDO_IN)
unnamed: C7.1, C8.1, IC1.5 (HLDO_OUT)
unnamed: C3.1, IC1.13 (LDO_OUT), IC1.16 (DCDC_IN)
unnamed: C17.1, IC3.6 (INP), R10.1
unnamed: C9.1, C10.1, C12.2, IC3.1 (DCDC_OUT), IC3.3 (HLDO_IN)
unnamed: C15.1, C16.1, IC3.5 (HLDO_OUT)
unnamed: C11.1, IC3.13 (LDO_OUT), IC3.16 (DCDC_IN)
unnamed: ISEL10A_1.21 (COM), L2.4
unnamed: F1.1, F2.1, ISEL10A_1.11 (COM)
unnamed: L2.1, R11.1S
unnamed: OK1.1 (A), R2.1
unnamed: L2.3, R10.2
unnamed: C17.2, IC3.7 (INN), R12.1
unnamed: IC2.10 (COM), ZD1.C
unnamed: JP1.2, X2.23
unnamed: JP3.2, X2.25
unnamed: JP2.1, X2.24
unnamed: JP4.1, X2.26
USEL1#3: X3.11; also elsewhere on the board
USEL20#3: X3.13; also elsewhere on the board
USEL100#3: X3.9; also elsewhere on the board
USEL#1: R2.2, X3.5

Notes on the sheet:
Licensed under the TAPR Open Hardware License (www.tapr.org/OHL)
Repository: https://github.com/eez-open
More info at http://www.envox.hr/eez
Isolated Ch#1 (voltage) Isolated CH#2 (current)
AFE connectors
Dual coil latching relays driver
Latching relay coil

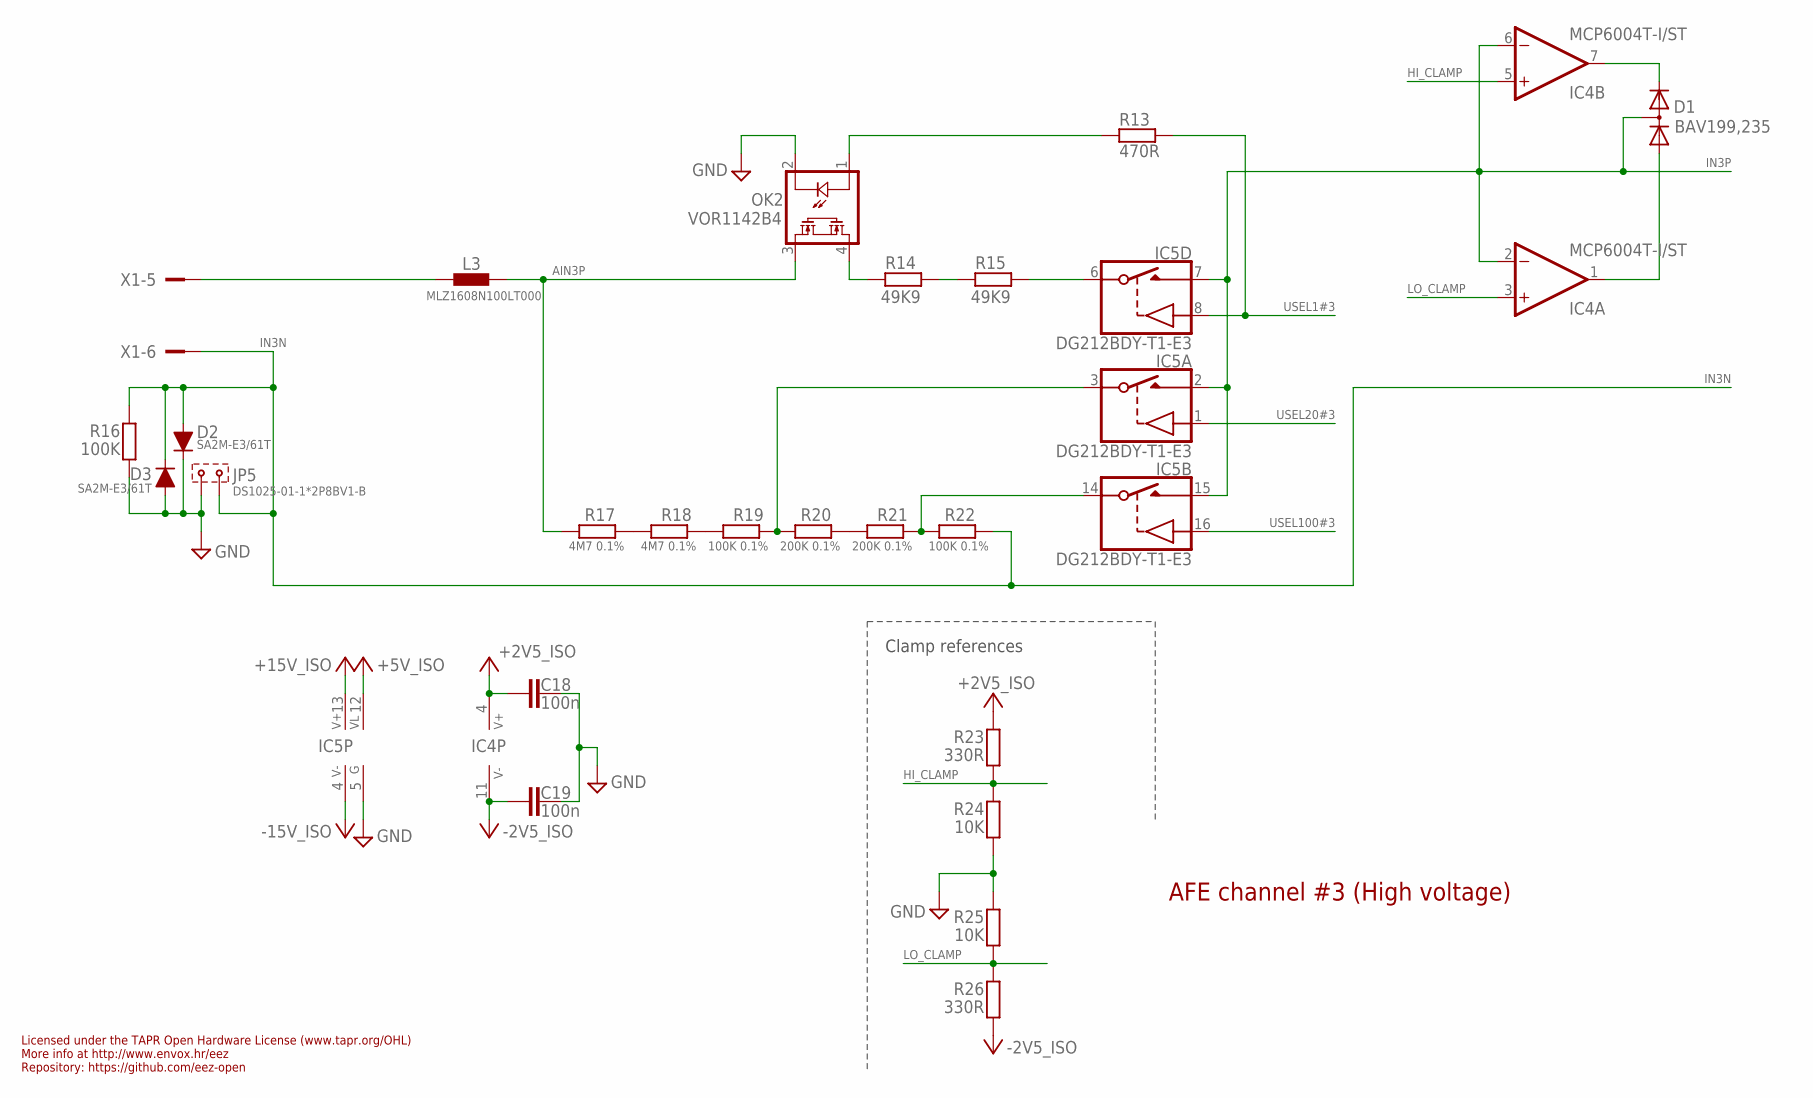
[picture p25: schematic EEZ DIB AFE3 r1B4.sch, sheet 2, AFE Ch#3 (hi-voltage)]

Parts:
C18, C19: 100n; C0603
D1: BAV199,235; SOT23
D2, D3: SA2M-E3/61T; SMA_NARROW
IC4: MCP6004T-I/ST; PW(R-PDSO-G14)
IC5: DG212BDY-T1-E3; SO16
JP5: DS1025-01-1*2P8BV1-B; 2MM-2
L3: MLZ1608N100LT000; BEAD0603
OK2: VOR1142B4; DIL4-SMD
R13: 470R; R0805
R14, R15: 49K9; R1206
R16: 100K; R1206
R17, R18: 4M7 0.1%; R1206
R19, R22: 100K 0.1%; R1206
R20, R21: 200K 0.1%; R1206
R23, R26: 330R; R0805
R24, R25: 10K; R0805
X1: 691322310008

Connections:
+2V5_ISO: C18.2, IC4.4 (V+), R23.1; also elsewhere on the board
+5V_ISO: IC5.12 (VL); also elsewhere on the board
+15V_ISO: IC5.13 (V+); also elsewhere on the board
-2V5_ISO: C19.2, IC4.11 (V-), R26.2; also elsewhere on the board
-15V_ISO: IC5.4 (V-); also elsewhere on the board
AIN3/20: IC5.3 (S), R19.1, R20.2
AIN3P: L3.P$1 (1), OK2.3 (S2), R17.2
GND: C18.1, C19.1, D2.1 (C), D3.2 (A), IC5.5 (GND), JP5.2, OK2.2 (C), R16.1, R24.2, R25.1; also elsewhere on the board
HI_CLAMP: IC4.5 (+IN), R23.2, R24.1; also elsewhere on the board
IN3N: D2.2 (A), D3.1 (C), JP5.1, R16.2, R22.1, X1.6; also elsewhere on the board
IN3P: D1.3 (AC), IC4.2 (-IN), IC4.6 (-IN), IC5.2 (D), IC5.7 (D), IC5.15 (D); also elsewhere on the board
LO_CLAMP: IC4.3 (+IN), R25.2, R26.1; also elsewhere on the board
unnamed: L3.P$2 (2), X1.5
unnamed: OK2.4 (S1), R14.2
unnamed: IC5.14 (S), R21.1, R22.2
unnamed: IC5.6 (S), R15.1
unnamed: D1.2 (C), IC4.7 (OUT)
unnamed: D1.1 (A), IC4.1 (OUT)
unnamed: R14.1, R15.2
unnamed: R20.1, R21.2
unnamed: R18.1, R19.2
unnamed: R17.1, R18.2
unnamed: OK2.1 (A), R13.2
USEL1#3: IC5.8 (IN), R13.1; also elsewhere on the board
USEL20#3: IC5.1 (IN); also elsewhere on the board
USEL100#3: IC5.16 (IN); also elsewhere on the board

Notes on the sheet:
Licensed under the TAPR Open Hardware License (www.tapr.org/OHL)
Repository: https://github.com/eez-open
More info at http://www.envox.hr/eez
AFE channel #3 (High voltage)
Clamp references

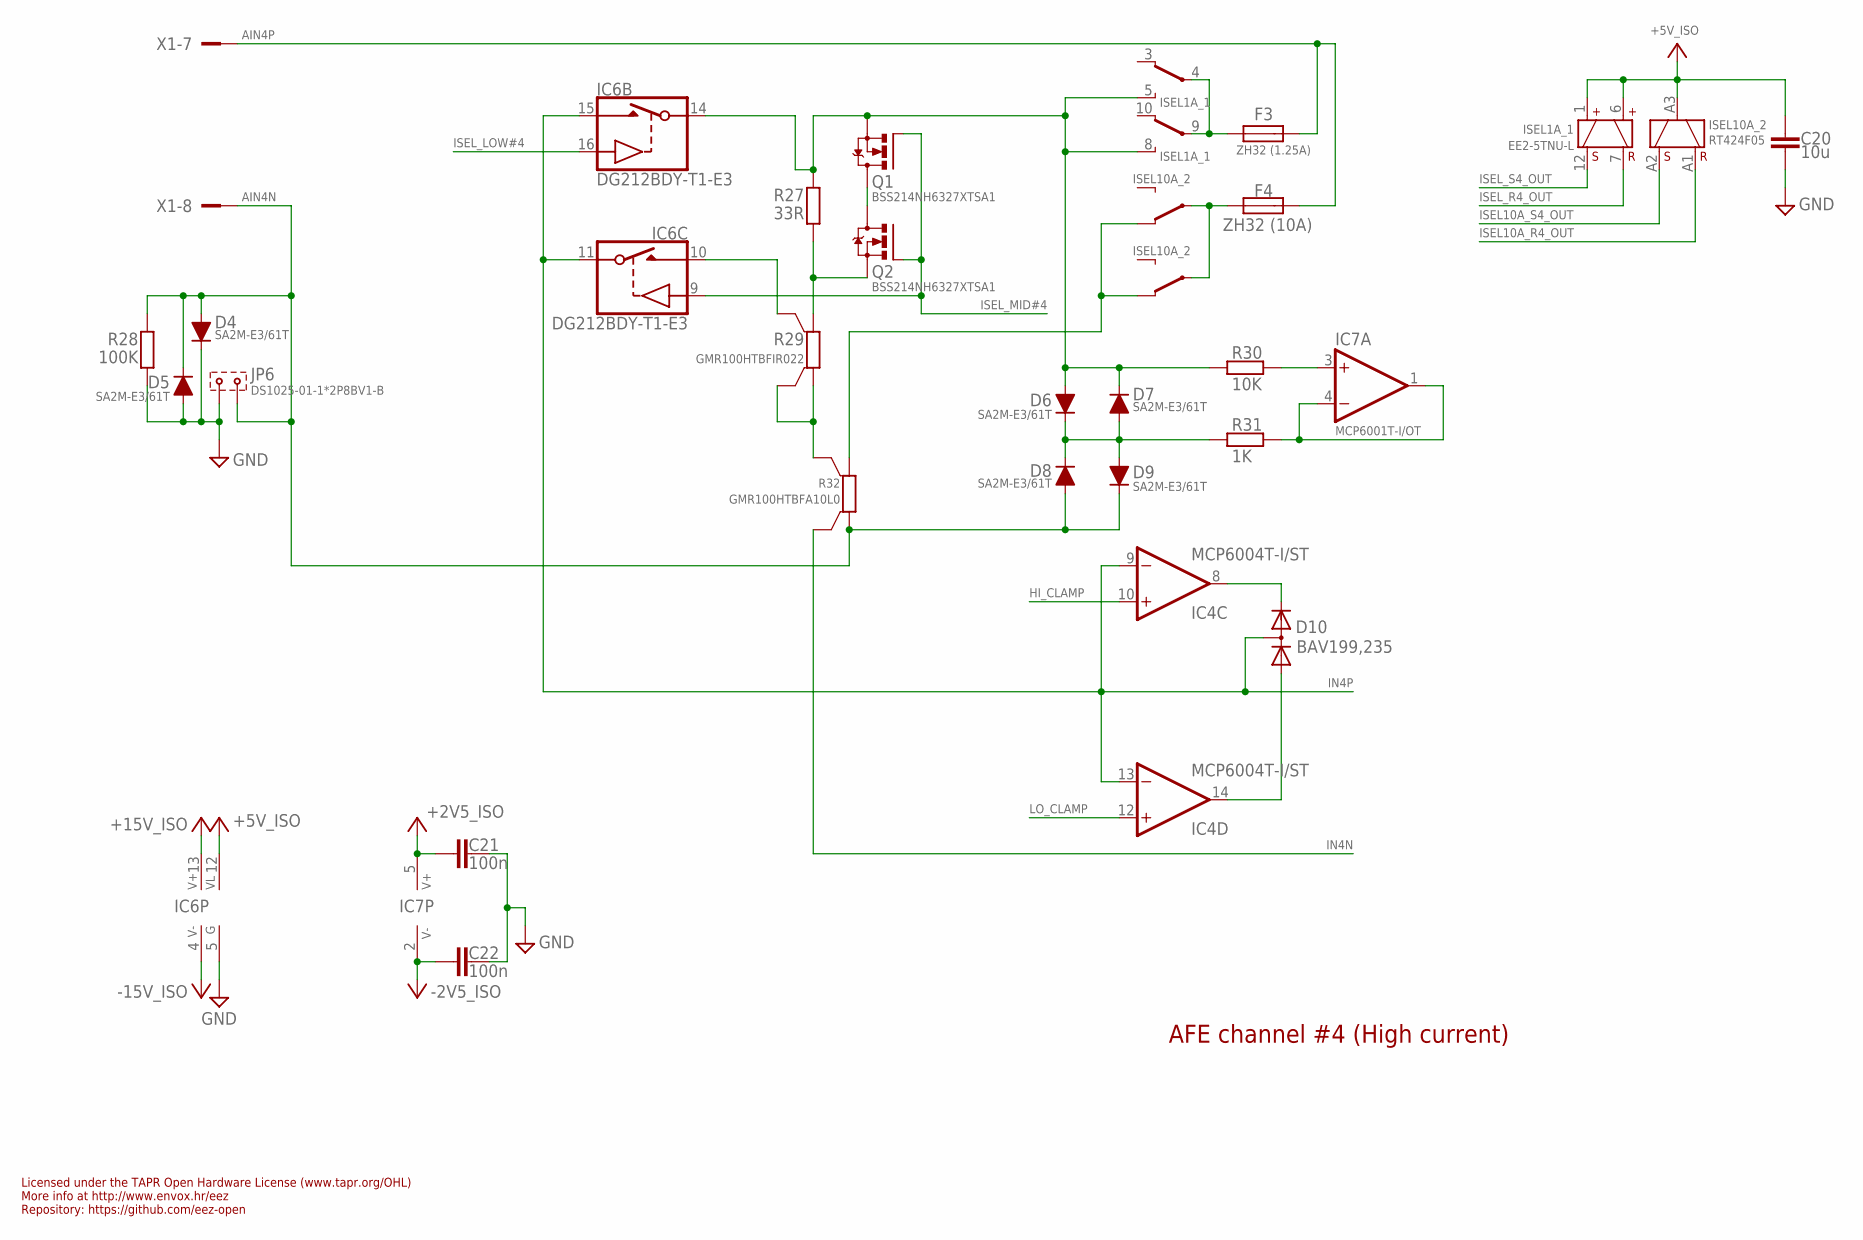
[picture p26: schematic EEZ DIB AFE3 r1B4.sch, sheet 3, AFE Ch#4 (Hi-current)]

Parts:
C20: 10u; C1206
C21, C22: 100n; C0603
D4, D5, D6, D7, D8, D9: SA2M-E3/61T; SMA_NARROW
D10: BAV199,235; SOT23
F3: ZH32 (1.25A); ZH32
F4: ZH32 (10A); ZH32
IC4: MCP6004T-I/ST; PW(R-PDSO-G14)
IC6: DG212BDY-T1-E3; SO16
IC7: MCP6001T-I/OT; DBV5
ISEL1A_1: EE2-5TNU-L; G6SK-2F
ISEL10A_2: RT424F05; RT424FXX
JP6: DS1025-01-1*2P8BV1-B; 2MM-2
Q1: BSS214NH6327XTSA1; SOT103P240X110-3N; MPN 2N7002-7-F
Q2: BSS214NH6327XTSA1; SOT103P240X110-3N
R27: 33R; R1206
R28: 100K; R1206
R29: GMR100HTBFIR022; R_2512-4WIRE
R30: 10K; R0805
R31: 1K; R0805
R32: GMR100HTBFA10L0; R_2512-4WIRE
X1: 691322310008

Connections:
+2V5_ISO: C21.2, IC7.5 (V+); also elsewhere on the board
+5V_ISO: C20.1, IC6.12 (VL), ISEL1A_1.1 (S+), ISEL1A_1.6 (R+), ISEL10A_2.A3 (COM); also elsewhere on the board
+15V_ISO: IC6.13 (V+); also elsewhere on the board
-2V5_ISO: C22.2, IC7.2 (V-); also elsewhere on the board
-15V_ISO: IC6.4 (V-); also elsewhere on the board
AIN4N: D4.2 (A), D5.1 (C), D8.2 (A), D9.1 (C), JP6.1, R28.2, R32.1, X1.8
AIN4P: F3.2, F4.2, X1.7
AIN4P_FUSED: F3.1, ISEL1A_1.4 (COM), ISEL1A_1.9 (COM)
GND: C20.2, C21.1, C22.1, D4.1 (C), D5.2 (A), IC6.5 (GND), JP6.2, R28.1; also elsewhere on the board
HI_CLAMP: IC4.10 (+IN); also elsewhere on the board
HI_CURR#1: ISEL10A_2.12 (NC), ISEL10A_2.22 (NC), R32.2
IN4N: R32.1S; also elsewhere on the board
IN4P: D10.3 (AC), IC4.9 (-IN), IC4.13 (-IN), IC6.11 (S), IC6.15 (D); also elsewhere on the board
ISEL10A_R4_OUT: ISEL10A_2.A1 (R); also elsewhere on the board
ISEL10A_S4_OUT: ISEL10A_2.A2 (S); also elsewhere on the board
ISEL_LOW#4: IC6.16 (IN); also elsewhere on the board
ISEL_MID#4: IC6.9 (IN), Q1.1 (G), Q2.1 (G); also elsewhere on the board
ISEL_R4_OUT: ISEL1A_1.7 (R-); also elsewhere on the board
ISEL_S4_OUT: ISEL1A_1.12 (S-); also elsewhere on the board
LO_CLAMP: IC4.12 (+IN); also elsewhere on the board
unnamed: R29.1, R29.1S, R32.2S
unnamed: IC6.10 (D), R29.2S
unnamed: F4.1, ISEL10A_2.11 (COM), ISEL10A_2.21 (COM)
unnamed: Q1.3 (D), Q2.3 (D)
unnamed: Q2.2 (S), R27.1, R29.2
unnamed: D6.1 (C), D7.2 (A), D8.1 (C), D9.2 (A), R31.2
unnamed: D6.2 (A), D7.1 (C), IC6.14 (S), ISEL1A_1.5 (NO), ISEL1A_1.8 (NO), Q1.2 (S), R27.2, R30.2
unnamed: IC7.1 (OUT), IC7.4 (-IN), R31.1
unnamed: IC7.3 (+IN), R30.1
unnamed: D10.2 (C), IC4.8 (OUT)
unnamed: D10.1 (A), IC4.14 (OUT)

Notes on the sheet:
Licensed under the TAPR Open Hardware License (www.tapr.org/OHL)
Repository: https://github.com/eez-open
More info at http://www.envox.hr/eez
AFE channel #4 (High current)

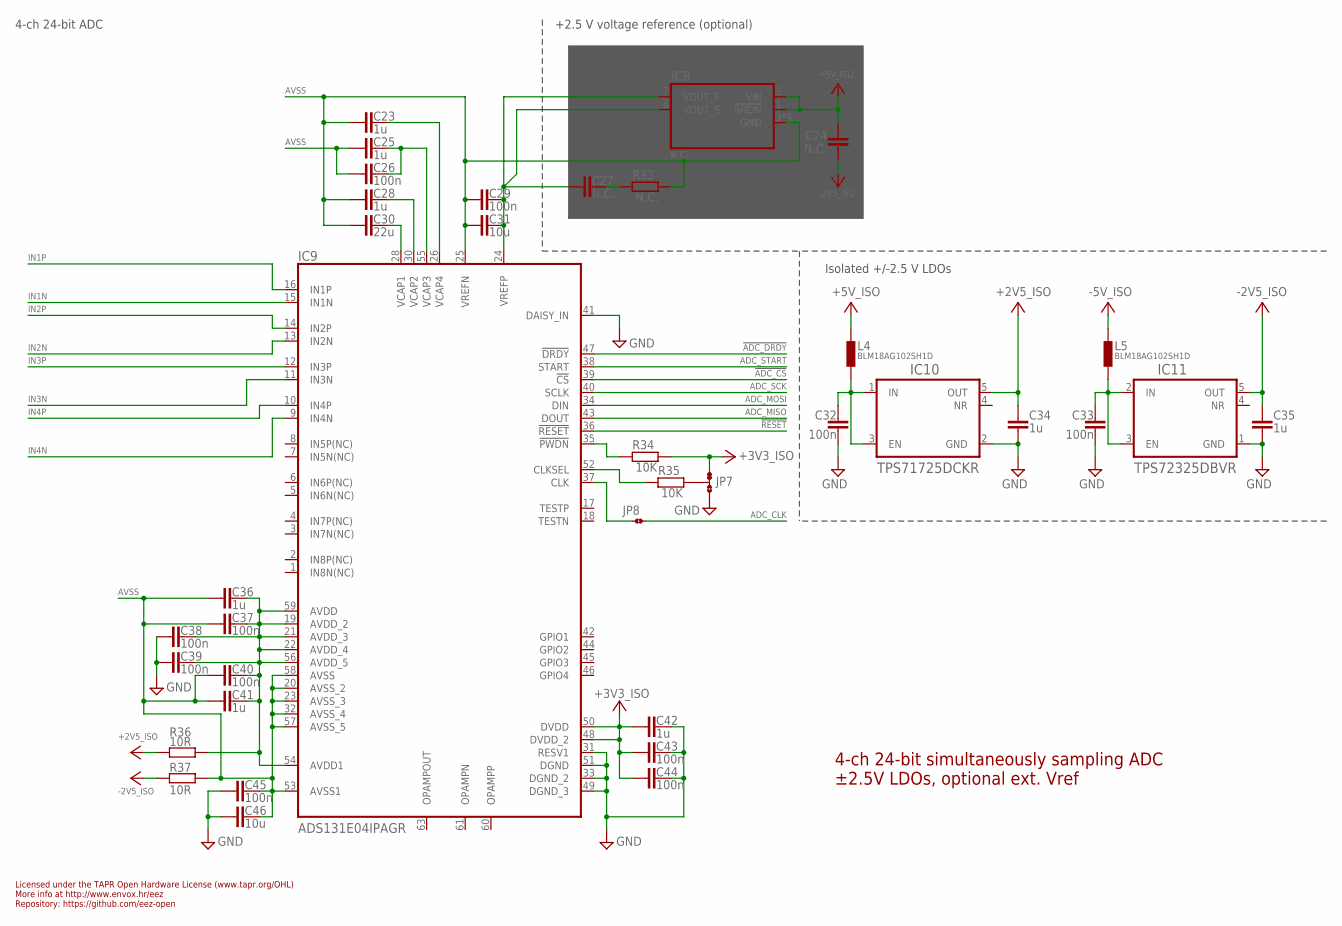
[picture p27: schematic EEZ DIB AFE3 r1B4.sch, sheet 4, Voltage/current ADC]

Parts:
C23, C25, C28, C34, C35, C36, C41, C42: 1u; C0805
C24, C27: N.C.; C1206
C26, C29, C32, C33, C37, C38, C39, C40, C43, C44, C45: 100n; C0603
C30: 22u; C1206
C31, C46: 10u; C1206
IC8: N.C.; MSOP-8_MS_LIT
IC9: ADS131E04IPAGR; PAG64
IC10: TPS71725DCKR; DCK5
IC11: TPS72325DBVR; DBV5
JP7: JP3-CUT-0805-ROTATED; JP3-0805-CUT2
JP8: JP2-CUT-0805; R_0805
L4, L5: BLM18AG102SH1D; BEAD0603
R33: N.C.; R0805
R34, R35: 10K; R0805
R36, R37: 10R; R0805

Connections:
!ADC_CS: IC9.39 (!CS); also elsewhere on the board
!ADC_DRDY: IC9.47 (!DRDY); also elsewhere on the board
!RESET: IC9.36 (!RESET); also elsewhere on the board
+2V5_ADC: C36.2, C37.1, C38.1, C39.1, C40.1, C41.2, IC9.19 (AVDD_2), IC9.21 (AVDD_3), IC9.22 (AVDD_4), IC9.54 (AVDD1), IC9.56 (AVDD_5), IC9.59 (AVDD), R36.2
+2V5_ISO: C34.2, IC10.5 (OUT), R36.1; also elsewhere on the board
+3V3_ISO: C42.1, C43.2, C44.2, IC9.48 (DVDD_2), IC9.50 (DVDD), JP7.NC, R34.2; also elsewhere on the board
+5V_ISO: C24.1, IC8.1 (!SHDN), IC8.2 (VIN), L4.P$2 (2); also elsewhere on the board
-2V5_ISO: C24.2, C35.2, IC11.5 (OUT), R37.2; also elsewhere on the board
-5V_ISO: L5.P$2 (2); also elsewhere on the board
ADC_CLK: JP8.1; also elsewhere on the board
ADC_MISO: IC9.43 (DOUT); also elsewhere on the board
ADC_MOSI: IC9.34 (DIN); also elsewhere on the board
ADC_SCK: IC9.40 (SCLK); also elsewhere on the board
ADC_START: IC9.38 (START); also elsewhere on the board
AVSS: C23.1, C25.1, C26.2, C28.1, C29.2, C30.1, C31.2, C36.1, C37.2, C40.2, C41.1, C45.1, C46.1, IC8.3 (GND), IC8.4 (GND), IC8.5 (GND), IC8.8 (GND), IC9.20 (AVSS_2), IC9.23 (AVSS_3), IC9.25 (VREFN), IC9.32 (AVSS_4), IC9.53 (AVSS1), IC9.57 (AVSS_5), IC9.58 (AVSS), R33.2, R37.1
GND: C32.2, C33.2, C34.1, C35.1, C38.2, C39.2, C42.2, C43.1, C44.1, C45.2, C46.2, IC9.31 (RESV1), IC9.33 (DGND_2), IC9.41 (DAISY_IN), IC9.49 (DGND_3), IC9.51 (DGND), IC10.2 (GND), IC11.1 (GND), JP7.NO; also elsewhere on the board
IN1N: IC9.15 (IN1N); also elsewhere on the board
IN1P: IC9.16 (IN1P); also elsewhere on the board
IN2N: IC9.13 (IN2N); also elsewhere on the board
IN2P: IC9.14 (IN2P); also elsewhere on the board
IN3N: IC9.11 (IN3N); also elsewhere on the board
IN3P: IC9.12 (IN3P); also elsewhere on the board
IN4N: IC9.9 (IN4N); also elsewhere on the board
IN4P: IC9.10 (IN4P); also elsewhere on the board
unnamed: IC9.52 (CLKSEL), R35.1
unnamed: C32.1, IC10.1 (IN), IC10.3 (EN), L4.P$1 (1)
unnamed: C33.1, IC11.2 (IN), IC11.3 (EN), L5.P$1 (1)
unnamed: JP7.COM, R35.2
unnamed: C30.2, IC9.28 (VCAP1)
unnamed: C28.2, IC9.30 (VCAP2)
unnamed: C25.2, C26.1, IC9.55 (VCAP3)
unnamed: C23.2, IC9.26 (VCAP4)
unnamed: IC9.37 (CLK), JP8.2
unnamed: IC9.35 (!PWDN), R34.1
unnamed: C27.2, R33.1
VREFP: C27.1, C29.1, C31.1, IC8.6 (VOUT_S), IC8.7 (VOUT_F), IC9.24 (VREFP)

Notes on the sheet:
Licensed under the TAPR Open Hardware License (www.tapr.org/OHL)
Repository: https://github.com/eez-open
More info at http://www.envox.hr/eez
4-ch 24-bit simultaneously sampling ADC ±2.5V LDOs, optional ext. Vref
4-ch 24-bit ADC
+2.5 V voltage reference (optional)
Isolated +/-2.5 V LDOs

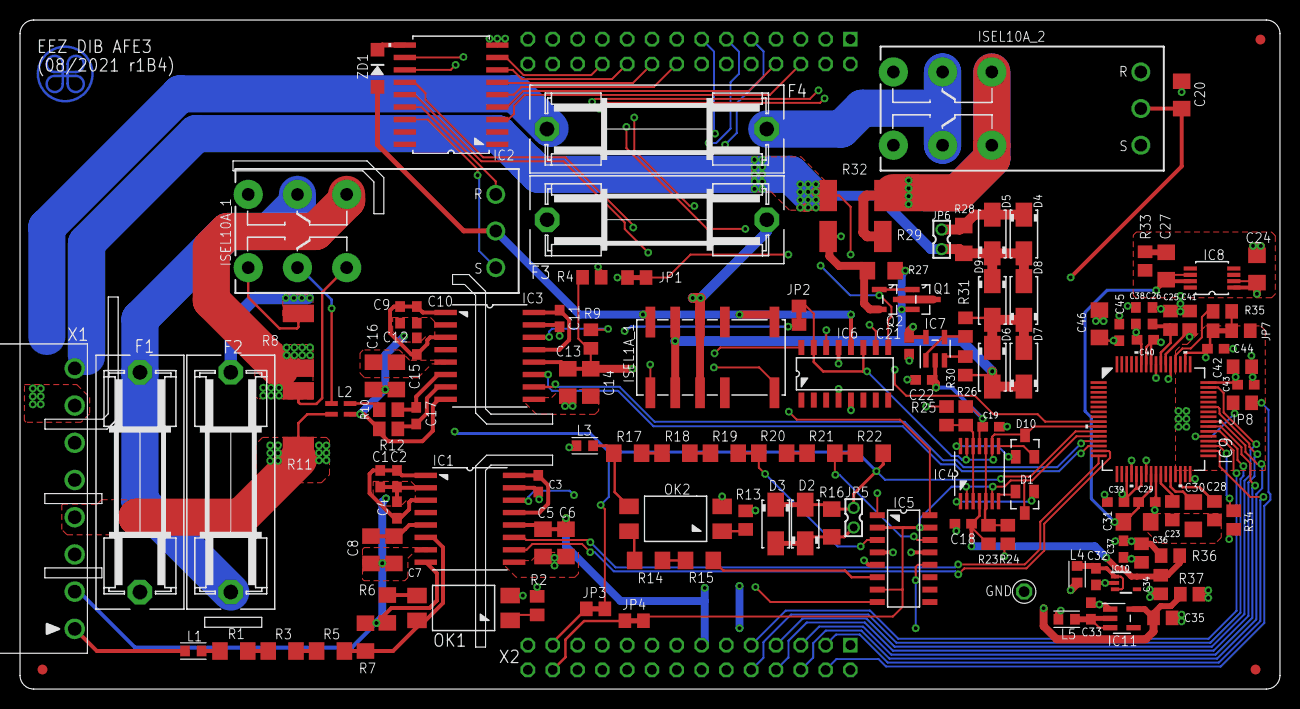
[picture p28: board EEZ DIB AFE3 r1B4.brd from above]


Board: 4 copper layers, 129.0 x 68.5 mm, 137 parts (2 on the bottom side), 120 nets.

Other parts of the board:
EEZ_SIGNATURE: SIGNATURESMALL; SIGNATURE_5MM

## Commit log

2021-05-07 r1B2 (removed RC from ADC inputs)
    [EEZ DIB AFE3 r1B1_centroid.csv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]
2021-05-14 New Rsense values, PCB layout adjustment for mid range Rsense
    [EEZ DIB AFE3 r1B1 BOM.ods, EEZ DIB AFE3 r1B3 BOM.ods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]
2021-05-14 R30 value corrected
    [EEZ DIB AFE3 r1B3 BOM.ods, EEZ DIB AFE3 r1B3.brd, EEZ DIB AFE3 r1B3.sch]
2021-09-29 Gerbers, BOM, schematics update
    [EEZ DIB AFE3 r1B3 BOM.ods, EEZ DIB AFE3 r1B3_centroid.csv, EEZ DIB AFE3 r1B4 BOM.ods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]
2024-01-19 #6, #7 (r1B3 KiCad)
    [ADIB_PWM.kicad_sch, DIB_interface.kicad_sch, Digital_inputs.kicad_sch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]
2024-01-19 Revert "#6, #7 (r1B3 KiCad)"
    This reverts commit 52033645fb07d7287d4da63e50f45c25d80231af.
    [ADIB_PWM.kicad_sch, DIB_interface.kicad_sch, Digital_inputs.kicad_sch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]
2024-01-19 Migration to KiCad
    [AFE_Ch#3_(hi-voltage).kicad_sch, AFE_Ch#4_(Hi-current).kicad_sch, EEZ DIB AFE3 r1B4 BOM.ods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]
2024-01-20 PCB preview correction

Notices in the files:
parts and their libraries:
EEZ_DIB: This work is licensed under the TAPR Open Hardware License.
